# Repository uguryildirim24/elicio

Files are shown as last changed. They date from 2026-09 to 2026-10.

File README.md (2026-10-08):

# Elicio

Elicio is an unfinished ear-muscle EMG earpiece that is intended to turn a deliberate contraction into a gated event before an AI acts.

Rolf chose a discreet physical input rather than an always-active command channel. The sensor should propose an event. Policy should decide whether that event can act. Sensing, permission and execution remain separate.

```text
ear-muscle EMG -> decoder -> (symbol, confidence, timestamp) -> policy -> action
```

**The board is not finished, has not been ordered and is unmeasured.** No physical earpiece, real ear-muscle recording or end-to-end biological action has been validated. The runnable demonstrations use synthetic input. Only a harmless local file action is real. No AI execution adapter is implemented.

## What exists

| Part | Files and present evidence |
| --- | --- |
| Flex board | [KiCad schematic](hardware/board/elicio-v4.kicad_sch), [routed PCB](hardware/board/elicio-v4.kicad_pcb), project rules and generation/routing scripts. Design files are not manufacturing approval. |
| Scripted shell | [Selected snap-shell exports](docs/fab/cad/v4-snap/) include STEP, STL, 3MF and a nominal-check manifest. No print, fit or retention result. |
| Firmware | [Arduino stream firmware](firmware/elicio_stream/elicio_stream.ino) and C sources for ADS1292 acquisition, binary BLE frames and undervoltage handling. The product Arduino variant is missing. |
| Receiver | Binary frame decoding, dropout/loss records and session files. Committed synthetic transport fixtures run without a radio. |
| Action gate | Confidence policy, confirmation state, intent/result auditing and an atomic local marker write. Other action names are console simulations. |
| Research pipeline | Public forearm sEMG preparation and cross-session evaluation code. No result CSVs, checkpoints or measured accuracy reports are bundled. |

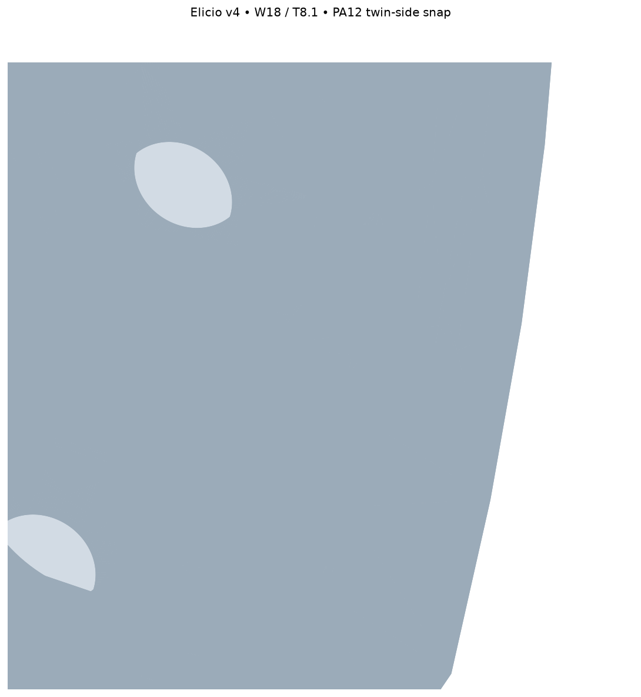
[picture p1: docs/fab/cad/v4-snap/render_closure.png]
Selected snap-shell CAD preview, not a physical device


The snap manifest records **106 passing nominal geometry checks**. These cover simplified board courtyards, a folded-flap envelope, seated overlap, key clearance and opposing tolerance offsets. They do not prove printed fit, latch fatigue, component loads, electrical safety or RF range. The nominal body is 18 mm wide and 8.1 mm thick, not the complete hook bounding box. See [shell limits](docs/fab/shell-v4.md) and [board blockers](docs/fab/board-v4-design.md).

## Run from a clean clone

Run these commands from the repository root on macOS or Linux. Use Python **3.11 or newer**. The base install requires NumPy. No credentials or hardware are needed for the demos.

```bash
python3 --version
python3 -m venv .venv
.venv/bin/python -m pip install -e .
.venv/bin/elicio demo --state-dir .elicio-demo
.venv/bin/elicio replay-demo --state-dir .elicio-replay-demo
```

Each demo must exit 0 and print `"verified": true`. It writes a marker under `actions/` and linked `intent` and `result` records in `audit.jsonl` inside its ignored state directory. The replay fixture is seeded synthetic data, not an EMG recording or a hardware test.

### Binary receiver without hardware

```bash
.venv/bin/elicio receive --simulate tests/fixtures/receiver_v2/normal.json \
    --out recordings/synthetic-session
.venv/bin/elicio receive-check recordings/synthetic-session
```

`receive` writes `samples.npz`, `sidecar.json` and `meta.json`. `receive-check` reports acquisition statistics and criterion status; the normal fixture exits 0 with `"ok": true`. Its gesture criteria are `not_scored`, not passed. This is transport validation, not gesture decoding or a connection to the action gate.

The intended radio path uses binary frame-v2 messages over Nordic UART Service, not ASCII serial samples. Live reception requires the optional BLE dependency and future functioning hardware:

```bash
.venv/bin/python -m pip install -e '.[ble]'
.venv/bin/elicio receive --device ELICIO --seconds 10 --out recordings/bench-session
.venv/bin/elicio receive-check recordings/bench-session
```

The live commands are not usable or validated with this unfinished board. The firmware deliberately rejects a Feather pin variant. See [firmware limits](docs/fab/firmware-v2.md), [frame format](docs/fab/frame-v2.md) and [receiver contract](docs/fab/receiver-v2.md).

The separate `scope`, `capture` and `replay-recording` tools accept one ASCII sample per line from a file, stdin or an already configured serial device. They are bench utilities, not the binary BLE path. Store captures under ignored `recordings/`, for example `--out recordings/session.json`. Run `elicio capture --help` for the sample-rate, offset and gain arguments.

### Existing tests

```bash
.venv/bin/python -m unittest discover -s tests -v
```

The scope review ran the base install, both synthetic action demos and the normal receiver fixture in the worktree with Python 3.13.15. They exited 0. Both demos reported `verified: true`; the receiver check reported `ok: true` with gesture criteria unscored.

The full existing suite was attempted but stopped at a 180-second command limit while setting up the restored packing checks. A historical document wording assertion failed before that point. Its expected reference wording was restored, and that existing test passed when rerun alone. The documented `bte_fit_shell.py --checks-only` reference check and `elicio capture --help` also passed. No complete suite pass is claimed. The original tests and historical-byte comparisons remain unchanged. No tests or CI were added.

Optional dependency groups are `research`, `ble`, `cad` and `sheets`. Install an extra with, for example, `.venv/bin/python -m pip install -e '.[cad]'`. Native C checks use a compiler when available. KiCad/pcbnew, firmware tooling, Blender or SceneKit are separate toolchains. Optional CAD exports, rendering, KiCad release validation, firmware flashing and live acquisition were not rerun during the scope review. Research downloads and training were skipped as substantial workloads.

## Research and local data

The research package fetches public PhysioNet/WFDB GRABMyo records. It studies forearm gestures, not auricular decoding. From the repository root:

```bash
.venv/bin/python -m pip install -e '.[research]'
.venv/bin/elicio-emg prepare --subjects 1 2 3 --out-dir results
.venv/bin/elicio-emg train --data-dir results --subjects 1 2 3 \
    --epochs 20 --out results/train_results.csv
.venv/bin/elicio-emg evaluate --data-dir results --subjects 1 2 3 \
    --epochs 20 --out results/six_best_rest.csv
```

These are download and training workloads, not quick demos. They were not rerun during cleanup. Training is not fully seeded. Evaluation uses separate recording sessions and a leakage guard. Earlier imported accuracy summaries lack supporting result artifacts here and are not claimed as repository results. See the [pipeline instructions](src/elicio/pipeline/README.md) and [provenance limits](docs/RESEARCH_PROVENANCE.md).

Keep raw recordings in `recordings/`, research outputs in `results/`, anatomy parameters in `measurements/` and generated CAD/release output in `.reports/`. These directories, environments, checkpoints, secrets and runtime state are ignored. Tracked binary fixtures are synthetic. No completed personal ear measurements or purchase records are included. Do not put delivery addresses, checkout details or credentials in public examples.

## Limits and next steps

- Confidence thresholds are policy settings, not calibrated biological probabilities.
- The timed `jaw_clench` confirmation rule checks symbols, confidence and timestamps. The event tuple cannot prove that command and confirmation came from independent muscle groups. That is an unvalidated upstream requirement.
- Intent audit failure blocks execution. A result-audit failure after execution is reported without hiding the completed action.
- There is no trained ear-muscle decoder, real signal-to-action result or AI execution adapter.
- The circuit, cell, charging protection, RF keep-out, programming path and manufacturing acceptance remain open. CAD and a clean DRC claim cannot establish on-body safety.
- This is not a medical device or a finished wearable. Do not wear or charge unvalidated electronics on a body.

Next: resolve electrical and fabrication blockers, implement the product firmware variant, validate passive printed fit and repeated latch retention, then record a real signal and demonstrate one harmless audited action. See [design status](docs/EARPIECE_DESIGN.md) and [open gates](docs/fab/open-questions.md).

## Project layout

| Path | Purpose |
| --- | --- |
| `src/elicio/harness/` | Events, policy, adapters and audit |
| `src/elicio/signal/` | Synthetic replay, detection and ASCII capture |
| `src/elicio/frame_v2.py`, `receiver_v2.py` | Binary BLE transport and session reception |
| `src/elicio/pipeline/` | Public-data research pipeline |
| `hardware/board/` | KiCad sources, custom footprints and board scripts |
| `firmware/` | Acquisition, framing and power-state sources |
| `scripts/cad/`, `scripts/sheets/` | Parametric CAD, previews and reference templates |
| `docs/fab/cad/v4-snap/` | Selected shell candidate and nominal evidence |
| `tests/` | Existing unit checks and synthetic transport fixtures |
| `docs/` | Design limits, provenance and engineering references |

Older v1/v2 geometry, packing tables, layout searches, board-edit scripts and their existing checks remain. They are reference inputs and development tools, not active ordering instructions. `placement.py` still supports `--packing-doc`, `--layout-v2` and `--layout-v2c`. Some older readers use pinned Git revisions. They are not independent of repository history, and history scrubbing can invalidate those references. The technical L1 to L8 source surveys remain with historical notices. The [reference index](docs/fab/references.md) lists key public sources. Task and review dialogue is omitted.

The rejected M1.6 closure remains as diagnostic code and evidence in `docs/fab/cad/v4-m16/`. It is not suitable for printing. The snap candidate is still untested physically. Private agent diaries, personal parameter scaffolding and superseded shopping sheets were removed. Historical budgets are estimates, not quotes or personal spending statements.

## How this was built

AI coding agents did much of the research migration, harness and receiver implementation, firmware, CAD and board work under Rolf's direction. Rolf set the physical-gating goal, chose the earpiece form, titanium contacts, limited final assembly and off-ear-only charging, and reviewed design previews. The checks reported here are automated software and nominal geometry checks. Agent-written engineering claims are not independent electrical review or physical measurements. No hardware result has been measured.

## License and citation

Original project code, hardware design files and documentation are offered under [MIT](LICENSE). The bundled Liberation Sans font is separate: SIL Open Font License 1.1, with Google and Red Hat attribution in [the font notice](scripts/cad/fonts/OFL.txt). External datasets, dependencies and vendor materials retain their own terms.

No Elicio paper or preprint is included in this repository. Public engineering source pointers are in [references](docs/fab/references.md).

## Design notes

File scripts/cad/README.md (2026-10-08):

# Scripted shell CAD

The selected candidate is the committed `docs/fab/cad/v4-snap/` body and lid. The board is unfinished and unordered. No shell has been printed or fit-validated.

## Install and generate

From the repository root with Python >=3.11:

```bash
python3 -m venv .venv
.venv/bin/python -m pip install -e '.[cad]'
.venv/bin/python scripts/cad/build_shell_v4.py --closure snap --out .reports/cad/v4-snap
.venv/bin/python scripts/cad/render_v4.py --single --out .reports/cad/v4-snap
```

All generated output belongs under ignored `.reports/cad/`. Do not overwrite tracked reference exports during routine checks. The CAD extra pins the kernel used for geometry exports. Library versions can still change render bytes. Regeneration is not physical validation.

`build_shell_v4.py` reads board courtyard envelopes from `docs/fab/board-v4-design.md` section 10.2. Its manifest records nominal geometry and key-clearance checks. The base `--closure hinge` is a reference without lid retention. `--closure m16` remains a diagnostic prototype. Its 0.13 mm head-well wall rejects it for printing. Committed M1.6 exports remain as evidence, not a print candidate.

See [shell limits](../../docs/fab/shell-v4.md) for print and load questions.

## Reference fixtures

`bte_fit_shell.py`, `placement.py`, `placement_v2.py` and `layout_v2c.py` retain the original construction, packing searches and document generator. The older PCB reader uses revision `70adfa6` for board dimensions and project rules. J4 geometry prefers revision `6860a54`. Shell readers prefer pinned packing revisions. These are read-only Git operations, but the inputs depend on history. A history rewrite can invalidate them. They must not be replaced by a later PCB without checking the changed geometry and rules.

The v1/v2 solids, matrix drawings, v2c grid drawings and packing tables remain reference inputs. The earlier shell reader combines section 5c courtyards and holes with section 5d folded pads and extras. Section 5e supplies the later wall-site geometry. The v4 generator reads `board-v4-design.md`, not either older placement table. Superseded fit-gauge ordering instructions do not define the current build. Historical technical source surveys L1 to L8 remain. `docs/fab/references.md` indexes key sources. Private task and review dialogue is not included.

`placement.py` retains `--packing-doc`, `--layout-v2` and `--layout-v2c`. The first regenerates tracked `docs/fab/packing-v2.md`; the grid option writes its reference drawings. Run these only when deliberately regenerating the references. Matrix drawing options are `--all`, `--kept-drawings` and `--all-drawings`, with `--out-dir` for a separate output directory. The full grid and document searches can be lengthy.

Existing tests still compare regenerated CAD and render bytes with committed hashes. Kernel versions, Git provenance and rendering dependencies can affect those comparisons. The scope review did not weaken those checks or claim a complete suite pass.

A reference-only check without the CAD kernel:

```bash
.venv/bin/python scripts/cad/bte_fit_shell.py --checks-only
```

A new reference export, with the CAD extra installed:

```bash
.venv/bin/python scripts/cad/bte_fit_shell.py --out .reports/cad/reference
```

The default M1 to M8 dimensions are examples. They are not Rolf's measurements. Put any later anatomy overlay under ignored `measurements/`, then pass its path through `--params`. Do not fill a tracked parameter file with personal measurements. Check supported parameters with `--help`. The full v4 folded fit must be re-evaluated after parameter changes.

## Optional assembly visualizations

`assemble_native.py` uses SceneKit/Swift on macOS or Blender on Linux. It also needs Pillow. It reads the committed shell STL and board data and generates simplified curved board and package envelopes, not a folded physical assembly.

```bash
.venv/bin/python -m pip install Pillow
.venv/bin/python scripts/cad/assemble_native.py --out .reports/cad/assembly
```

`assemble_photo.py` provides a Blender render path. Rendering also uses read-only git provenance. These pictures do not prove clearances, package tolerances, RF performance or manufacturability. Preview generation was not rerun during publication cleanup.

## Font

`fonts/LiberationSans-Regular.ttf` is bundled for CAD embossing. Its separate SIL Open Font License 1.1 and attribution are in `fonts/OFL.txt`. The project MIT license does not replace that notice.

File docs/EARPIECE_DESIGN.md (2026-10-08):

# Earpiece design status

Elicio is Rolf's unfinished behind-the-ear EMG earpiece. The board has not been ordered. No assembled hardware, real recording, on-body result or validated charging interface exists.

## Current candidate

| Part | Files | Evidence and limits |
| --- | --- | --- |
| Two-layer flex board | `hardware/board/elicio-v4.kicad_sch`, `.kicad_pcb`, `.kicad_pro`, `.kicad_dru` | Routed design snapshot. Manufacturing, electrical and supply checks remain open. |
| Shell | `docs/fab/cad/v4-snap/` | STEP, STL, 3MF, preview and nominal geometry checks. No printed fit or retention test. |
| Base shell | `docs/fab/cad/v4/` | Reference geometry with a hinge only. It does not retain the lid. |
| Firmware | `firmware/elicio_stream/elicio_stream.ino`, `firmware/src/` | ADS1292 acquisition, binary BLE framing and undervoltage logic. Product Arduino pin variant is missing. |
| Receiver | `src/elicio/receiver_v2.py` | Synthetic frame decoding, loss handling and session output. No live radio validation. |
| Action gate | `src/elicio/harness/` | Synthetic event and replay demonstrations with a real local file action. No AI adapter. |

The proposed board uses an ISP1807-LR radio module, ADS1292 front end, BQ25100 charger and a fitted protected cell. The selected shell has a nominal 18 mm body width and 8.1 mm body thickness. These are CAD dimensions, not measurements of a worn device. See [board design](fab/board-v4-design.md) and [snap-shell status](fab/shell-v4.md).

## Engineering constraints

Rolf selected discreet auricular muscle input rather than an overt forearm gesture as the intended product interface. Forearm data remains a research and bench-development path, not a validation of the earpiece.

The contact hardware is specified as titanium. Material, finish, pressure, insulation and retention still need review. Shell parameters are reference examples, not personal anatomy measurements. Keep any later measurements under ignored `measurements/`.

Charging is intended to happen off-ear only. The proposed fixed TS resistor disables cell-temperature sensing. Firmware inhibits are not galvanic isolation. Series resistors alone do not establish safe fault currents or medical compliance. Do not connect unvalidated electronics to a body. Bench electrical checks and qualified safety review must precede on-body work.

## What is not implemented

- A product-specific Arduino variant and verified bootloader/programming path.
- Validated battery pack, polarity, charge cable, temperature conditions and transient protection.
- Physical shell fit, repeated snap operation, contact stability and RF range.
- A trained auricular decoder or a measured independent confirmation channel.
- Ear-canal pressure sensing or EEG acquisition. These were exploratory ideas, not built subsystems.
- Real AI execution. Only the local marker adapter changes a file.

## Next steps

1. Review the actual routed board, component supply, charging protection and fabrication constraints. Re-run KiCad release validation after any change. Resolve the blockers in [open questions](fab/open-questions.md).
2. Implement the ISP1807 product firmware variant. Verify GPIO mapping, first-load voltage levels, acquisition timing and the hardware interlock on the bench.
3. Evaluate a passive shell print. Check fit, latch access, repeated retention and contact positions before including powered electronics.
4. After electrical and physical review, preserve a real raw recording in ignored `recordings/`. Show one contraction producing one harmless marker action with linked audit records.

Historical v1/v2 geometry and packing tables remain because the current generator and existing checks depend on them. They are references, not alternative checkout instructions. Superseded order sheets have been removed. Rejected M1.6 closure code and exports remain as diagnostic evidence, not a fabrication candidate.

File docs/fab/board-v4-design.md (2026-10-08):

# Board v4 — design note (smaller body)

Draft. **Routed, not orderable yet**: DRC 0 errors and 0 unconnected after a zone refill, and `scripts/board/release.py --board elicio-v4 --routed` passes (§9), but some parts still require verified external supply (`bom-v4-orderable.md`). U3 now has DC-bias-characterized IN/TS/OUT capacitors meeting the numerical IEC rating conditions, but D1 still clamps at the far end of VBUS and the nearest OUT bulk is 9.3 mm from U3; the conditional IC rating is not a contact-level test (§2.1). Rolf chose off-ear-only charging with fixed TS and a two-wire J2 (no cell NTC); the antenna keep-out still needs his decision (§4.2). The later built snap shell is a print-trial solid, not a verified fit; see `shell-v4.md`. §11.1 lists what is still UNVERIFIED.
Design snapshot: 2026-09-25. AI coding agents produced the design and routing records under Rolf's direction. Reported KiCad release counts below are historical claims, not a freshly reproduced manufacturing release. The board is unfinished and has not been ordered.

## 1. Size levers

Frame: u = width (anterior 0 → posterior), s = arc from the hook end, y = thickness from the skin face. All sizes in mm. Flat PCB (x, y) = (u, s).

Baseline v2: W 22, T 9.0 (LID_Y 8.0 + lid 1.0), chord 47.90. The M1 gate is M1 ≥ chord + 3 = 50.9. Default M1 is a 52 mm reference example, not a personal measurement.

"W/L/T saved" is the body dimension saved. Where a lever only frees board area, the area is given instead, as courtyard mm². The area levers together are what let the island shrink from 17.5 to 13.5 wide.

### 1.1 Lever table

| # | Lever | W saved | L saved | T saved | What Rolf gives up | Risk | Cost change | Taken |
|---|---|---|---|---|---|---|---|---|
| L1 | Clear the pocket beside the cell. U2, SW1 and J2 move onto the island. P4/P5 become one-face wall rings on a plate that folds 90° beside the cell (§4.4) | **4.0** (22 → 18) | 0 | 0 | Nothing electrical. Shell changes: a slot in the rib for the flap, and the closure screw moves (§7) | The 90° fold at R 1.1 is exactly JLC's 10× limit. Plate top 6.895 against LID_Y 7.1 | Shell reprint (needed anyway). Board: UNVERIFIED | **Yes** |
| L2 | ISP1807-LR SiP (8 × 8 × 1.0) replaces the Raytac MDBT50Q (15.5 × 10.5 × 2.3) | makes L1's 13.5-wide island possible (courtyard 190 → 74 mm²) | 0 | **0.62** (a Raytac on the v4 island would need T ≈ 8.72) | RF margin: about 13 mm of metal-free edge against the 18 recommended (§4.2). Not in the JLC library, so it must be consigned. No VDDH, so U5 is added | Range is UNVERIFIED until a range test. 0.65-pitch LGA on flex | $14.01 (-ST) / $13.65 (-RS) qty 1, Mouser, https://www.mouser.com/ProductDetail/Insight-SiP/ISP1807-LR-ST, read 2026-09-23. Raytac price UNVERIFIED. Consignment fee UNVERIFIED | **Yes** |
| L3 | Island stiffener FR4 0.4 → 0.2 (one B-side piece under U1, the P2 landing and J4) | 0 | 0 | **0.28** | Nothing | Less stiffness under the lid posts and at the LGA. G7 load not computed | None expected. Stiffener fee: §3.3 | **Yes** |
| L4 | J2: JST-SH (mated 2.95) → Molex Pico-EZmate Slim 202656-0021 (mated 1.20, top entry) | lets J2 sit on the island (part of L1) | 0 | lets J2 fit under LID_Y 7.1 (top 6.32; SH would reach 8.07) | The cell must come with a Pico-EZmate Slim plug fitted by a vendor. R2 forbids Rolf crimping. This changes the G1b/Q69 purchase route | Supply of a cell with that plug is UNVERIFIED | Header and plug prices UNVERIFIED. Not in the JLC library | **Yes** |
| L5 | SW1: TS-1187A (4.5 × 4.5 × 1.6) → HRO 1TS015A (3.0 × 2.0 × 0.6) | area about 42 → 11 mm² | 0 | 0 (top 5.72) | Nothing (1.2 N press) | Low | C398746, 25,177 in stock (https://jlcpcb.com/partdetail/C398746, read 2026-09-23). Price UNVERIFIED | **Yes** |
| L6 | Non-Contact R and C 0402 → 0201. 10 µF 0603 → 0402 | area about 40 mm² (35 parts) | 0 | 0 | Nothing | JLC lists FPC assembly and a 0201 minimum separately. That the two combine on FPC is UNVERIFIED | +$3.00 per new extended part number (L8 §2.2, read 2026-09-18). About 6–12 new lines gives +$18–36 (UNVERIFIED) | **Yes** |
| L7 | Q1–Q4 SOT-23 → DFN1006-3. U4 SOT-23-5 → X2SON-4 | area about 57 mm² | 0 | 0 | Nothing | Q2–Q4 are PMZ290UNE2 (C478155, §2.1 item 4). U4 C2863576 is the same regulator on reel and stocked | Q1 WPM3027-3 C240195. The rest UNVERIFIED | **Yes** |
| L8 | Lid posts replace the two board screws and bosses (H1/H2 go) | area about 17 mm² | 0 | 0 | Nothing. Assembly step 5 ("Turn the board screws") goes | The P2 post presses on U1's top. Force not computed (G7) | None | **Yes** |
| L9 | Drop the DNP parts and the part the SiP makes redundant (Q5, R9, R10, R29, R30, L1) | area about 21 mm² | 0 | 0 | The option to fit R29/R30 lead-off bias later | None | None | **Yes** |
| L10 | Drop R26 (nRESET 10 kΩ pull-up). P0.18 set as RESET has its own pull-up (PS v1.11 §5.3.8.3 tPINR = 5 × 13 kΩ × C; §7.3 reference circuits have no reset resistor) | area about 0.6 mm² and one via | 0 | 0 | Nothing. Firmware must set UICR PSELRESET (§8) | Low | −1 BOM line | **Yes** |
| L11 | Via 0.45/0.20 → 0.40/0.15 (JLC flex standard: hole ≥ 0.15, pad ≥ 0.35, 0.40 recommended) | routing room, not courtyard | 0 | 0 | Nothing | Low: still the standard via | None expected | **Yes** |
| N1 | W16: ISO 4032 M2.5 nuts (m 2.0) replace the 3.0 P4/P5 standoffs | 2.0 (18 → 16.01) | 0 | 0 | Routability. The island would be 11.5 wide | High: W17 already fails to place (N14) | Nut price UNVERIFIED | No |
| N2 | 401012 cell (4.2 × 10.2 × 13.5, 40 mAh) replaces the 501012 | 0 | −0.5 (chord 48.40, M1 ≥ 51.4) | 0.5 (T ≈ 7.6) | 0.5 of length. Same capacity | LID_Y 6.6 is set by the P4/P5 hex (AF 5.0 between floor 1.5 and lid, 0.05 spare each side) and by J2 (6.32 + 0.28). The plate needs a re-cut (plate top 6.895 > 6.6), putting the ring at y ≈ 4.05. The shell must confirm. The cell has flying leads, so the plug must be fitted | €2.74 qty 1, https://ampul.eu/en/battery/6411-li-pol-battery-40mah-37v-401012, read 2026-09-23. Compare 501012 ~$3.50–5.00, https://www.aliexpress.us/item/3256804164251088.html, read 2026-09-23 | Rolf's option |
| N3 | 301012 cell (3.2 × 10.2 × 13.5, 25–30 mAh) | 0 | −0.5 | 0.5 (still 7.6: the hex and J2 set LID_Y) | 10–15 mAh (§1.3) | As N2 | $3.20, https://www.aliexpress.us/item/3256808874133671.html, read 2026-09-23 | No: a pure loss against N2 |
| N4 | 401010 cell (4.2 × 10.2 × 11.5, 30 mAh) | 0 | **1.5** (chord 46.40, M1 ≥ 49.4) | 0.5 (T ≈ 7.6) | 10 mAh (§1.3) | As N2 | $10.00, https://lipolybatteries.com/product/30mah-lipo-battery-lp401010-4mm-thickness-3-7-v-battery, read 2026-09-23 | Only if M1 < 50.9 |
| N5 | T ≈ 7.4: M2 P4/P5 hardware, Hirose DF58 J2 (mated 1.00) and a cell ≤ 4.2 | 0 | per cell | about 0.7 | A second hex key, which breaks plan R2 | New hardware and connector sourcing | UNVERIFIED | No (R2) |
| N6 | Foam 0.5 → 0.3 (plan v2 §3's number; decision 57 chose 0.5) | 0 | 0 | 0.2 (T 7.9) | Cushion under the cell | Plate top 6.895 against LID_Y 6.9: needs a plate re-cut | None | No (decision 57 stands) |
| N7 | 2.0 standoffs at P4/P5 | 0 | 0 | 0 on its own | — | SKU UNVERIFIED (plan §3 verified only 3.0 and 4.0) | UNVERIFIED | No |
| N8 | Full 18 mm antenna keep-out | 0 | **−5** (M1 +5) | 0 | 5 mm of body length | — | — | No: range test instead |
| N9 | ADS1291 (1 channel) | 0 | 0 | 0 | Channel 2: **changes function** | Same RSM 4 × 4 package, so no size gain | C2651548 $12.3149, 1 in stock, https://jlcpcb.com/partdetail/C2651548, read 2026-09-23 | No |
| N10 | MAX30003 (2.74 × 2.93 WLP) | area only | 0 | 0 | 512 SPS max, 18-bit: **changes function** | — | DigiKey page in research §3.3 | No |
| N11 | nRF52840 on the board, not in a module (WLCSP 3.544 × 3.607) | area only | 0 | 0 | The module's certification (FCC ID) | Antenna, crystals and matching on the board. The Johanson 2450AT18A100 needs a 9.5 × 6.2 ground clearance | — | No |
| N12 | u-blox ANNA-B402 (6.5 × 6.5 × 1.2, nRF52833) | area only; needs a host antenna strip and a 32 kHz crystal | 0 | −0.2 against the ISP1807 | Moves from nRF52840 to nRF52833 | The antenna strip takes back the area | $7.22 qty 1, https://www.digikey.com/en/products/detail/u-blox/ANNA-B402-00B/13684241, read 2026-09-23 | No |
| N13 | 4-layer flex | 0 | 0 | 0 | — | 0.20+ thick breaks the R 1.1 and R 1.5 folds (static bend ≥ 10× thickness) | — | No |
| N14 | W17 (the first pick) | 1.0 (18 → 17) | 0 | 0 | Nothing electrical | **Tried; it doesn't place.** B-side room is the limit, not total area (§1.4) | — | No |

### 1.2 Thickness chain

| y top | v2 | v4 (501012) |
|---|---|---|
| Floor | 1.50 | 1.50 |
| Ring (PI 0.11 + FR4 0.2) | 1.81 | 1.81 |
| Standoff 3.0 top = island underside | 4.81 | 4.81 |
| Island stiffener | FR4 0.4 → 5.21 | FR4 0.2 → 5.01 |
| Island PI top | 5.32 | 5.12 |
| Module top | 7.62 (Raytac 2.3) | 6.12 (ISP1807 1.0) |
| J2 mated top | pocket beside the cell | 6.32 (1.20 on the island) |
| SW1 top | pocket | 5.72 |
| Cell: floor 1.5 + foam 0.5 + cell | 7.10 (501012) | 7.10 (501012) |
| LID_Y | 8.00 | **7.10** (set by the cell) |
| T = LID_Y + lid 1.0 | 9.0 | **8.1** |

A Raytac on the v4 island would top out at 7.42. With 0.3 clearance that is T ≈ 8.72, so the ISP1807 saves 0.62 and the thinner stiffener the other 0.28.

### 1.3 Hours of wear (estimate, UNVERIFIED)

The historical runtime model assumes about 7 mA average load. That assumption has no measured current trace or runtime report here. The table is capacity divided by an assumed load, not a result.

| Cell | mAh | Hours at ~7 mA |
|---|---|---|
| 501012 / 401012 | 40 | ≈ 5.7 |
| 401010 | 30 | ≈ 4.3 |
| 301012 | 25–30 | ≈ 3.6–4.3 |

Montage S3 wear is ≤ 4 h/day.

### 1.4 The pick

**W 18, T 8.1, chord 47.90 with the 501012 cell. Needs M1 ≥ 50.9.**

- **W 18** is the narrowest width I could place with every part and a via escape for each B-side net (§6).
  - **W17 was the first pick and failed at placement.** Total fill looked fine (71.4%), but the B side is mostly keep-out: the P1 landing (R 3.2), the U1/P2/J4 stiffener (no B parts) and the RF band (all layers). What's left at W17 is a 3.4 × 4.85 pocket, the area under U2 and a strip along the −s edge. The seven divider and interlock parts (R16, R18–R21, Q2, C14) didn't fit there with room for their vias.
  - The extra 1.0 goes to the posterior column, u 14.75–15.75. That holds R3, R16, the charger on B and the Contact/J3 corridor.
  - W16 needs nuts in place of the P4/P5 standoffs and has less room than W17 (N1).
  - The contacts alone set W ≥ 15.0: the P2 well at u 10.4, plus 3.06, plus a 1.5 wall.
- **T 8.1** is set by the cell stack (1.5 + 0.5 + 5.1 = LID_Y 7.1). Nothing on the island is taller than 6.32.
- **L** is unchanged, so the default M1 52 clears with 1.1 to spare.
- **Against v2:** W −4.0 (−18%), T −0.9 (−10%).

**Options for Rolf:**

- **W16/W17:** not offered. W17 doesn't place; W16 has less room still.
- **Thinner cell (401012):** T ≈ 7.6, chord 48.40, M1 ≥ 51.4, €2.74 against ~$3.50–5.00. Gives up 0.5 of length and all but 0.05 of the P4/P5 hex margin. Needs a plate re-cut and shell confirmation. Same 40 mAh.
- **301012:** the same T 7.6 with 10–15 mAh less. Not worth it.
- **401010:** T ≈ 7.6 and L −1.5 (M1 ≥ 49.4) for 30 mAh at $10.00. Only if M1 turns out < 50.9.

## 2. Parts: keep, change, remove

v2 list from the v2 netlist (board-v2.md G2/BOM). v4 list from `hardware/board/v4_parts.py`.

| v2 | v2 part | v4 | Action | Note |
|---|---|---|---|---|
| U1 | MDBT50Q-1MV2, C5118826 | ISP1807-LR-RS | change | Same nRF52840. Antenna, crystals and DC/DC inside. No LCSC code: consign |
| U2 | ADS1292IRSMT, C89288 | same | keep | ADS1291 considered: same package, loses channel 2 |
| U3 | BQ25100YFPR, C527572 | same, courtyard cut to ±0.8 × ±1.06 (`Texas_YFP0006_V4`), **CONSIGNED** | keep | C527572 has 0 stock; A is 4.30 V, B has only 6 stock and is not listed in TI SLUSBV8C (§2.1). Exact YFPR marked InStock at TI; quantity not exposed (`bom-v4-orderable.md`) |
| U4 | TLV71330PDBVR SOT-23-5, C2863702 | TLV71330PDQNR X2SON-4, C2863576 | change | Same regulator and DQN pinout, R rather than T tape; 990 in stock |
| — | — | U5 TPS7A0230PDQNR, X2SON-4, C2867950 | **add** | +VDD 3.0 V from VBAT; 25 nA Iq; 385 in stock |
| — | — | C16 1 µF 0201 on VBAT | **add** | U5 input |
| L1 | 10 µH 0603, C1045 | — | **remove** | Stops nothing: DCCH is not brought out; the SiP carries its own DC/DC parts |
| Q1 | AO3401A SOT-23, C15127 | WPM3027-3 DFN1006-3, C240195 | change | Vgs(th) max −1.0, 800 mΩ max at −2.5 V |
| Q2–Q4 | 2N7002 SOT-23, C2128 | Nexperia PMZ290UNE2YL DFN1006-3 (SOT883), C478155 | change | Refcheck t-0023 (§2.1). Pin 1 G, 2 S, 3 D, as the SOT-883 land |
| Q5 | 2N7002, DNP | — | **remove** | Stops nothing: DNP, BAT_MEAS_EN was never driven |
| D1 | PESD5V0L1UL SOD-523, wrong C24109 | PESD5V0L1UL SOD882, C3001948 | change land | Same TVS, 7525 in stock; pad 1 cathode on VBUS |
| D2 | LED 0402, wrong 0603 C72043 | Lite-On LTST-C281TGKT-5A 0402, C364549 | keep land | Green, 2.5–3.1 V Vf; R22 1 kΩ gives 1.9–3 mA at VBUS 5–5.5 V (using forward-voltage range). Pad 1 cathode on CHG_LED_K |
| J2 | SM02B-SRSS-TB, C160402 | Molex 202656-0021 Pico-EZmate Slim | change | Mated 1.20. Not in the JLC library. The cell needs the matching plug (L4) |
| J3 | HDR-3-RA, C49257 | same, on a break-off tab behind R31–R33 | keep | Q91. Pin order as v2 (J3.1 SIG1 side, J3.2 SIG2, J3.3 REF). Each pin has its own 220 kΩ on the tab (§5.4) |
| J4 | TC2030-NL | same | keep | Not in BOM |
| SW1 | TS-1187A, C318884 | HRO 1TS015A, C398746 | change | 3.0 × 2.0 × 0.6 |
| P1–P3 | RING_PAD_D5_H2.7 | same | keep | |
| P4, P5 | RING_PAD_D5_H2.7 on the CHARGE tab | RING_1S_D4.6_NPTH2.7, copper on B only | change | Wall rings (Q90) |
| H1, H2 | island holes Ø2.7 | — | **remove** | Stops nothing electrical. Lid posts hold the island (§5.3) |
| R1–R3 | 220 kΩ 0402, C881401 | same | keep | Contact, not shrunk |
| — | — | R31–R33 220 kΩ 0402, C881401 | **add** | The bench header's own 220 kΩ per pin (R7), on the break-off tab; they leave with it |
| R4, R17, R20, R21 | 1 MΩ 0402, C26083 | 0201, C473482 | change | |
| R5–R8, R13, R25, R27, R28 | 10 kΩ 0402, C25744 | 0201, C473048 | change | R13 stays a fixed 10 kΩ on TS: no flex copper touches the cell for an NTC (§2.1) |
| — | — | R34, R35 10 kΩ 0201, C473048 | **add** | U2 GPIO1/GPIO2 to GND (refcheck t-0023, §2.1) |
| R26 | 10 kΩ 0402, nRESET pull-up | — | **remove** | Stops nothing: P0.18 as RESET has its own pull-up (L10). Firmware sets UICR PSELRESET (§8) |
| R9, R10 | 5.1 kΩ, DNP | — | **remove** | Stops nothing: USB-C CC with no receptacle (Q81, Q95) |
| R11 | 6.80 kΩ 0402, C25917 | 0201 0201WMF6801TEE, C423451 | change | 1% thick film, ISET unchanged (≈ 19.85 mA) |
| R12 | 6.04 kΩ 0402, C966759 | 0201, C270341 | change | |
| R14–R16, R23, R24 | 100 kΩ 0402, C25741 | 0201, C270364 | change | |
| R18 | 47 kΩ 0402, C25792 | 0201 0201WMF4702TEE, C270345 | change | 1% thick film; VBUS_DET only VBUS sense |
| R19 | 27 kΩ 0402, C25771 | 0201 0201WMF2702TEE, C270351 | change | 1% thick film |
| R22 | 1 kΩ 0402, C11702 | 0201, C270365 | change | |
| R29, R30 | 10 MΩ, DNP | — | **remove** | Stops nothing now: lead-off stays firmware-off (plan §5.5). The land to fit them later is gone |
| C1 | 1.5 nF 0402, C1548 | 0201, C285104 | change | |
| C2 | 10 nF 0402, C1524 | 0201 TCC0201X7R103K500ZT, C5142551 | change | 50 V X7R ±10%, same dielectric/rating |
| C3 | 1 µF 0402, C15849 | 10 µF 0402 X5R 10 V Murata GRM155R61A106ME18D, C36626211 | change | IN effective 2.277 µF at 5 V (§2.1); D is tape suffix |
| C4–C5, C10, C13 | 1 µF 0402, C15849 | 0201, C5142566 | change | |
| C6, C8, C9 | 10 µF 0603, C19702 | 0402, C15525 (Basic) | change | |
| C7, C15 | 100 nF 0603, C14663 | 0201, C307380 | change | |
| C11 | 100 nF 0402, C1525 | 1 µF 0201, C5142566 | change | VCAP2 (refcheck t-0023, §2.1) |
| C12 | 100 nF 0402, C1525 | 0201, C307380 | change | |
| — | — | C17 100 nF 0201, C307380 | **add** | VREFP local bypass beside C9 (refcheck t-0023, §2.1) |
| C14 | 4.7 µF 0402, C19675 | 10 µF 0402 X5R 10 V Murata GRM155R61A106ME18D, C36626211 | change | OUT effective 2.781 µF at 4.2 V (§2.1); 9.3 mm from U3 |
| — | — | C18 10 µF 0402 X5R 10 V Murata GRM155R61A106ME18D, C36626211 | **add** | TS to GND, fixed R13 unchanged |
| — | — | C19 10 µF 0402 X5R 10 V Murata GRM155R61A106ME18D, C36626211 | **add** | Extra OUT bulk; far from U3 |

J1 (USB-C) and USBLC6 were already absent in v2 (Q81).

v4 placement: 64 parts plus P1–P5. On the island, 25 are on F (J4 included) and 35 on B; J3, R31 and R33 are on the tab and R32 on its neck. J4 and P1–P5 are not in the BOM, which leaves 63 lines.

**No removal changes function.** Every removed part was DNP, or is replaced by the SiP (L1), by the lid posts (H1/H2) or by the nRF's own reset pull-up (R26). The charger, charge interlock, AFE supply gate, VBUS_DET, VBAT_SENSE, CHG_MON, LED, SW1, J3 and J4 all stay.

### 2.1 Refcheck t-0023 changes

The circuit check (`docs/fab/board-v4-refcheck.md` on the t-0023 branch, datasheets read 2026-09-25) named six order blockers. Five are fixed in the schematic and on the board, and the schematic ERC is clean. The NTC doesn't fit (item 6). The antenna keep-out (13 mm against 18) stays as it is; it's on Rolf's list (§4.2).

1. **D1 land.** PESD5V0L1UL is made in Nexperia's SOD882 (DFN1006-2): "leadless ultra small plastic package; 2 terminals; body 1.0 × 0.6 × 0.5 mm" (datasheet Table 4). v2's SOD-523 land was another package.
   - Pinning (Table 3): pin 1 cathode, marked by the bar; pin 2 anode. Pad 1 is on VBUS, pad 2 on GND.
   - Land: KiCad `D_SOD-882`, pads 0.4 × 0.7 at 0.70 pitch, gap 0.30. Nexperia's reflow land (Fig. 13) is 0.3 × 0.6 at 0.60 pitch, gap 0.30. Same gap; KiCad's pads reach 0.10 further out on each side.
   - D1 **remains** on B at (14.30, 28.60), cathode (14.65, 28.60); U3.A2 is (14.30, 17.55), so even the straight-line lower bound is 11.06 mm before the clamp (the copper path is longer). Trials of D1 by U3 ran into the 15.09 notch, R16/R17, U2's courtyard and the input-crossing channels. Beside U2, the F-side u strip 14.48–15.75 is 1.27 mm wide against D1's rotated courtyard width 1.30 mm (0.03 mm overlap); the B-side candidate (14.43–15.73, 19.70–21.40) overlapped the then-R17 courtyard (13.75–15.15, 20.50–21.20) and, after moving R17, the RLD vias. The final B-side TS cap occupies (14.61–15.53, 19.79–21.61), so this pocket cannot also hold D1. Putting the 0402 TS cap on F produced three persistent router conflicts (AFE_IN1N, AFE_IN1P, GND_B). The clean route instead has C18 on B at (15.07, 20.70) and adds C19 OUT bulk on F at (14.10, 34.20). This is not an ESD-interception layout. **The numerical fallback is U3's own conditional 8 kV contact / 15 kV air IEC 61000-4-2 IN rating** (SLUSBV8C §7.2), with C3/C18/(C14+C19) satisfying its 1/1/2 µF effective minimum at the specified biases, calculated below; it does *not* prove a surge at P4, where no contact-level IEC test was run. C24109 is a different IC (TLV320AIC3204IRHBR); D1 now uses the stocked exact PESD5V0L1UL C3001948.
2. **C11 (VCAP2) 1 µF.** TI shows 1 µF at VCAP2 (SBAS502C Fig. 73); v2 had 100 nF. Now 1 µF 0201 (C5142566), its pad 0.6 from pin 27 on a locked F track. The effective value at VCAP2's DC bias is UNVERIFIED (an 0201 X5R loses capacitance under bias).
3. **GPIO1/GPIO2 pull-downs.** SBAS502C §8.5.1.7: the GPIO pins default to inputs and must not float. R34 (GPIO1, pin 26) and R35 (GPIO2, pin 25) are 10 kΩ to GND on B, each one via away from its pin. Firmware leaves both as inputs.
4. **Q2–Q4 PMZ290UNE2.** Nexperia PMZ290UNE2YL, DFN1006-3 (SOT883), LCSC C478155. The older PMZ290UNE is end-of-life. Datasheet Rev. 1 (2015):
   - Pins (Table 2): 1 G, 2 S, 3 D, the order of the SOT-883 land.
   - VGS(th) 0.45–0.95 V at ID 250 µA; RDSon ≤ 1.19 Ω at VGS 1.5 V; IDSS ≤ 1 µA at 20 V (Table 7). VDS 20 V, VGS ±8 V (Table 5).
   - Gate drive: Q2 from R16/R17 (VBUS × 1/1.1: 4.5 V at 5.0 V, 5.0 V at 5.5 V); Q3 from AFE_EN_HW (VBAT through R15, 3.0–4.2 V); Q4 from LED_EN (3.0 V). Each is at least 3× VGS(th) max and under the 8 V gate limit.
   - Off state: without VBUS, R17 holds Q2's gate at 0 V, and 1 µA of IDSS drops 0.1 V across R15. With VBUS, Q2 holds AFE_EN_HW near 0 V (42 µA through ≤ 1.19 Ω), so Q3 is off.
   - Drains see VBAT (≤ 4.2 V) or, for Q4, the LED cathode below VBUS (≤ 5.5 V), against 20 V.
   - Still for the bench (refcheck): the Q2 charge interlock with a low cell.
5. **C17 VREFP 100 nF.** SBAS502C Fig. 73 shows 10 µF + 0.1 µF at VREFP. C17 (100 nF 0201) sits on F beside C9, its VREFP pad next to C9's.
6. **U3 TS: R13 stays; no NTC.** C18 is a TS-to-GND *bypass*, not a temperature sensor and not a change in the TS network decision. TI designs TS for "a 10-k NTC β = 3370 ... connected from the TS pin to VSS" and says to "use a 10-k NTC thermistor in the battery pack (103AT)" (SLUSBV8C §8.3.8, §9.2.2.1.3). An NTC only helps where it touches the cell, and no flex copper does:
   - The cell sits in its pocket at s 1.5–14.9. The island starts at s 16.0 behind the rib (s 14.9–15.7), at least 1.1 from the cell's end through air and plastic.
   - In the cell section the flex is only the SIG1/SIG2 strips and the P4/P5 plate. The strips are Contact copper, one net each (Q97), so no TS track can ride on them. The plate folds against the wall at u 16.19–16.30 behind the standoffs, 4.3 from the cell's side (u 11.9); it would read the charge standoffs.
   - An NTC on the island next to U3 would read the board and stop charge on the board's temperature. That looks like protection and isn't.
   - A cell NTC would need a third J2 contact and a different cell order (L4). Rolf chose to keep the released two-wire J2 and fixed R13 instead, with charging **only off the ear**. The 0–45 °C charge window is a procedural check, not automatic protection (board-v2 §5); bench verification and approval of that residual risk are still required.

7. **Charger IEC capacitor check (t-0036).** TI BQ25100 SLUSBV8C §7.2 rates IN for **8 kV contact / 15 kV air** only when effective capacitance is ≥ 1 µF IN, ≥ 1 µF TS and ≥ 2 µF OUT, X5R or better. Murata SimSurfing **C-DC bias / Capacitance**, 25 °C, 0.1 Vrms, read **2026-09-25**: [online characteristics viewer](https://ds.murata.com/simsurfing/mlcc.html?lcid=en-us); product record [GRM155R61A106ME18](https://www.murata.com/en-global/products/productdetail?partno=GRM155R61A106ME18). Reproducible maker graph data: [10 µF graph](https://ds.murata.com/simserve/characteristics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). Both are **0402, 10 V, X5R, ±20%**, per the maker's SimSurfing `mlcc.csv` product rows. Values below are graph µF, then graph × 0.8 (extra tolerance allowance); no nominal-value arithmetic or uncharacterized C16 is counted.

   | Pin, part | DC bias | Maker graph | ×0.8 | IEC minimum | Margin after ×0.8 |
   |---|---:|---:|---:|---:|---:|
   | IN, C3 10 µF GRM155R61A106ME18 | 5.0 V | 2.277 µF | 1.821 µF | 1 µF | +0.821 µF |
   | TS, C18 10 µF GRM155R61A106ME18 | 5.5 V upper bound (at or below VBUS) | 2.034 µF | 1.627 µF | 1 µF | +0.627 µF |
   | OUT/VBAT, C14+C19 (2 × 10 µF GRM155R61A106ME18) | 4.2 V | 5.562 µF | 4.449 µF | 2 µF | +2.449 µF |

   At 5.5 V IN the 10 µF curve is 2.034 µF (×0.8 = 1.627 µF). C3's VBUS pad is (14.40,16.72), 0.84 mm straight-line from IN ball U3.A2 (14.30,17.55). C18's TS pad is (15.07,20.22), 2.55 mm from U3.B1 (13.90,17.95). **C14's OUT pad is (13.67,27.20), 9.27 mm from U3.A1 (14.30,17.95)**; C19's OUT pad is (14.10,34.68), 16.73 mm away. Their DC capacitance is on VBAT but these lengths are not local high-frequency ESD bypasses. Multiplying again by 0.85 for the X5R ±15% temperature envelope gives IN 1.383 µF at 5.5 V, TS 1.383 µF at 5.5 V, OUT 3.782 µF at 4.2 V: all above 1/1/2 µF *by this independent allowance*, not by measured temperature/bias joint curves. Actual aging, mounted tolerances and contact-level response remain unmeasured. Murata suffix D specifies 180 mm reel paper tape (maker specification); JLC C36626211 has 137 in stock (2026-09-25). There is no claim of a P4 IEC test.

## 3. Layers against the JLC flex rules

Source: https://jlcpcb.com/capabilities/flex-pcb-capabilities, read 2026-09-23 (research §7.1), unless another date is given. JLC does not build rigid-flex ("JLCPCB currently does not support Rigid-Flex PCBs"). So this is a 2-layer flex with FR4 stiffeners, the same construction as v2.

### 3.1 ISP1807 land on two layers

- The land is the datasheet pattern (§4.2 of the datasheet). All used pads are on the outer rows, except pad 13 (nRESET).
- nRESET leaves through a locked F.Cu 0.10 channel between pads 25 and 26. The path in module coordinates: pad 13 → (3.025, 2.7625) → (6.80, 2.7625) → (6.80, 3.05) → (8.35, 3.05).
- The RF bridge from pad 20 to pad 22 is F.Cu 0.25 (net RF_ANT).
- VSS 21 → 23 → 25 and 24 → 25 are bridged at 0.12 inside the module field.
- VSS pads 14, 16 and 18 sit on the row at u 6.65 beside the RF band. No track reaches them (the inner-row gaps are 0.25 against the 0.30 a 0.10 track needs, and the band is to the west). They are tied to the B pour by two locked GND vias **between** the pads, at (6.70, 28.725) and (6.70, 29.375): 0.40/0.15, drill in the 0.25 gap between neighbouring pads, ring edge at u 6.50, 0.05 outside the band (u ≤ 6.45). On F each ring overlaps the two pads beside it (same net), so 14, 16 and 18 are one piece; on B the rings land in the pour, which reaches u 6.45 there. Every VSS pad is on GND, as the datasheet asks ("Should be connected to ground plane on application PCB"), with no copper in the band.
  - Not via-in-pad: the drills are between pads. The coverlay window over the U1 land and solder wicking into the two 0.15 holes at reflow are UNVERIFIED (§11.1).
  - The claim that the module ties all VSS pads together inside stays UNVERIFIED and is no longer needed.
- VBUS (pad 12) and D+/D− (8/10) sit on the same row and stay unconnected (§8).
- No via-in-pad. The datasheet allows "a small number of internal pads … by placing normal vias in the centre of the device … vias tented". v4 doesn't need it.

### 3.2 Stack-up and rules

| Item | JLC | v4 |
|---|---|---|
| Layers | 2-layer 0.11 / 0.12 / 0.20; 4-layer 0.20–0.45 | 2-layer, finished 0.11 |
| Copper | 3/3 mil at 12 µm, 3.5/3.5 mil at 18 µm; 4/4 mil at 1 oz (board-v2, read 2026-09-17) | 0.10 / 0.10 default |
| Contact class (SIG1, SIG2, REF) | ≥ 0.10 | 0.15 track / 0.20 clearance (unchanged from v2) |
| Charge track | — | 0.20 |
| Via | standard hole ≥ 0.15, pad ≥ 0.35 (0.40 recommended); extreme 0.10 / 0.30 at extra cost | 0.40 / 0.15 (standard, annular 0.125) |
| Copper to edge | ≥ 0.30 (board-v2) | 0.30 |
| Hole clearance / hole-to-hole / annular | — | 0.20 / 0.25 / 0.12 |
| Courtyards overlap | — | error |
| Finish | ENIG (board-v2) | ENIG |
| Assembly | two-sided FPC assembly (L8 §2.1); "Min. Component Size: 0201", "Min. IC Pin Spacing: 0.35mm", "Min. BGA Spacing: 0.3mm" (https://jlcpcb.com/capabilities/pcb-assembly-capabilities, read 2026-09-23) | Both sides. 0201 on FPC: UNVERIFIED |

v2 used 0.30 / 0.55 vias. The 0.40 / 0.15 via is JLC's recommended standard via and frees room on the island (L11).

### 3.3 Stiffeners

JLC offers FR4 0.10–1.60, PI 0.10–0.25 and SUS 0.10–0.30. v4 uses FR4 0.2 only, 6 pieces (v2 had 9):

| Layer | Piece | Where |
|---|---|---|
| Eco2.User (B side) | `STIFF_U1_B` polygon | Under U1, the P2 landing and J4 |
| Eco2.User (B side) | P1 landing circle | (5.90, 22.00), R 3.2 |
| Eco1.User (F side) | 3 ring pieces | P1–P3, R 2.9 |
| Eco1.User (F side) | Wall plate | P4/P5 plate, inset 0.3 |

- **Fee:** "when there are 4 or more stiffeners on the board, an extra fee is required" (https://jlcpcb.com/help/article/fpc-extra-charges, re-read 2026-09-18 per board-v2). The amount is UNVERIFIED.
- **Holes not drawn:** the outlines have no holes. The Ø2.7 ring holes and J4's TC2030-NL guide holes must pass through them. How JLC drills stiffeners is UNVERIFIED; the order note must say so.

### 3.4 Bends

- Static bend ≥ 10× thickness gives R ≥ 1.1 at 0.11.
- SIG strips: 180° at R 1.5 (v2's Q83 fold).
- P4/P5 joint: 90° at R 1.1, exactly at the limit.
- A 4-layer flex (≥ 0.20) would need R ≥ 2.0 at both folds, so it is out.

## 4. Floor plan

### 4.1 Frame, cavity and width chain

- Body W 18: cavity u 1.5–16.5.
- Island: u 2.25–15.75 × s 16.0–37.6, minus a relief notch at u 15.09–15.75 × s 16.0–19.6. Area 289.2 mm².
- Cell pocket: s 1.5–14.9. The cell is not under the island.

Width chain in the cell section:

| Item | u |
|---|---|
| Wall | 0 – 1.5 |
| Gap | 0.3 |
| Cell 501012 (pocket) | 1.8 – 11.9 (10.1) |
| Gap | 1.29 |
| P4/P5 standoff 3.0 | 13.19 – 16.19 |
| Ring 0.31 | 16.19 – 16.50 |
| Wall | 16.5 – 18.0 |

The cell section alone would allow W17 (gap 0.29). The island's B side is what needs the 1.0 (§1.4).

### 4.2 Module and RF band

- **Placement:** ISP1807 at KiCad rot 270. Mapping: u = 10.45 − Y, s = MOD_S0 + X, with MOD_S0 25.05.
  - Body: u 2.45–10.45 × s 25.05–33.05.
  - Courtyard: u 2.155–10.745 × s 24.755–33.345.
  - The antenna edge faces −u, toward the anterior board edge.
- **RF band:** u 2.25–6.45 × s 21.8–37.6. No copper on any layer, and no part except U1.
  - Depth 4.2 against the datasheet's 4.0 ("no metal, no traces and no components on any application PCB layer except mechanical LGA pads", 18.0 mm min).
  - The P1 standoff under the island is metal up to s 24.5. That leaves about **13 mm** of metal-free edge (s 24.5–37.6) against the 18 recommended.
  - The RF risk is UNVERIFIED and needs a range test. Full compliance costs about 5 of L (N8).
- **GPIO pads** face +u toward the posterior strip u 10.75–15.75, at s 26.5–31.7 (§8).

### 4.3 Island blocks (as placed)

The full table is `PLACE` in `hardware/board/build_v4.py`; §10 lists every part.

| Block | Side | Centre (u, s) | Content |
|---|---|---|---|
| U1 ISP1807 | F | (6.45, 29.05) rot 270 | Module |
| U2 ADS1292 | F | (11.85, 22.08) rot 270 | AFE |
| J2 Pico-EZmate Slim | F | (5.45, 18.90) rot 270 | Courtyard u 2.29–8.43 × s 16.11–21.70. Cell leads come in at u < 8.43 |
| AFE decoupling, RESET pull-down | F | u 7.75–11.1 × s 18.5–24.10 | C6, C7, C9, C10, C17 (VREFP 100 nF beside C9), R23 |
| Charger pulls | F | (12.60, 18.15), (13.25, 18.97) | R12 (PRETERM), R13 (TS). R13 sits 0.65 east so AFE_IN1N and IN1P's branch drop between C17 and R12 to U2 pins 3 and 4 (§9.2) |
| VCAP2 | F | (15.10, 23.20) rot 270 | C11, beside U2's east row, its pad toward pin 27 |
| CS/DRDY series, pad-23 decoupling, charge LED | F | u 11.05–14.65 × s 25.15–28.0 | R7, R27, C15, D2, R22, Q4, R28. R7 at u 11.05 and R27 turned so MOSI and CS leave U2's south row without a via (§9) |
| SPI series | F | u 11.40 × s 29.6–32.6 | R6, R5, R8 in U2's pad order |
| SW1 | F | (14.45, 31.10) rot 180 | Top 5.72 |
| J4 TC2030-NL, extra OUT bulk | F | J4 (10.00, 35.40); C19 (14.10, 34.20) | Just outside the RF band (u ≥ 6.455); C19 is remote from U3 |
| U5 and caps | B | u 3.1–4.7 × s 17.1–18.3 | Under J2. U5, C16, C12, C13 |
| Contact resistors R1, R2, C4 | B | s 17.25–17.45 | At the strip roots |
| Charger | B and F | U3 (13.90, 17.75) B rot 90 | U3, R11, C2, R25 on B; C3 on F (14.40,17.20), C18 TS on B (15.07,20.70). Both charge nets arrive on B; OUT bulk C14/C19 is remote |
| AFE gate and charge interlock | B | u 9.85–14.45 × s 18.6–23.9 | R15, Q3, R14, Q1, C5 (the west stack at u 9.85–10.80); Q2, R16, R17 beside the charger, so AFE_EN_HW is one short hop from Q2.3 to Q3.1 (§9.2) |
| AFE LDO and RLD network | B | u 11.45–13.3 × s 21.25–24.7 | U4, C8, R4, C1, R24 (START pull-down) |
| GPIO pull-downs | B | (14.95, 23.22), (14.40, 24.55) | R34, R35 (§2.1 item 3) |
| REF resistor, dividers, VBAT bulk, TVS | B | u 12.40–14.55 × s 25.6–29.3 | R3, R20, R21, R18, R19 (u 12.40, U1-side pads west), C14 10 µF, D1 far from charger (§2.1) |

The same features seen from the Contact side are in §5: landings P1 (5.9, 22.0) and P2 (10.4, 33.1), R 3.2; lid posts at (5.9, 23.0) and (9.4, 32.1).

### 4.4 P4/P5 joint, flap, plate and wall rings

| Part | Flat u | Flat s |
|---|---|---|
| Joint bend | 15.090–16.904 | 16.3–19.3 |
| Flap | 16.904–19.114 | 14.85–19.3 |
| Plate | 13.914–19.114 | 1.75–14.85 |

Fold math:

- 90° fold at inner R 1.1. Neutral radius 1.155 (PI mid-plane). Arc = π/2 × 1.155 = 1.814 = 16.904 − 15.09.
- Folded plane: PI mid-plane at u 16.245 (PI u 16.19–16.30). FR4 0.2 lies on the wall side, u 16.30–16.50.
- Folded y = 3.905 + (16.904 − u_flat). The plate spans y 6.895 (u_flat 13.914) down to 1.695 (u_flat 19.114).
  - Clear of the lid at 7.1 by 0.205.
  - Clear of the floor at 1.5 by 0.195.
- Ring sites:

| Ring | Flat (u, s) | Folded wall site |
|---|---|---|
| P4 VBUS | (16.514, 4.35) | u 16.245, s 4.35, y 4.295 |
| P5 GND | (16.514, 12.10) | u 16.245, s 12.10, y 4.295 |

- P5 moves from s 12.35 to 12.10 so the flap clears the rib (s 14.9–15.7). The rib needs a slot for the flap (shell change).
- Standoffs sit at u 13.19–16.19 on the ring axis. The hex AF 5.0, centred at y 4.30, spans y 1.80–6.80.
- The wall rings (`RING_1S_D4.6_NPTH2.7`) carry copper on B only, facing the standoff end. The screw passes the NPTH Ø2.7.
- The plate is 2.26 from the SIG2 strip (13.914 − 11.65).

### 4.5 SIG/REF strips and rings

All strips are 2.5 wide with cap R 3.2, one Contact net each.

| Strip | Strip u | Flat ring | Copper | Folded site |
|---|---|---|---|---|
| SIG1 | 4.65–7.15 | (5.90, 5.29) | B | P1 (5.9, 22.0) |
| SIG2 | 9.15–11.65 | (10.40, −5.81) | F (P2 is plated) | P2 (10.4, 33.1) |
| REF | 7.25–9.75 | (8.50, 43.00) | B | P3 (8.5, 43.0) |

- SIG strips leave the island at s 16.0 and fold 180° at R 1.5 under it (v2's Q83 fold).
- REF leaves the island at s 37.6 through the end-wall slot (s 38.20–39.25).

### 4.6 J3 break-off tab

- Neck: u 15.75–20.10 × s 19.9–22.4. Tab: u 20.10–33.40 × s 16.0–28.0. Cut line: u 16.20. The tab's west edge is 0.99 from the P4/P5 flap (flap u ≤ 19.114).
- Pins, THT Ø1.5, order as v2: J3.1 BENCH_SIG1 (22.40, 19.40), J3.2 BENCH_SIG2 (22.40, 21.94), J3.3 BENCH_REF (22.40, 24.48).
- Bench 220 kΩ (0402, C881401), pad 1 (west) on the AFE side: R31 (22.40, 16.80) north of the header, R33 (22.40, 27.10) south of it, R32 (18.00, 21.15) on the neck.
- Three AFE-side runs cross the neck on F, 0.10 wide, 0.75 apart: AFE_IN1P at s 20.40, AFE_IN1N 21.15, RLD_FB 21.90. Edge gap 0.50 on both sides.
- The tab is cut before closing (Q91). The assembly sheet must show the cut line. After the cut the stub (u 15.75–16.20) carries the three bare AFE-side ends and no Contact copper (§5.4).

### 4.7 Stiffener map

See §3.3. No B-side part sits on `STIFF_U1_B` (the build script checks this). The P1 landing circle carries no B part.

### 4.8 Prebuild cavity tests (by numbers; the later built shell is checked in `shell-v4.md`)

| Test | Result |
|---|---|
| Island courtyards inside the cavity walls | All ≥ 0.75 inside (build check: 0 courtyards off the island). U1 overhangs the island by 0.095 and is still 0.655 inside |
| F parts under LID_Y 7.1 | Tallest J2 6.32 (0.78 spare). Module 6.12, SW1 5.72 |
| B parts over the collars (top 3.5) | B parts ≤ about 0.7 tall, so bottoms ≥ 4.31. P1 collar u 1.7–10.1 × s 17.15–26.85; P2 collar u 6.2–14.6 × s 28.3–37.95 |
| J3 stub after the cut | u 15.75–16.20, inside 16.5 |
| Wall plate | y 1.695–6.895 inside floor 1.5 and lid 7.1 |
| Cell leads | Run at u < 8.43 to J2 |

### 4.9 J2 against the P5 hex well (need ≥ 0.3)

| Item | u | s | y |
|---|---|---|---|
| J2 courtyard | 2.29–8.43 | 16.11–21.70 | 5.12–6.32 |
| P5 standoff | 13.19–16.19 | centred 12.10 | 1.80–6.80 |
| P5 well (AF 5.30, corner r 3.06) | from 13.19 | 9.04–15.16 | — |

Gaps: u 4.76, s 0.95, box distance 4.85 (courtyard outer edge; on the line-centre box of §10.2 and the test, u 4.81 and s 0.99). **J2 clears P5 by ≥ 4.76 in u (≥ 0.3 ✓)**, provided the shell's well doesn't reach past the standoff end at u 13.19 in −u. The shell must hold that.

## 5. Contact safety

### 5.1 Island and cavity boundary

- The island (u 2.25–15.75 × s 16.0–37.6) and everything on it sits inside the cavity (u 1.5–16.5), under coverlay except part pads.
- Skin reaches only the P1–P3 titanium domes and the P4/P5 screw heads in the posterior wall (Q90).

### 5.2 220 kΩ per electrode path, R7/G2

- R1 (SIG1 → AFE_IN1P), R2 (SIG2 → AFE_IN1N) and R3 (REF → RLD_FB): 220 kΩ 0402, C881401. Unchanged (Q79, R7).
- The G2 boundary-state circuit is unchanged (board-v2 §3). With VBUS present, R16/R17 turn Q2 on, AFE_EN_HW goes low, Q3 turns off, R14 pulls AFE_GATE to VBAT and Q1 turns off. The AFE is unpowered while charging.
- Only the packages changed (Q1–Q3 DFN1006-3, R14–R17 0201).

### 5.3 Landings and lid posts

- **Landings:** the P1 and P2 standoff tops (SIG1 and SIG2 metal) press on the island's B face at P1 (5.9, 22.0) and P2 (10.4, 33.1), R 3.2.
  - Inside a landing: no via, no B part. B tracks are allowed only under the FR4 0.2 stiffener, which insulates them from the standoff.
- **Lid posts** replace plan §5.2's board screws and bosses:
  - P1 post at (5.9, 23.0), Ø2.0, nylon, with an F part keep-out of r 1.3 (it sits in the RF band).
  - P2 post at (9.4, 32.1) presses on U1's top. The force is not computed (G7).
- The island is clamped between the standoff tops and the lid posts. There are no island holes.

### 5.4 Contact corridor and charge copper (as built, locked)

Contact runs are 0.15 track at 0.20 clearance. Each strip run is split at the zone exit, site ± (3.5 + 0.10). So the Q84 1.0 mm rule covers only the land segment, and the rest of the strip is under the 0.20 strip rule (Q88).

Contact copper stays on the island: each Contact net ends at its 220 kΩ (R1–R3) and nothing Contact goes to the tab. J3's pins carry the bench nets BENCH_SIG1, BENCH_SIG2 and BENCH_REF (Contact class) and reach the AFE nodes through their own 220 kΩ, R31–R33, on the tab side of the cut (R7: every gel-header path is protected by its own 220 kΩ). What crosses the neck and the cut is AFE-side copper only. Opus's first layout ran SIG1/SIG2/REF branches to J3 and left their ends bare on the stub after the cut; that is gone.

| Net | Layer | Path |
|---|---|---|
| SIG1 | B | P1 → zone exit (5.90, 8.89) → (5.90, 16.40) → R1.1 |
| SIG2 | F | P2 → zone exit (10.40, −2.21) → via (10.40, 16.50). B: via → R2.1 |
| REF | B | P3 → zone exit (8.50, 39.40) → (8.50, 37.20) → (15.35, 37.20) → (15.35, 25.60) → R3.1 |
| BENCH_SIG1 | F, 0.15 | J3.1 (22.40, 19.40) → (22.91, 18.30) → R31.2 (22.91, 16.80) |
| BENCH_SIG2 | F, 0.15 | J3.2 (22.40, 21.94) → (21.61, 21.15) → R32.2 (18.51, 21.15) |
| BENCH_REF | F, 0.15 | J3.3 (22.40, 24.48) → (22.91, 25.58) → R33.2 (22.91, 27.10) |
| AFE_IN1P | F, 0.10 | R31.1 (21.89, 16.80) → (20.50, 16.80) → (20.50, 20.40) → (15.40, 20.40); the router joins it to the end of the locked trunk at (11.95, 16.66), and the trunk and its branch reach R1.2 and U2 pad 4 (§9.2, pass 5) |
| AFE_IN1N | F, 0.10 | R32.1 (17.49, 21.15) → (15.40, 21.15); the router joins it to U2 pad 3, and a locked run joins pad 3 to R2.2 (§9.2, pass 5) |
| RLD_FB | F, 0.10 | R33.1 (21.89, 27.10) → (20.90, 27.10) → (20.90, 21.90) → (15.40, 21.90); the router joins it to R3.2 and U2 pads 29/30 |

- SIG2's strip copper is on F because P2 is plated. Each strip carries one net on one layer; the one Contact via is on the island at SIG2's strip root, not in a strip. SIG1 and REF have no via.
- With the tab on (bench use), a gel lead on J3.n sees pin → 0.15 track → 220 kΩ (R31–R33) → AFE node, and the dome on the same node sees dome → strip → 220 kΩ (R1–R3) → AFE node: two independent 220 kΩ per node. The bench nets are in the Contact netclass (0.15/0.20) and R31–R33 sit at u ≥ 17.49, east of the cut.
- The cut at u 16.20 crosses only the three AFE-side 0.10 runs.

Charge copper, 0.20 track. It is only where skin can't reach: plate, flap and joint.

| Net | Path |
|---|---|
| P5 GND | B: ring → (17.95, 13.30) → (17.95, 15.75) [zone exit] → (17.95, 16.90) → (14.84, 16.90) → (14.35, 16.39) → (11.80, 16.39) → R11.2 along the top edge (0.10, locked, pass 6), then the B pour |
| P4 VBUS | B: ring → via (16.514, 7.55) → F → (18.40, 8.55) → (18.40, 15.75) [zone exit] → via (18.40, 17.00) → B → (18.40, 18.40) → (14.65, 18.40) → U3 VBUS ball |

- P4's via is its own net inside its own 7 × 7 zone, which is allowed.
- VBUS passes P5 on F, where P5 has no copper (B-only ring). Both charge runs split at s 15.75, so only the in-zone segments carry the 1.0 mm rule.
  - On F, VBUS runs 0.44 from P5's NPTH hole edge. The hole clearance rule is 0.20, so this passes. P5's screw is GND.
- The VBUS flap via is 1.03 edge to edge from GND's in-zone segment (≥ 1.0).

### 5.5 Q84 / Q88 / Q97 check

| Rule | v4 |
|---|---|
| Q84/Q88 `tabs` 7 × 7 at P1–P3, 1.0 | Kept; the land segment only |
| `tail_pads` 7 × 7 at P4/P5, 1.0 | Kept |
| Strips: 0.20, foreign-net keep-out | Kept |
| Island: Contact class 0.20 | Kept |
| Q97(a) one Contact net per strip, one layer | ✓ (SIG2 on F, SIG1 and REF on B) |
| Q97(b) class clearance under coverlay | ✓ |
| Q97(c) no foreign via or pour inside a land's zone | ✓ (P4's own-net via only) |
| Q97(d) R1–R3's pads the only exposed Contact copper on the island | ✓: Contact nets end at R1–R3; J3 carries bench nets behind R31–R33; the stub after the cut carries AFE-side copper only (§5.4). `tests/test_board_v4.py` checks that Contact nets sit only on P1–P3 and R1–R3 and that no Contact copper lies east of u 15.75 |
| Q97 "away from U1's antenna edge" | ✓: SIG1 stays at u 5.90, s ≤ 16.40; SIG2 at u 10.40, s ≤ 16.50; REF runs along s 37.20 (u 8.5–15.35) and u 15.35. None of it is in the RF band (u ≤ 6.45, s 21.8–37.6) |

The r12 flag (Contact ends bare on the stub after the cut) is closed by R31–R33: no Contact copper crosses the cut, so no cover and no drawn exception is needed.

## 6. Target W / T / L

Area check (courtyards):

- Courtyard bounding boxes from the placed board, text parse. U1 counts only outside the RF band.
- F usable = island minus the RF band minus the P1 post keep-out.
- B usable = island minus the RF band, the landings and `STIFF_U1_B`.
- Placed at W18 (t-0012's placement, before the refcheck parts): F parts 155.0 mm² (22 parts), B parts 45.7 mm² (33 parts). J3 and the rings are off the island.

| W | Island u | Island mm² | F usable | B usable | F fill | B fill | Result |
|---|---|---|---|---|---|---|---|
| 16 | 2.25–13.75 | 246.0 | 178.3 | 83.4 | 87% | 55% | Not tried (needs nuts) |
| 17 | 2.25–14.75 | 267.6 | 199.9 | 104.6 | 78% | 44% | **Tried, doesn't place** |
| **18** | 2.25–15.75 | 289.2 | 221.5 | 126.2 | **70%** | **36%** | **Placed: 0 keep-out problems** |

B fill looks low, but B usable is scattered: most of it lies in the P1 landing's shadow, under the stiffener, or in thin strips. At W17 the seven divider/interlock parts had no block of B area with room for their vias (§1.4). Area alone doesn't decide this; the placed board does.

Body per cell (T and L don't depend on W):

| Cell | T | Chord | M1 ≥ | mAh |
|---|---|---|---|---|
| 501012 (pick) | **8.1** | **47.90** | **50.9** | 40 |
| 401012 | ≈ 7.6 | 48.40 | 51.4 | 40 |
| 301012 | ≈ 7.6 | 48.40 | 51.4 | 25–30 |
| 401010 | ≈ 7.6 | 46.40 | 49.4 | 30 |
| v2 reference (W22) | 9.0 | 47.90 | 50.9 | 40 |

W16 needs M2.5 nuts at P4/P5 (m 2.0, W 16.01). W18 needs nothing new.

## 7. Plan-v2 clauses that block a smaller body

I didn't edit plan-v2. Each clause below is one v4 departs from, or one that stops a smaller step.

| Clause | Text | v4 | Why |
|---|---|---|---|
| §3 | "The module sits on the board's top; nothing taller than the module anywhere." | J2 mated 1.20 > module 1.0 | The lowest verified 2-pin connector in the local research that R2 allows is 1.20. DF58 (1.00) needs crimping or a pre-crimped lead. J2 still sits under LID_Y with 0.78 spare |
| §3 module envelopes | "Modules: Raytac 10.5 × 15.5, reserve 2.3; E73 13 × 18 × 2.0" | ISP1807 8 × 8 × 1.0 | Both listed modules are too big for W18 |
| §1 item 5 / §4 | Candidates A (Raytac) or B (E73) | Neither | As above |
| G3 | Module sourcing | Consignment or global sourcing | ISP1807 is not in the JLC library |
| G3c | The module's antenna keep-out from its own document | About 13 mm metal-free against 18 | Full compliance costs about 5 of L. Needs a range test |
| §5.2 | "Rigid FR4, 4 layers, 1.0 mm … M2.5 mounting holes onto printed bosses" | 2-layer flex (already interface II in v2), lid posts, no board screws | Screws and bosses cost island area and a step. A 4-layer flex breaks the folds |
| §8 step 4 | "holes over the bosses" | No holes. The island sits on the P1/P2 standoff tops under the lid posts | |
| §8 step 5 | "Turn the board screws with the hex key until they seat." | Step removed | Lid posts |
| §8 step 8 | USB-C | Already gone (Q81) | — |
| R2 | "one 1.5 mm hex key, no soldering, glue, crimping or wire stripping" | Kept | Blocks M2 P4/P5 hardware (N5) and J2 solder tabs. Requires the cell to come with the Pico-EZmate Slim plug fitted (G1b/Q69) |
| §5.5 supply gate | — | Kept | Refused as a lever |
| §5.6 bench header | — | Kept on the break-off tab | Q91 |
| Q90 P5 site | s 12.35 | s 12.10 | Flap clears the rib at s 14.9 |
| Closure | M2.5×8 at (u 16.50, s 41.00) | Redesign, not a move (shell change) | At W18 the tail is u 0–18. Beside the Ø7.5 REF pocket (u 4.75–12.25) a Ø5.0 head well with 1.0 walls needs 7.0 of u: 12.25 + 1.0 + 5.0 + 1.0 = 19.25 > 18 on the +u side, and 4.75 − 7.0 < 0 on the −u side. So either the well goes past the pocket into the tail loft (centre s ≥ 43 + 3.75 + 1.0 + 2.5 = 50.25, which is beyond the loft start 45.5 and needs the tongue slot moved) or the closure becomes a latch |
| Rib | s 14.9–15.7 | Slot for the P4/P5 flap (shell change) | Cut the rib back 0.50 from the posterior wall over its full height: remove u 16.00–16.50 × s 14.90–15.70 × y 1.50–4.50. The flap (0.31 thick on the wall face, y 1.695–3.905) then has 0.19 of air (§4.4, §10.2) |
| P4/P5 wall collars | r9: hex sockets 2.08 proud of the wall face, wells 3.28 deep | Must go (shell change) | The plate lies on the wall face (u 16.19–16.50 × s 1.75–14.85 × y 1.695–6.895); a socket proud of the face would sit on the plate. Key each standoff instead with two floor-standing walls: u 13.19–16.19, s = site ± (2.65 + 0.15) outward, 1.0 thick, y 1.50–4.30 (up to the hex axis; AF 5.0). The standoff's −u end stays open; the cell (u ≤ 11.90) is 1.29 away |
| Lid posts | none | Two posts on the lid (shell change) | Ø2.0 at (5.90, 23.00), 1.98 long onto the island's F face at y 5.12; and at (9.40, 32.10), 0.98 long onto U1's top at 6.12 (§5.3) |
| LID_Y | 8.0 | 7.1 | Set by the cell (§1.2); T 8.1 |
| Cavity width | u 1.5–20.5 (W22) | u 1.5–16.5 (W18) | §4.1. Everything else of the r9 shell (SIG fold pockets, REF slot, hinge, hook) is used unchanged in §10.2 |
| Foam 0.5 (decision 57; plan §3 says 0.3) | — | 0.5 kept | 0.3 would give T 7.9 with a plate re-cut (N6) |

## 8. Firmware pin map (for WP13)

Pin map A (as built). Every fast SPI line is on a full-speed pin; the low-frequency pins carry only slow or analog signals.

| Signal | v2 nRF | v4 nRF | ISP1807 pad | Note |
|---|---|---|---|---|
| AFE_SCLK | P0.08 | P0.06 | 34 | |
| AFE_MOSI | P0.06 | P0.05 | 36 | |
| AFE_MISO | P0.15 | P0.08 | 32 | Full-speed pin (see below) |
| AFE_CS | P0.13 | P0.28 | 48 | LF-only; toggles once per frame |
| AFE_DRDY | P0.17 | P0.29 | 46 | LF-only; one pulse per sample |
| AFE_START | P0.20 | P0.10 / NFC2 | 4 | NFC pin as GPIO; static |
| AFE_RESET (PWDN) | P0.22 | P0.26 | 6 | |
| CHG_MON | P0.31 AIN7 | P0.30 AIN6 | 44 | Analog |
| VBAT_SENSE | P0.02 AIN0 | P0.31 AIN7 | 42 | Analog |
| VBUS_DET | P0.24 | P0.02 | 40 | Digital input; slow |
| LED_EN | P0.04 | P0.03 | 38 | Slow |
| BAT_MEAS_EN | P0.03 | — | — | removed (Q5) |
| nRESET | P0.18 | P0.18 | 13 | Pad channel (§3.1). No external pull-up (R26 removed) |
| SWDIO / SWDCLK | SWDIO / SWDCLK | same | 28 / 30 | J4 |
| +VDD | module REGOUT0 | VCC_nRF from U5 | 26 | 3.0 V |

**Low-frequency pins.** In the nRF52840 PS v1.11 pin table, P0.28, P0.29, P0.30, P0.31, P0.02, P0.03, P0.09 and P0.10 say "Standard drive, low frequency I/O only". Footnote 322: "Low frequency I/O is a signal with a frequency up to 10 kHz." The footnote doesn't exempt inputs.

- The first draft put AFE_MISO on P0.29, an LF-only pin, carrying SPI data at the SCLK rate. Pin map A moves SCLK, MOSI and MISO to P0.06, P0.05 and P0.08 (pads 34, 36, 32), which are full-speed.
- CS, DRDY, START, LED_EN, VBUS_DET, CHG_MON and VBAT_SENSE are slow or analog, so they're fine on LF pins.

**Reset pin.** R26 is gone. Firmware must configure P0.18 as RESET: UICR PSELRESET[0] and [1] = 18 (Zephyr `CONFIG_GPIO_AS_PINRESET`). Until that is written, P0.18 is a plain GPIO and SW1 does nothing. The pin's own pull-up does the job. PS v1.11 §5.3.8.3 gives tPINR as 32.5 ms at 500 nF and 650 ms at 10 µF, which is 5 × 13 kΩ × C: my reading is an internal pull-up of about 13 kΩ. The §7.3 reference circuits show no external reset resistor. A factory-fresh module is programmed over SWD (J4), which does not need the reset pin.

**NFC pins as GPIO.** Set UICR NFCPINS.PROTECT = Disabled (Zephyr `CONFIG_NFCT_PINS_AS_GPIOS`). PS §6.14.3: "some increased leakage current between the two pins is to be expected if they are used in GPIO mode, and are driven to different logical values. To save power, the two pins should always be set to the same logical value whenever entering one of the device power saving modes". INFC_LEAK is 1–10 µA. Pad 2 (P0.09/NFC1) is left open. Firmware should drive it to START's level before sleep.

**VSS 14/16/18.** Connected to the B-side GND pour through two vias between the pads (§3.1). Whether the module ties them inside is UNVERIFIED and not relied on.

**VBUS (pad 12) and D± (8/10) are unconnected.**

- The module never sees USB.
- `firmware/elicio_stream/elicio_stream.ino` reads VBUS through `NRF_POWER->USBREGSTATUS`. It must switch to the VBUS_DET GPIO (R18/R19 divider).

**First load.** VDD is 3.0 V from U5 from power-up, so v2's REGOUT0 1.8 V first-load issue is gone. A 3.3 V probe sits at VDD + 0.3, not over it. G4 still verifies.

**AFE inputs while +3V0 is off or ramping (firmware lane t-0022).** SBAS502C §10.1: "Before device power-up, all digital and analog inputs must be low. At the time of power-up, all of these signals should remain low until the power supplies have stabilized". The MCU runs from U5 all the time, but +3V0 is off whenever VBUS is present (Q2 → Q3 → Q1, §5.4 interlock). So while a charger is on, the MCU's lines to U2 face an unpowered chip. U2's inputs have no pull resistors of their own; the limits are digital input ≤ DVDD + 0.3 and ±10 mA continuous per pin (§6.1).

- **CS, SCLK, MOSI** reach U2 through R7, R6, R5 (10 kΩ). A line left high into an unpowered U2 feeds at most (3.0 − 0.3) / 10 kΩ ≈ 0.27 mA into its clamp: no harm, but it lifts +3V0 partway and spoils the power-up. Firmware releases them (output low, or input disconnected) and they carry nothing. **No pull-downs needed.** A pull-down on U2's side would cost 30 µA per line at 100 kΩ while CS idles high.
- **RESET and START** are wired straight to U2, with R23 and R24 (100 kΩ) already pulling them low. Released, they sit low as §10.1 wants. There's no series resistor, so RESET held high by mistake would back-feed U2 through its clamp. Once C8 is charged the current is U2's own supply draw, under the ±10 mA limit. No part change; this is a firmware rule.
- **Firmware rule.** While VBUS_DET is high, and from boot until +3V0 has been up for tPOR (2¹² tMOD, Table 29), drive CS, SCLK, MOSI, START and RESET low or disconnect them; never high. VBUS_DET rises with VBUS (R18/R19), while +3V0 falls only after Q2, Q3 and Q1 have switched; a few milliseconds of overlap are harmless at these currents. After VBUS goes away, +3V0 comes back once R17 has drained Q2's gate. Then wait tPOR, pulse RESET and configure. MISO and DRDY are inputs at the MCU behind R8 and R27 and need nothing.

**CHG_MON range (t-0022).** CHG_MON is ISET seen through R25 (10 kΩ) on P0.30/AIN6. The BQ25100 regulates ISET against a 1.5 V fast-charge reference (SLUSBV8C §8.2 block diagram; the table has no V_ISET row, so UNVERIFIED as a number), and less than that in precharge and taper. Without VBUS the charger is "dead" with every pin high impedance (§8.4.1), and R11 holds ISET at 0 V. So CHG_MON stays at 1.5 V or below, inside U1's VDD 3.0 (VI/O ≤ VDD + 0.3, nRF52840 PS Table 185). If R11 fails open, ISET's voltage isn't specified (UNVERIFIED); its absolute maximum is 7 V (§7.1), and even at 7 V R25 limits the current into U1's clamp to ≤ 0.4 mA. The SAADC sees about 17 kΩ of source (R25 plus R11), so firmware sets its acquisition time for that.

## 9. Routing status

**Routed again (t-0036 ESD-cap revision).** `hardware/board/elicio-v4.kicad_pcb`:

- 1047 track segments (210 locked pre-routes) and 56 vias (28 locked). Every connection is closed. D1 remains at the far end; see §2.1 for the conditional IEC rating and residual ESD risk.
- The two GND pours (F and B, over the whole island) are filled and saved; the release DRC does not refill.
- DRC (kicad-cli 10.0.6, project rules `elicio-v4.kicad_dru`, `--refill-zones --schematic-parity`, on the committed file in place), verbatim: `Found 28 violations`, `Found 0 unconnected items`, `Found 2 schematic parity issues`.
  - Errors: 0: no short, no clearance error, no starved thermal (§9.3). Unconnected: 0.
  - Warnings: 27 `lib_footprint_mismatch`, 1 `via_dangling`. `build_v4.py` strips footprint silkscreen and hides fields, so the placed footprints differ from KiCad's library copies. `via_dangling` is the +VDD pre-route via at (7.60, 36.70), used on F only. The parity warnings are J2's two MP pads, which have no schematic pin.
- `scripts/board/release.py --board elicio-v4 --routed`: exit 0, `routed: true`. ERC 0 errors and 0 warnings; DRC 0 errors, 28 warnings, 0 unconnected; 63 BOM rows and 63 CPL rows, no BOM line without a CPL row; 17 files in `gerbers/` (14 layers, PTH and NPTH drill, job file); STEP written without models for 5 footprints (Molex Pico-EZmate Slim, Texas DSBGA-6, Texas RSM0032, Texas X2SON-4, SOT-883). The outputs are in `hardware/board/release/elicio-v4/`; they're not committed, and the command writes them again.
- Unchanged: two copper layers, 0.10/0.10 track and clearance, 0.40/0.15 vias, the Contact class and the Q84/Q88/Q97 rule areas. The folded body is still 18 × 8.1 (§10.2).

### 9.1 What each router did

| Router | Input | Result |
|---|---|---|
| Freerouting 2.4.1 on OpenJDK 25, `-Xmx4g`, locked Contact copper as fixed wires (`scripts/board/route_v4.py --route`; t-0012) | W18 as placed at f1413a7 | 18 connections open; it never closed them |
| `v4_route_pf.py` (negotiated congestion on a 0.025 grid, 0.10 tracks, 0.40/0.15 vias, rule areas and locked copper kept), GND skipped (t-0012) | reliefs 1–4 (§9.2) | 0 conflicts at round 30: df6ae3a, every net but GND routed, GND in 37 pieces |
| `v4_route_fix.py --nets GND --ripup 4` with the pours filled and read as copper (t-0014) | df6ae3a's routing plus the tab and the VSS vias | 37 → 15 GND pieces; the last 14 sat in the power corner and under U2, boxed in on both layers by the other nets. GND cannot be added afterwards at this density; it has to be routed with the rest |
| `v4_route_pf.py` with GND as one live net: warm start on df6ae3a, then `--fresh` | same | did not converge: 13 nets in conflict after 35 rounds, 15 after 21 |
| `v4_route_pf.py --fresh --skip GND` with the 28 GND pads the pours cannot reach renamed to one net `GND_T` (`v4_gnd_split.py`) | fresh build | 15 nets in conflict after 30 rounds: one GND tree across the island fights like the net itself |
| `v4_route_pf.py --fresh --skip GND`, nothing renamed | fresh build with the tab | 0 conflicts at round 39, but GND then in 33 pieces that neither the finisher nor `v4_stitch.py` could join: the routed nets leave no GND corridors |
| `v4_route_pf.py --fresh --skip GND --rounds 80` with those GND pads in three regional nets, `GND_A` (west stack and U1's north pads), `GND_B` (power corner and north row) and `GND_C` (R19, R21, R28, C15) | reliefs 1–4 | 7 nets in conflict after 70 rounds (h1) |
| same | relief 5 without the Q3/R15 turn and the VCAP1 pre-route | 10 nets in conflict after 80 rounds, six knots (h3) |
| same | relief 5 complete | 8 nets in conflict after 80 rounds, six knots (h5): AFE_EN_HW/CHG_MON on B at (8.3–8.7, 25.1–25.5), AFE_DRDY/AFE_MOSI on F at (11.0–11.4, 30.2–30.5), AFE_VIN/VBAT on B at (10.6–10.9, 20.0–20.3), CHG_MON/VBUS_DET on B at (10.3–10.6, 26.4–26.7), AFE_EN_HW/AFE_VIN on B at (8.0–8.3, 19.5–19.8), GND_B/CHG_MON on F at (10.5, 17.5) |
| same with `--all-after 40` (every net re-routed each round from round 40) | as h3 | 12 nets in conflict after 60 rounds (h4) |
| same with `--rip-near h5_conf.json --radius 1.2` (every net with copper within 1.2 mm of a knot ripped and re-routed together) | h5 | 13 nets in conflict after 45 rounds (h6): a knot needs a placement change, not a third net moved |
| Finishing sequence (§9.5) on h3 and h5: `v4_route_fix.py --drop-drc --ripup 4` (drops the conflicting copper, reconnects every net, the GND groups included), GND names restored, refill, `--nets GND --ripup 4`, `v4_stitch.py`, again, `v4_thermal_stubs.py` | h3 → m, h5 → n | m: 0 DRC errors, 9 open (3 GND pieces, VBAT, VBUS_DET ×2, VCAP1, AFE_VIN, AFE_GATE). n: 0 DRC errors, 10 open (5 GND pieces, AFE_DRDY, AFE_VIN ×2, CHG_MON, VBUS_DET) |
| `v4_route_fix.py --ripup 12 --pen 6` on the unfilled m and n boards | m1, n1 | m: 4 signal opens left (VBAT, VBUS_DET ×2, VCAP1); n: 5 nets still open, AFE_EN_HW and CHG_MON trading places every round |
| `v4_route_fix.py --soft-fills --ripup 8 --pen 6` on the filled n board: a pour blocks only its own net, every other net routes through it as if unfilled (the pour yields on refill), then GND finisher, stitching, stubs | n | the same 10 open connections: the rip-up moves each blocker and finds no other home for it; on GND it rips eight ISET items four rounds running and reverts each time |
| `v4_route_pf.py --fresh --skip GND --rounds 80`, GND in regional nets (t-0016 run 2) | pass 2 (§9.2 relief 6) | 7 knots, all north of s 25 |
| same (t-0019 run 1) | pass 3: refcheck parts, U2's GND core locked (relief 7) | 15 nets in conflict after 60 rounds, round U2's north side and the charger |
| same (t-0019 run 2), then `v4_finish.sh` | pass 4: placement at the knots and the corner pre-routes (relief 8) | 2 nets in conflict after 80 rounds (AFE_IN1P, AFE_IN1N). Finished: DRC 0 errors, 1 open: AFE_IN1N, 0.51 mm at U2 pins 3/4. The two inputs must cross once, which no routing order avoids |
| same (t-0019 run 3) | pass 5: the IN1P/IN1N crossing locked, R13 moved (relief 9) | 2 nets in conflict after 80 rounds (AFE_IN1P, GND_B): U3.C2's GND boxed in. Not finished |
| same (t-0019 run 4), then `v4_finish.sh` | pass 5b: a GND via for U3.C2's corner (relief 9) | 0 conflicts at round 16. Finished: DRC 0 errors, 2 open, both GND islands 0.40 mm from the main GND (P5's run north of U3; Q4.2's F pocket) |
| same (t-0019 run 5), then `v4_finish.sh` | pass 6: two locked GND links (relief 10) | 0 conflicts at round 16. Finished: DRC 0 errors, 0 open. Previous board |
| t-0036 first trial (router only) | C3 F, C18 F, D1 unchanged | 3 conflicts at round 79 (AFE_IN1N, AFE_IN1P, GND_B) near (15.2,20.7); not finished |
| t-0036 second trial, `v4_finish.sh` | C18 B, R17 moved west to u 13.70, C3 F and C14 larger; D1 unchanged | 0 conflicts at round 79, GND_C reported failed; finisher: DRC 0 errors, 0 unconnected; intermediate board |
| t-0036 final trial, `v4_finish.sh` | C18 increased to 10 µF and C19 10 µF added at F (14.10,34.20); D1 unchanged | 0 conflicts at round 79, GND_C reported failed; finisher: DRC 0 errors, 0 unconnected, routed release passes. Current board |

Freerouting stalled at this density: 0.10/0.10 rules, locked Contact copper, and B mostly keep-out (t-0012). The negotiated router lets nets share cells early and raises the price of shared cells each round until the nets separate; when nets still fight at round 80 the fight points at the placement. GND is the hard net: the pours reach only what the signal routing leaves open, so GND has to be in the negotiation from the start, but as one net it is too big to negotiate (it touches every part). What closed it: three regional GND nets, with locked copper at every knot that kept coming back (U2's GND core, the +3V0 hub, the charger corner, the IN1P/IN1N crossing). With those locked, the router converges in 16 rounds and the finisher joins the three GND regions through the pours.

### 9.2 Placement reliefs that made it route

1. **Via column at u 10.72 beside U1's east pads** (pads at u 10.14). R7 and R27 moved, R18/R20/R21 went to u 11.80, and R19 and Q2 were re-placed.
2. **Crossings removed:**
   - C9 and C10 swapped (VREFP and VCAP1 crossed).
   - R12 turned 180° (PRETERM needed a via).
   - R15 turned 180° (VBAT hops on F).
   - C14 and R19 turned.
3. **Q2_G cluster.** R16 and R17 moved beside Q2's gate.
4. **C14 turned so its VBAT pad faces east.** With the pad facing west, VBAT ran R14 → Q1 → C14 → R20 on B. That walls off AFE_VIN's path from U4 to C5 and Q1.3, so neither net could close without crossing the other.
5. **West stack 0.10 west, GND pads turned east, VCAP1 pre-routed (t-0014).** The west stack (R15, Q3, R14, Q1, C5) sits at u 9.85 (df6ae3a: 9.95) and R24 at 9.30 (9.40), as far west as R14's and Q1's courtyards clear LAND_P1 (`check_keepouts` in `build_v4.py`). C8, C14 and C11 are turned so their GND pads face east, under U2's exposed pad; the B corridor between the two stacks beside Q1 grows from 0.42 to 0.52 mm and carries no GND. Q3 and R15 are turned so GND and AFE_EN_HW face west, away from that corridor, and AFE_GATE east. VCAP1 (C10 to U2.11) is a locked F pre-route west of U2's west row, because every router put +3V0's hop from B across that line. Relief 4 is reversed: C14's VBAT pad faces west again, one hop from Q1.2; with C14's GND pad east it no longer walls off AFE_VIN.
6. **Pass 2 (t-0016).** R20, R21, R18 and R19 went one row east to u 12.40 with their U1-side pads west, so U1's east pads get a second via column at u 11.3, and s 25.05–26.5 stays free for AFE_DRDY's hop to R27 on B. The interlock (Q2, R16, R17) moved north beside the charger, and Q3 and R15 turned so Q2.3 faces R15.2 across the corridor's north end: AFE_EN_HW runs R15.2/Q3.1 → Q2.3, not to U1 (t-0016's finding), and is now one short hop that no longer crosses CHG_MON. Q1 and R14 turned (AFE_VIN east toward U4), C8 turned, C14 to the east pocket beside R20.1, C11 to F beside U2's east row, C3 closed up to U3.A2 (t-0019 only; t-0036 puts it on F).
7. **Pass 3 (t-0019): refcheck parts and U2's GND core.** C17, R34, R35 and D1's SOD882 land (§2.1). U2's GND pads 10, 13 and 24 are tied to the exposed pad, and one exposed-pad via reaches U4.5, U4.2 and C8.2. VCAP2 runs to C11, GPIO1 and GPIO2 hop to R34 and R35. `v4_gnd_split.py` now joins locked GND copper to the region of the pad it touches.
8. **Pass 4 (t-0019): placement at the knots and locked corner routes.** R13 and R4 turned, R16 0.35 south, C5 turned and 0.15 south, R24 to (11.45, 24.70), D1 to (14.30, 28.60) (§2.1 item 1). Locked in `u2_core_pre_routes` (`build_v4.py`):
   - U2's GND core: the exposed-pad via, Q2.S and Q3.S vias into the pad, an exit through pin 24 to C15.2 and C11.2 on F, and the east pocket's GND down the B edge lane.
   - The +3V0 hub on B from U4.1 over C8.1, with arms to U2's four sides; the west via sits outside LAND_P1's 3.4 mm circle. This is t-0014's first proposed pre-route.
   - VBAT's row south of U3 to R15; ISET, TS, PRETERM and CHG_MON; VBUS to C3 and R16; Q2_G; AFE_EN_HW, AFE_GATE (through Q1's pad gap) and AFE_VIN; AFE_START and AFE_RESET out of U2's south-west corner; the RLD_FB and RLDINV vias and B links.

   t-0014's second proposal, AFE_EN_HW across the P1 landing to U1, wasn't needed: after relief 6 AFE_EN_HW is a short B hop with no copper in LAND_P1's 7 × 7 zone, so Q97(c) is untouched.
9. **Passes 5 and 5b (t-0019): the IN1P/IN1N crossing.** The two inputs must cross once: at the J3 neck IN1P lies north of IN1N, at the strips R1 (IN1P) lies west of R2 (IN1N). Locked in `in1_pre_routes`: IN1P crosses over R2 on F, and IN1N leaves R2 by a via just west of it. IN1P's trunk (along the top edge, toward the neck) and its branch (back east to pin 4) wrap round that via. VBUS, the trunk, IN1N and the branch pass the SIG2 root 0.105 apart and 0.21 from the SIG2 via (Contact class 0.20). R13 moved 0.65 east so IN1N and the branch drop between C17 and R12 to pins 3 and 4. Pass 5b: past the SIG2 root, VBUS and the trunk rise to s 16.45 and 16.66, and a locked GND via at (11.67, 17.15) on the R11.2–C2.2 link reaches R12.2 and U3.C2's via on F, since ISET and VBAT box U3.C2 in on B.
10. **Pass 6 (t-0019): two GND links the finisher couldn't find.** P5's charge-return run ends on B north of U3, where ISET and VBUS box it in and the IN1P/VBUS pair holds the F edge: a locked B track takes it along the top edge, north of R11.1, to R11.2 (§5.4). Q4.2 (the charge-LED switch source) sat in an F pocket between LED_EN and VBUS: a locked GND via at (13.50, 28.58) beside D1.2 joins it to B.
11. **t-0036 ESD caps:** C3 grew from 0201 1 µF to 0402 10 µF and moved to F (14.40,17.20), with its VBUS pad 0.84 mm from U3.A2. C14 grew from 0402 4.7 µF to 0402 10 µF at its previous site. C18 0402 10 µF TS/GND sits on B (15.07,20.70), 2.55 mm from U3.B1; R17 moved west 0.75 to leave its courtyard and GND return free. C19 0402 10 µF OUT bulk sits on F (14.10,34.20) for temperature margin. The F-side C18 trial conflicted with the IN1P/IN1N crossing; D1 stayed at the far VBUS end. The router did not finish GND_C, but `v4_finish.sh` closed it and the secondary LED_EN open with DRC 0 (§9.1).

### 9.3 Thermal connections (the starved-thermal decision)

DRC's starved-thermal check stays at KiCad's default: a GND pad with a thermal relief needs two spokes. No `min_resolved_spokes` rule; that would be a waiver, and the r12 review asked for zero errors under the project rules.

- **Exposed pads and mounting pads connect solid** (`elicio-v4.kicad_dru`, rule "GND exposed and mounting pads solid"): U2 pad 33, U4 pad 5, U5 pad 5 and J2's two MP pads. They are reflowed, not hand-soldered, sit under their part and want the copper. A relief has no job there.
- **Reliefs stay on every 0201 and 0402 pad** so nothing tombstones.
- **Second connections are copper:** where the pour reaches a pad from one side only (its other sides are 0.10 routing), a 0.10 GND track runs from inside the pad through the 0.15 thermal gap into the pour, placed by `v4_thermal_stubs.py` and checked by DRC like any track. 5 such tracks on the t-0036 board:
  - U1.1 F.Cu: stub (9.550, 25.700) -> (9.350, 25.700) 0.200 mm
  - U1.14 F.Cu: stub (6.550, 28.600) -> (6.550, 28.825) 0.225 mm
  - U1.18 F.Cu: stub (6.550, 29.500) -> (6.550, 29.275) 0.225 mm
  - R21.2 B.Cu: stub (12.950, 27.600) -> (13.150, 27.575) 0.202 mm
  - C19.2 F.Cu: stub (14.400, 33.900) -> (14.600, 33.950) 0.206 mm
- U2's pads 10, 13 and 24 had stubs in t-0014's state. They are now tied to the exposed pad by locked copper (§9.2 relief 7), and DRC finds no starved thermal on them.

No Contact, creepage or clearance rule changed; the three Q84 rules are as in v2.

### 9.4 The open connections, closed

t-0014 left 10 connections open (5 GND, 2 AFE_VIN, 1 AFE_DRDY, 1 CHG_MON, 1 VBUS_DET). All are closed on the committed board. What changed at each spot (reliefs in §9.2):

| t-0014 open piece | What changed |
|---|---|
| AFE_DRDY: U1.46 to R27, across AFE_MOSI on F | The dividers at u 12.40 leave s 25.05–26.5 free for DRDY's hop to R27 on B (relief 6) |
| AFE_VIN: B tracks at u 8.30–10.62 × s 19.50–19.93, across AFE_EN_HW | AFE_EN_HW is a short hop to Q2.3 after the interlock moved north (relief 6); AFE_VIN is locked (relief 8) |
| AFE_VIN: U4.3, U4.4 to Q1.3, across VBAT and AFE_GATE | Q1 turned so AFE_VIN faces U4 (relief 6); AFE_GATE is locked through Q1's pad gap (relief 8) |
| CHG_MON: U1.44, across AFE_EN_HW on B | AFE_EN_HW no longer runs south past U1 (relief 6); CHG_MON is locked (relief 8) |
| VBUS_DET: R18.2, R19.1 to U1, across CHG_MON on B | U1's east pads have a second via column at u 11.3 (relief 6) |
| GND: U2.10, U2.13, U2.24, U2.33 inside U2's pad ring | Pads 10, 13 and 24 are tied to the exposed pad, which has its own via (relief 7) |
| GND: U4.2, U4.5 | The exposed-pad via reaches them on B (relief 7) |
| GND: C14.2, C8.2 | C8.2 is on the exposed-pad via (relief 7); C14 moved to the east pocket beside R20.1 (relief 6) |
| GND: C11.2 | C11 moved to F; pin 24's exit reaches C11.2 and C15.2 (reliefs 6, 8) |
| GND: P5's run, 0.37 from U3.C2 across ISET | The top-edge link from P5's run to R11.2 (relief 10) and the GND via for U3.C2's corner (relief 9) |

The opens that came up on the way were AFE_IN1N's forced crossing (run 2) and two GND islands (run 4). Reliefs 9 and 10 closed them. On t-0036 the finisher additionally closed an LED_EN open at (12.40,29.77) to R28.1, then joined the GND island it displaced at C6.2; no opens remain.

### 9.5 Rebuild and re-route

The current board came from this sequence (scratch copies in `$W`; DRC needs `<stem>.kicad_pro`, `.kicad_dru` and `.kicad_sch` beside each copy; one router or KiCad batch at a time):

```bash
cd hardware/board
KP=/Applications/KiCad/KiCad.app/Contents/Frameworks/Python.framework/Versions/3.9/bin/python3
PY=../../.venv/bin/python
python3 gen_v4_sch.py                                   # schematic and project (netclasses); ERC must be clean
$KP build_v4.py --out $W/new.kicad_pcb                  # placed board, locked pre-routes, pour outlines (no fill); "keep-out problems 0"
$PY v4_gnd_split.py $W/new.kicad_pcb $W/news.kicad_pcb \
    GND_A:C6.2,C7.2,C9.2,C10.2,C17.2,C19.2,R23.2,U1.1,U1.7 \
    GND_B:C2.2,C3.2,C18.2,C4.2,J2.2,R11.2,R12.2,R13.2,U3.C2,P5.1 \
    GND_C:U2.10,U2.13,U2.24,U2.33,U4.2,U4.5,C8.2,C5.2,Q2.2,Q3.2,C15.2,C11.2,R17.2,R34.2,R35.2,R24.2,R19.2,R21.2,R28.2,D1.2,Q4.2
$PY -u v4_route_pf.py --pcb $W/news.kicad_pcb --out $W/r.kicad_pcb --fresh --skip GND --rounds 80 --debug $W/r_conf.json
zsh v4_finish.sh $W/r.kicad_pcb f                       # finisher (below) → $W/f_final.kicad_pcb, saved with filled zones
cp $W/f_final.kicad_pcb elicio-v4.kicad_pcb
cd ../.. && .venv/bin/python -m unittest discover -s tests -q && .venv/bin/python scripts/board/release.py --board elicio-v4 --routed
```

The three GND regions are the west plus C19 (GND_A), the charger corner with P5 plus C3/C18 (GND_B), and U2's core with every pad the locked GND copper touches (GND_C). On the t-0036 pass the router at round 79 had zero conflicts but reported `failed ['GND_C']`; the finisher joined its missing pieces. `v4_finish.sh` drops the conflicting copper and reconnects every net with the GND regions still live, restores the GND name, refills, runs the GND finisher with the pours as copper and the stitcher twice, adds thermal stubs, runs the soft-fill finisher on whatever is still open, and ends with a DRC with `--schematic-parity`. On t-0019 run 5 the finisher added 66 items and joined GND_A near C6.2. On t-0036 the finisher needed a soft-fill LED_EN reroute and then rejoined GND near C6.2; its final DRC has 0 errors and 0 opens and places the 5 thermal stubs of §9.3.

`build_v4.py` overwrites the PCB, routing included, so route in scratch copies. `v4_pieces.py PCB NET` lists a net's pieces with their gaps; `v4_route_pf.py --debug` writes the conflict cells, which show where a knot is. Freerouting instead: `scripts/board/route_v4.py --work DIR --route`, one run at a time, `-Xmx4g`.

## 10. Flat and folded tables

### 10.1 Flat PCB coordinates (u, s)

From `python3 hardware/board/v4_tables.py --pads` on the t-0036 routed board. Part centres, then pad by pad for the connectors, rings, J4 and SW1. The Gerber carries these (PCB x, y = u, s).

| ref | side | x (u) | y (s) | rot | footprint |
|---|---|---:|---:|---:|---|
| C1 | bottom | 13.30 | 23.65 | 90 | `Capacitor_SMD:C_0201_0603Metric` |
| C2 | bottom | 11.95 | 17.55 | 180 | `Capacitor_SMD:C_0201_0603Metric` |
| C3 | top | 14.40 | 17.20 | -90 | `Capacitor_SMD:C_0402_1005Metric` |
| C4 | bottom | 7.25 | 17.45 | 180 | `Capacitor_SMD:C_0201_0603Metric` |
| C5 | bottom | 9.85 | 23.90 | 0 | `Capacitor_SMD:C_0201_0603Metric` |
| C6 | top | 7.75 | 22.66 | 90 | `Capacitor_SMD:C_0402_1005Metric` |
| C7 | top | 8.78 | 22.66 | 90 | `Capacitor_SMD:C_0201_0603Metric` |
| C8 | bottom | 11.65 | 22.55 | 180 | `Capacitor_SMD:C_0402_1005Metric` |
| C9 | top | 10.20 | 18.50 | 90 | `Capacitor_SMD:C_0402_1005Metric` |
| C10 | top | 9.10 | 18.60 | 90 | `Capacitor_SMD:C_0201_0603Metric` |
| C11 | top | 15.10 | 23.20 | -90 | `Capacitor_SMD:C_0201_0603Metric` |
| C12 | bottom | 3.10 | 18.30 | 180 | `Capacitor_SMD:C_0201_0603Metric` |
| C13 | bottom | 4.60 | 18.30 | 180 | `Capacitor_SMD:C_0201_0603Metric` |
| C14 | bottom | 14.15 | 27.20 | 0 | `Capacitor_SMD:C_0402_1005Metric` |
| C15 | top | 13.60 | 25.15 | 0 | `Capacitor_SMD:C_0201_0603Metric` |
| C16 | bottom | 4.70 | 17.15 | 90 | `Capacitor_SMD:C_0201_0603Metric` |
| C17 | top | 11.10 | 18.60 | 90 | `Capacitor_SMD:C_0201_0603Metric` |
| C18 | bottom | 15.07 | 20.70 | -90 | `Capacitor_SMD:C_0402_1005Metric` |
| C19 | top | 14.10 | 34.20 | 90 | `Capacitor_SMD:C_0402_1005Metric` |
| D1 | bottom | 14.30 | 28.60 | 180 | `Diode_SMD:D_SOD-882` |
| D2 | top | 14.65 | 26.10 | 0 | `LED_SMD:LED_0402_1005Metric` |
| J2 | top | 5.45 | 18.90 | -90 | `Connector_Molex:Molex_Pico-EZmate_Slim_202656-0021_1x02-1MP_P1.20mm_Vertical` |
| J3 | top | 22.40 | 19.40 | 0 | `Connector_PinHeader_2.54mm:PinHeader_1x03_P2.54mm_Horizontal` |
| J4 | top | 10.00 | 35.40 | 0 | `Connector:Tag-Connect_TC2030-IDC-NL_2x03_P1.27mm_Vertical` |
| P1 | top | 5.90 | 5.29 | 0 | `elicio:RING_PAD_D5_H2.7` |
| P2 | top | 10.40 | -5.81 | 0 | `elicio:RING_PAD_D5_H2.7` |
| P3 | top | 8.50 | 43.00 | 0 | `elicio:RING_PAD_D5_H2.7` |
| P4 | bottom | 16.51 | 4.35 | 180 | `elicio:RING_1S_D4.6_NPTH2.7` |
| P5 | bottom | 16.51 | 12.10 | 180 | `elicio:RING_1S_D4.6_NPTH2.7` |
| Q1 | bottom | 9.85 | 22.80 | 0 | `Package_TO_SOT_SMD:SOT-883` |
| Q2 | bottom | 12.50 | 19.55 | 180 | `Package_TO_SOT_SMD:SOT-883` |
| Q3 | bottom | 10.65 | 19.90 | 180 | `Package_TO_SOT_SMD:SOT-883` |
| Q4 | top | 14.60 | 28.00 | 0 | `Package_TO_SOT_SMD:SOT-883` |
| R1 | bottom | 5.90 | 17.30 | -90 | `Resistor_SMD:R_0402_1005Metric` |
| R2 | bottom | 9.39 | 17.25 | 180 | `Resistor_SMD:R_0402_1005Metric` |
| R3 | bottom | 14.55 | 25.60 | 180 | `Resistor_SMD:R_0402_1005Metric` |
| R4 | bottom | 13.30 | 22.15 | -90 | `Resistor_SMD:R_0201_0603Metric` |
| R5 | top | 11.40 | 31.12 | 90 | `Resistor_SMD:R_0201_0603Metric` |
| R6 | top | 11.40 | 29.63 | 90 | `Resistor_SMD:R_0201_0603Metric` |
| R7 | top | 11.05 | 25.50 | 90 | `Resistor_SMD:R_0201_0603Metric` |
| R8 | top | 11.40 | 32.61 | 90 | `Resistor_SMD:R_0201_0603Metric` |
| R11 | bottom | 12.00 | 16.75 | 180 | `Resistor_SMD:R_0201_0603Metric` |
| R12 | top | 12.60 | 18.15 | 180 | `Resistor_SMD:R_0201_0603Metric` |
| R13 | top | 13.25 | 18.97 | 180 | `Resistor_SMD:R_0201_0603Metric` |
| R14 | bottom | 9.85 | 21.85 | 0 | `Resistor_SMD:R_0201_0603Metric` |
| R15 | bottom | 10.80 | 18.60 | -90 | `Resistor_SMD:R_0201_0603Metric` |
| R16 | bottom | 13.75 | 19.70 | -90 | `Resistor_SMD:R_0201_0603Metric` |
| R17 | bottom | 13.70 | 20.85 | 0 | `Resistor_SMD:R_0201_0603Metric` |
| R18 | bottom | 12.40 | 28.50 | 180 | `Resistor_SMD:R_0201_0603Metric` |
| R19 | bottom | 12.40 | 29.30 | 0 | `Resistor_SMD:R_0201_0603Metric` |
| R20 | bottom | 12.40 | 26.90 | 180 | `Resistor_SMD:R_0201_0603Metric` |
| R21 | bottom | 12.40 | 27.70 | 0 | `Resistor_SMD:R_0201_0603Metric` |
| R22 | top | 14.60 | 27.02 | 180 | `Resistor_SMD:R_0201_0603Metric` |
| R23 | top | 7.95 | 24.10 | 180 | `Resistor_SMD:R_0201_0603Metric` |
| R24 | bottom | 11.45 | 24.70 | 0 | `Resistor_SMD:R_0201_0603Metric` |
| R25 | bottom | 11.95 | 18.35 | 180 | `Resistor_SMD:R_0201_0603Metric` |
| R27 | top | 12.45 | 25.50 | -90 | `Resistor_SMD:R_0201_0603Metric` |
| R28 | top | 13.35 | 27.70 | 90 | `Resistor_SMD:R_0201_0603Metric` |
| R31 | top | 22.40 | 16.80 | 0 | `Resistor_SMD:R_0402_1005Metric` |
| R32 | top | 18.00 | 21.15 | 0 | `Resistor_SMD:R_0402_1005Metric` |
| R33 | top | 22.40 | 27.10 | 0 | `Resistor_SMD:R_0402_1005Metric` |
| R34 | bottom | 14.95 | 23.22 | -90 | `Resistor_SMD:R_0201_0603Metric` |
| R35 | bottom | 14.40 | 24.55 | 0 | `Resistor_SMD:R_0201_0603Metric` |
| SW1 | top | 14.45 | 31.10 | 180 | `elicio:SW_HRO_1TS015A` |
| U1 | top | 6.45 | 29.05 | -90 | `elicio:InsightSiP_ISP1807` |
| U2 | top | 11.85 | 22.08 | -90 | `elicio:Texas_RSM0032` |
| U3 | bottom | 13.90 | 17.75 | 90 | `elicio:Texas_YFP0006_V4` |
| U4 | bottom | 11.65 | 21.25 | 180 | `Package_SON:Texas_X2SON-4_1x1mm_P0.65mm` |
| U5 | bottom | 3.30 | 17.10 | 180 | `Package_SON:Texas_X2SON-4_1x1mm_P0.65mm` |

| pad | kind | net | x (u) | y (s) |
|---|---|---|---:|---:|
| J2.1 | smd | VBAT | 7.45 | 18.30 |
| J2.2 | smd | GND | 7.45 | 19.50 |
| J2.MP | smd | GND | 3.42 | 17.00 |
| J2.MP | smd | GND | 3.42 | 20.80 |
| J3.1 | thru_hole | BENCH_SIG1 | 22.40 | 19.40 |
| J3.2 | thru_hole | BENCH_SIG2 | 22.40 | 21.94 |
| J3.3 | thru_hole | BENCH_REF | 22.40 | 24.48 |
| J4.1 | connect | +VDD | 8.73 | 36.03 |
| J4.2 | connect | SWDIO | 8.73 | 34.77 |
| J4.3 | connect | GND | 10.00 | 36.03 |
| J4.4 | connect | SWDCLK | 10.00 | 34.77 |
| J4.5 | connect | GND | 11.27 | 36.03 |
| J4.6 | connect | nRESET | 11.27 | 34.77 |
| P1.1 | thru_hole | SIG1 | 5.90 | 5.29 |
| P2.1 | thru_hole | SIG2 | 10.40 | -5.81 |
| P3.1 | thru_hole | REF | 8.50 | 43.00 |
| P4.1 | smd | VBUS | 14.59 | 4.35 |
| P5.1 | smd | GND | 14.59 | 12.10 |
| SW1.1 | smd | nRESET | 14.45 | 32.73 |
| SW1.2 | smd | GND | 14.45 | 29.48 |

### 10.2 Folded shell sites (u, s, y)

From `python3 hardware/board/v4_tables.py --folded` on the t-0036 routed board. These are the prebuild board-to-shell targets, not measured clearances in the later built snap solid; see `shell-v4.md` for those checks. Shell u, s = flat u, s for everything that stays flat (the island and its parts); y comes from the thickness chain (§1.2) and the fold math (§4.4). Courtyards are line-centre boxes from the footprint text (the drawn line is 0.05 wide). The original v4 target body was the r9 shell (branch `hp/elicio/t-0001-finish-the-earpiece-shell-v2f-wp14f-from`, 1f5c8e4, not merged) with §7's changes on paper: walls u 1.5/16.5, floor 1.5, LID_Y 7.1, rib s 14.9–15.7 (y ≤ 4.5), bay s 15.7–38.2, EMG hex collars AF 8.4 (top y 3.5) at the P1/P2 sites, standoff landings R 3.2, lid posts Ø2.0, r9's SIG fold pockets and REF end-wall slot. Margins are in mm; a row passes when every margin is ≥ 0. F parts stand on the island top (y 5.12) under the lid; B parts hang from the island underside (y 5.01) over the collar top (3.5) where a collar box is below them, else over the floor (1.5). Heights are maxima from the sources in the table; the ones marked UNVERIFIED are package maxima (§11.1). The P2 lid post on U1 is by design (§5.3).

#### Courtyards on the island (flat u, s = shell u, s; y from the fold math)

| ref | side | courtyard u | courtyard s | h (source) | y | wall u | rib/end s | lid or floor y | lid post | landing | test |
|---|---|---:|---:|---|---|---:|---:|---:|---:|---:|---|
| C1 | bottom | 12.95-13.65 | 22.95-24.35 | 0.35 (0201 max, UNVERIFIED) | 4.66-5.01 | 2.85 | 7.25 | 3.16 (floor) | - | 3.91 | ok |
| C2 | bottom | 11.25-12.65 | 17.20-17.90 | 0.35 (0201 max, UNVERIFIED) | 4.66-5.01 | 3.85 | 1.50 | 3.16 (floor) | - | 3.54 | ok |
| C3 | top | 13.94-14.86 | 16.29-18.11 | 0.60 (0402 C max, UNVERIFIED) | 5.12-5.72 | 1.64 | 0.59 | 1.38 (lid) | 8.41 | - | ok |
| C4 | bottom | 6.55-7.95 | 17.10-17.80 | 0.35 (0201 max, UNVERIFIED) | 4.66-5.01 | 5.05 | 1.40 | 1.16 (collar) | - | 1.05 | ok |
| C5 | bottom | 9.15-10.55 | 23.55-24.25 | 0.35 (0201 max, UNVERIFIED) | 4.66-5.01 | 5.95 | 7.85 | 1.16 (collar) | - | 0.40 | ok |
| C6 | top | 7.29-8.21 | 21.75-23.57 | 0.60 (0402 C max, UNVERIFIED) | 5.12-5.72 | 5.79 | 6.05 | 1.38 (lid) | 0.39 | - | ok |
| C7 | top | 8.43-9.13 | 21.96-23.36 | 0.35 (0201 max, UNVERIFIED) | 5.12-5.47 | 6.93 | 6.26 | 1.63 (lid) | 1.53 | - | ok |
| C8 | bottom | 10.74-12.56 | 22.09-23.01 | 0.60 (0402 C max, UNVERIFIED) | 4.41-5.01 | 3.94 | 6.39 | 2.91 (floor) | - | 1.64 | ok |
| C9 | top | 9.74-10.66 | 17.59-19.41 | 0.60 (0402 C max, UNVERIFIED) | 5.12-5.72 | 5.84 | 1.89 | 1.38 (lid) | 4.26 | - | ok |
| C10 | top | 8.75-9.45 | 17.90-19.30 | 0.35 (0201 max, UNVERIFIED) | 5.12-5.47 | 7.05 | 2.20 | 1.63 (lid) | 3.67 | - | ok |
| C11 | top | 14.75-15.45 | 22.50-23.90 | 0.35 (0201 max, UNVERIFIED) | 5.12-5.47 | 1.05 | 6.80 | 1.63 (lid) | 7.85 | - | ok |
| C12 | bottom | 2.40-3.80 | 17.95-18.65 | 0.35 (0201 max, UNVERIFIED) | 4.66-5.01 | 0.90 | 2.25 | 1.16 (collar) | - | 0.75 | ok |
| C13 | bottom | 3.90-5.30 | 17.95-18.65 | 0.35 (0201 max, UNVERIFIED) | 4.66-5.01 | 2.40 | 2.25 | 1.16 (collar) | - | 0.20 | ok |
| C14 | bottom | 13.24-15.06 | 26.74-27.66 | 0.60 (0402 C max, UNVERIFIED) | 4.41-5.01 | 1.44 | 10.54 | 2.91 (floor) | - | 2.94 | ok |
| C15 | top | 12.90-14.30 | 24.80-25.50 | 0.35 (0201 max, UNVERIFIED) | 5.12-5.47 | 2.20 | 9.10 | 1.63 (lid) | 6.23 | - | ok |
| C16 | bottom | 4.35-5.05 | 16.45-17.85 | 0.35 (0201 max, UNVERIFIED) | 4.66-5.01 | 2.85 | 0.75 | 1.16 (collar) | - | 1.04 | ok |
| C17 | top | 10.75-11.45 | 17.90-19.30 | 0.35 (0201 max, UNVERIFIED) | 5.12-5.47 | 5.05 | 2.20 | 1.63 (lid) | 5.10 | - | ok |
| C18 | bottom | 14.61-15.53 | 19.79-21.61 | 0.60 (0402 C max, UNVERIFIED) | 4.41-5.01 | 0.97 | 4.09 | 2.91 (floor) | - | 5.52 | ok |
| C19 | top | 13.64-14.56 | 33.29-35.11 | 0.60 (0402 C max, UNVERIFIED) | 5.12-5.72 | 1.94 | 3.09 | 1.38 (lid) | 3.40 | - | ok |
| D1 | bottom | 13.50-15.10 | 28.00-29.20 | 0.50 (Nexperia SOD882 body 0.5) | 4.51-5.01 | 1.40 | 9.00 | 1.01 (collar) | - | 1.78 | ok |
| D2 | top | 13.72-15.58 | 25.63-26.57 | 0.55 (0402 LED, UNVERIFIED) | 5.12-5.67 | 0.92 | 9.93 | 1.43 (lid) | 6.02 | - | ok |
| J2 | top | 2.34-8.38 | 16.15-21.65 | 1.20 (§1.2 mated) | 5.12-6.32 | 0.84 | 0.45 | 0.78 (lid) | 0.35 | - | ok |
| J3 | top | 20.63-32.94 | 17.63-26.25 | 0.00 (no height: UNVERIFIED) | cut off with the tab (Q91) | - | - | - | - | - | exterior |
| J4 | top | 6.50-13.50 | 33.40-37.40 | 0.00 (pads only) | 5.12-5.12 | 3.00 | 0.80 | 1.98 (lid) | 0.30 | - | ok |
| Q1 | bottom | 9.15-10.55 | 22.30-23.30 | 0.40 (DFN1006 max, UNVERIFIED) | 4.61-5.01 | 5.95 | 6.60 | 1.11 (collar) | - | 0.06 | ok |
| Q2 | bottom | 11.80-13.20 | 19.05-20.05 | 0.40 (DFN1006 max, UNVERIFIED) | 4.61-5.01 | 3.30 | 3.35 | 3.11 (floor) | - | 3.01 | ok |
| Q3 | bottom | 9.95-11.35 | 19.40-20.40 | 0.40 (DFN1006 max, UNVERIFIED) | 4.61-5.01 | 5.15 | 3.70 | 1.11 (collar) | - | 1.15 | ok |
| Q4 | top | 13.90-15.30 | 27.50-28.50 | 0.40 (DFN1006 max, UNVERIFIED) | 5.12-5.52 | 1.20 | 9.70 | 1.58 (lid) | 4.76 | - | ok |
| R1 | bottom | 5.43-6.37 | 16.37-18.23 | 0.45 (0402 R max, UNVERIFIED) | 4.56-5.01 | 3.93 | 0.67 | 1.06 (collar) | - | 0.57 | ok |
| R2 | bottom | 8.46-10.32 | 16.78-17.72 | 0.45 (0402 R max, UNVERIFIED) | 4.56-5.01 | 6.18 | 1.08 | 1.06 (collar) | - | 1.79 | ok |
| R3 | bottom | 13.62-15.48 | 25.13-26.07 | 0.45 (0402 R max, UNVERIFIED) | 4.56-5.01 | 1.02 | 9.43 | 3.06 (floor) | - | 4.53 | ok |
| R4 | bottom | 12.95-13.65 | 21.45-22.85 | 0.35 (0201 max, UNVERIFIED) | 4.66-5.01 | 2.85 | 5.75 | 3.16 (floor) | - | 3.85 | ok |
| R5 | top | 11.05-11.75 | 30.42-31.82 | 0.35 (0201 max, UNVERIFIED) | 5.12-5.47 | 4.75 | 6.38 | 1.63 (lid) | 0.67 | - | ok |
| R6 | top | 11.05-11.75 | 28.93-30.33 | 0.35 (0201 max, UNVERIFIED) | 5.12-5.47 | 4.75 | 7.87 | 1.63 (lid) | 1.42 | - | ok |
| R7 | top | 10.70-11.40 | 24.80-26.20 | 0.35 (0201 max, UNVERIFIED) | 5.12-5.47 | 5.10 | 9.10 | 1.63 (lid) | 4.13 | - | ok |
| R8 | top | 11.05-11.75 | 31.91-33.31 | 0.35 (0201 max, UNVERIFIED) | 5.12-5.47 | 4.75 | 4.89 | 1.63 (lid) | 0.65 | - | ok |
| R11 | bottom | 11.30-12.70 | 16.40-17.10 | 0.35 (0201 max, UNVERIFIED) | 4.66-5.01 | 3.80 | 0.70 | 3.16 (floor) | - | 4.09 | ok |
| R12 | top | 11.90-13.30 | 17.80-18.50 | 0.35 (0201 max, UNVERIFIED) | 5.12-5.47 | 3.20 | 2.10 | 1.63 (lid) | 6.50 | - | ok |
| R13 | top | 12.55-13.95 | 18.62-19.32 | 0.35 (0201 max, UNVERIFIED) | 5.12-5.47 | 2.55 | 2.92 | 1.63 (lid) | 6.60 | - | ok |
| R14 | bottom | 9.15-10.55 | 21.50-22.20 | 0.35 (0201 max, UNVERIFIED) | 4.66-5.01 | 5.95 | 5.80 | 1.16 (collar) | - | 0.05 | ok |
| R15 | bottom | 10.45-11.15 | 17.90-19.30 | 0.35 (0201 max, UNVERIFIED) | 4.66-5.01 | 5.35 | 2.20 | 3.16 (floor) | - | 2.09 | ok |
| R16 | bottom | 13.40-14.10 | 19.00-20.40 | 0.35 (0201 max, UNVERIFIED) | 4.66-5.01 | 2.40 | 3.30 | 3.16 (floor) | - | 4.47 | ok |
| R17 | bottom | 13.00-14.40 | 20.50-21.20 | 0.35 (0201 max, UNVERIFIED) | 4.66-5.01 | 2.10 | 4.80 | 3.16 (floor) | - | 3.94 | ok |
| R18 | bottom | 11.70-13.10 | 28.15-28.85 | 0.35 (0201 max, UNVERIFIED) | 4.66-5.01 | 3.40 | 9.35 | 1.16 (collar) | - | 1.24 | ok |
| R19 | bottom | 11.70-13.10 | 28.95-29.65 | 0.35 (0201 max, UNVERIFIED) | 4.66-5.01 | 3.40 | 8.55 | 1.16 (collar) | - | 0.49 | ok |
| R20 | bottom | 11.70-13.10 | 26.55-27.25 | 0.35 (0201 max, UNVERIFIED) | 4.66-5.01 | 3.40 | 10.85 | 3.16 (floor) | - | 2.79 | ok |
| R21 | bottom | 11.70-13.10 | 27.35-28.05 | 0.35 (0201 max, UNVERIFIED) | 4.66-5.01 | 3.40 | 10.15 | 3.16 (floor) | - | 2.01 | ok |
| R22 | top | 13.90-15.30 | 26.67-27.37 | 0.35 (0201 max, UNVERIFIED) | 5.12-5.47 | 1.20 | 10.83 | 1.63 (lid) | 5.53 | - | ok |
| R23 | top | 7.25-8.65 | 23.75-24.45 | 0.35 (0201 max, UNVERIFIED) | 5.12-5.47 | 5.75 | 8.05 | 1.63 (lid) | 0.54 | - | ok |
| R24 | bottom | 10.75-12.15 | 24.35-25.05 | 0.35 (0201 max, UNVERIFIED) | 4.66-5.01 | 4.35 | 8.65 | 3.16 (floor) | - | 2.19 | ok |
| R25 | bottom | 11.25-12.65 | 18.00-18.70 | 0.35 (0201 max, UNVERIFIED) | 4.66-5.01 | 3.85 | 2.30 | 3.16 (floor) | - | 3.09 | ok |
| R27 | top | 12.10-12.80 | 24.80-26.20 | 0.35 (0201 max, UNVERIFIED) | 5.12-5.47 | 3.70 | 9.10 | 1.63 (lid) | 5.46 | - | ok |
| R28 | top | 13.00-13.70 | 27.00-28.40 | 0.35 (0201 max, UNVERIFIED) | 5.12-5.47 | 2.80 | 9.80 | 1.63 (lid) | 4.16 | - | ok |
| R31 | top | 21.47-23.33 | 16.33-17.27 | 0.45 (0402 R max, UNVERIFIED) | cut off with the tab (Q91) | - | - | - | - | - | exterior |
| R32 | top | 17.07-18.93 | 20.68-21.62 | 0.45 (0402 R max, UNVERIFIED) | cut off with the tab (Q91) | - | - | - | - | - | exterior |
| R33 | top | 21.47-23.33 | 26.63-27.57 | 0.45 (0402 R max, UNVERIFIED) | cut off with the tab (Q91) | - | - | - | - | - | exterior |
| R34 | bottom | 14.60-15.30 | 22.52-23.92 | 0.35 (0201 max, UNVERIFIED) | 4.66-5.01 | 1.20 | 6.82 | 3.16 (floor) | - | 5.52 | ok |
| R35 | bottom | 13.70-15.10 | 24.20-24.90 | 0.35 (0201 max, UNVERIFIED) | 4.66-5.01 | 1.40 | 8.50 | 3.16 (floor) | - | 4.90 | ok |
| SW1 | top | 13.20-15.70 | 28.95-33.25 | 0.60 (§1.2) | 5.12-5.72 | 0.80 | 4.95 | 1.38 (lid) | 2.80 | - | ok |
| U1 | top | 2.20-10.70 | 24.80-33.30 | 1.00 (§1.2) | 5.12-6.12 | 0.70 | 4.90 | 0.98 (lid) | -1.00 (post on the part) | - | ok |
| U2 | top | 9.22-14.48 | 19.45-24.71 | 1.00 (TI RSM) | 5.12-6.12 | 2.02 | 3.75 | 0.98 (lid) | 2.32 | - | ok |
| U3 | bottom | 12.84-14.96 | 16.95-18.55 | 0.63 (TI YFP, UNVERIFIED) | 4.38-5.01 | 1.54 | 1.25 | 2.88 (floor) | - | 4.55 | ok |
| U4 | bottom | 10.74-12.56 | 20.50-22.00 | 0.40 (TI DQN) | 4.61-5.01 | 3.94 | 4.80 | 3.11 (floor) | - | 1.64 | ok |
| U5 | bottom | 2.39-4.21 | 16.35-17.85 | 0.40 (TI DQN) | 4.61-5.01 | 0.89 | 0.65 | 1.11 (collar) | - | 1.28 | ok |

Smallest courtyard margin: 0.45 mm.
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

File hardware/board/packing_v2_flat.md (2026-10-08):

# Pin table v3 — flat PCB coordinates (WP12i)

Copied from packing-v2.md §5e at `e0eef82`.
Board pins this table. The folded-site table is the shell's and is not copied.
§5d in packing-v2.md is the frozen v2.1 table. §5e is live.

## 5e. Flat pattern v3 and pin table v3 (WP11g, Q90–Q95, Q97, Q98)

Build cell: process-edge, width 22, chord 47.90, two sides, fold neck, no receptacle (Q81). Island u 2.25–19.75, s 16.00–37.60. Leftover s 16.05–20.90. The flex board is drawn flat. Pin table v3 below is what the board lane pins.

Posterior wall: u 20.50–22.00. montage.md §2.1: u is the posterior offset from the body's anterior edge (u = 0). shell-v2.md: the hook root sits at low u on the hook-end face and the hook curves forward over the top of the ear. params/default.toml HOOK_ROOT_X = 4.0. packing-v2.md: the hook root occupies u up to 6.39. The far wall from that root is the posterior edge hidden behind the ear, so P4/P5 go there (Q90). The anterior wall u 0–1.50 is not used. The hook-end end-face fallback is not used.

Fold allowance: inner R 1.5 mm, stack 0.31 mm (PI 0.11 + FR4 0.2). Arc at R for a 180° SIG fold is πR = 4.71 mm. Midplane arc π(R + t/2) = 5.20 mm. Q83 strip lengths use πR, so SIG1 10.71 mm and SIG2 21.81 mm stay. The CHARGE tab uses one 90° at R 1.5: πR/2 = 2.36 mm plus wall run 0.46 mm (island underside 4.81 to pad y 4.35).

Flat-to-folded mapping (neck-end, Q83): each SIG strip leaves the island at (contact u, s=16.00) toward −s. The ring centre in PCB coordinates is (contact u, s0 − L_flat). A 180° fold at R 1.5 at the neck puts the ring on the floor at the contact site. REF does not take that fold: it already leaves the island high-s end (s=37.60) through the end-wall slot, so P3 flat = P3 folded. P4 and P5 cannot sit on that tail (largest tail pair Ø2.1) and they cannot sit on the skin face (Q90). The CHARGE tab leaves the pocket island's high-u edge (the inner face of the posterior wall), folds 90° at R 1.5 onto that wall's inner face, and carries RING_PAD_D5_H2.7 clamped button-heads: head through the 1.50 wall, ring on the inner face, 3.0 standoff into the bay. It does not use J2's hang and it does not use the leftover rib slot (Q92). P4 flat (23.32, 4.35); P5 flat (23.32, 12.35).

| strip | attach (u, s) | flat ring (u, s) | flat rectangle centre wu × ws | folded run | L_flat |
|---|---|---|---|---:|---:|
| SIG1 | (5.90, 16.00) | (5.90, 5.29) | (5.90, 10.64) 2.50 × 10.71 | 6.00 | 10.71 |
| SIG2 | (10.40, 16.00) | (10.40, -5.81) | (10.40, 5.09) 2.50 × 21.81 | 17.10 | 21.81 |
| REF | (8.50, 37.60) | (8.50, 43.00) | (8.50, 40.30) 2.50 × 5.40 | 5.40 | 5.40 |
| CHARGE | pocket high-u edge (20.50, s 4.35–12.35) | P4 (23.32, 4.35); P5 (23.32, 12.35) | (23.32, 8.35) 5.64 × 13.64 | wall run 0.46 | 2.82 |

2D check: the flat pattern does not self-overlap. No SIG, REF or CHARGE strip crosses a part on either side of the leftover or the pocket. P1–P5 flat centres sit outside every other courtyard. Neck-end is the SIG exit. Side-wall pockets stay refused (remaining wall 0.65 mm < 1.0).

Cavity test: every courtyard, hang and folded-board region lies inside the cavity (u 1.50–20.50) or on a declared exterior. Declared exteriors: the SIG strips before folding, and the J3 break-off tab. Remove the J3 break-off tab after programming and before closing the shell.

J2 (JST-SH) is inside the cavity at (15.15, 11.35) rot 0; the cell connector is reachable from that site.
J3 sits on a break-off tab at (28.41, 26.80) rot 0, joined by a 2.5 mm neck. Cut line at u = 22.25, s = 26.80. Remove the J3 break-off tab after programming and before closing the shell.
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

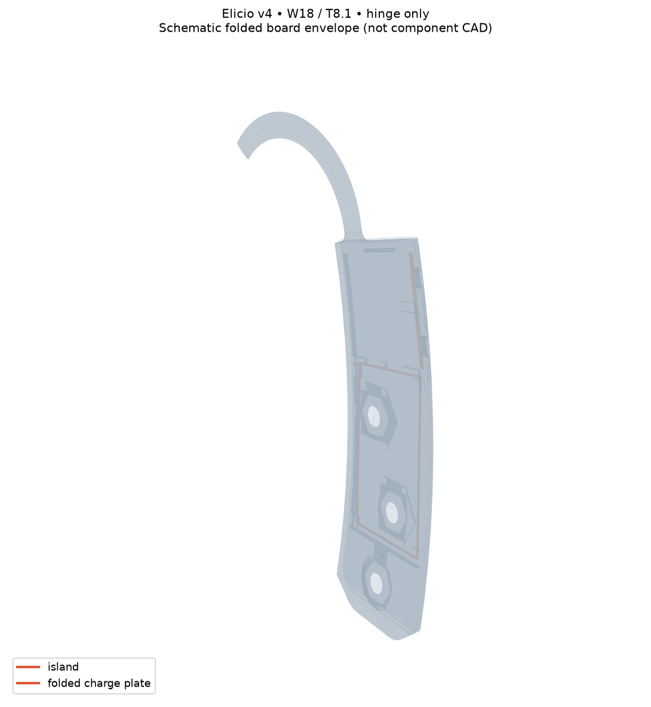
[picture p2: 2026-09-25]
docs/fab/cad/v4/render_folded_board.png

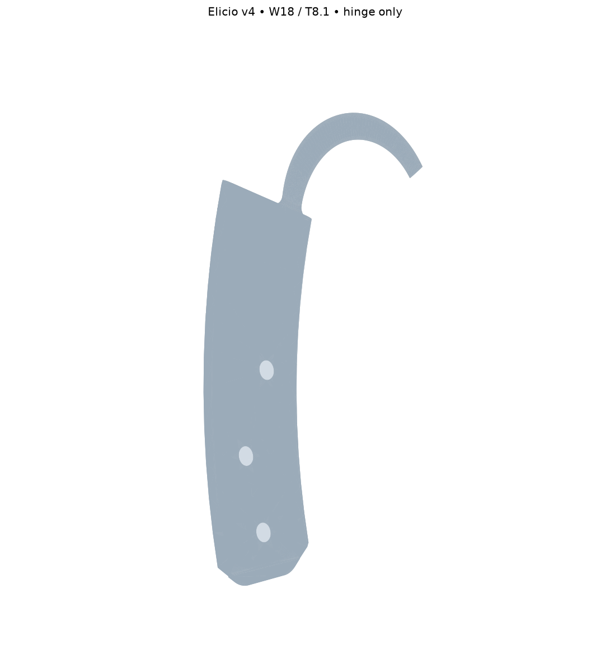
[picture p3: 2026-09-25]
docs/fab/cad/v4/render_lateral.png

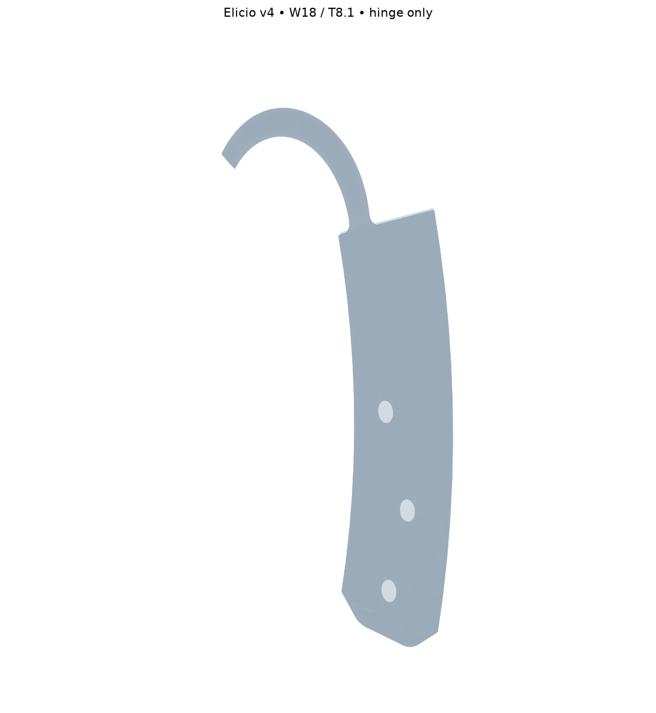
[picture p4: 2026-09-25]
docs/fab/cad/v4/render_medial.png

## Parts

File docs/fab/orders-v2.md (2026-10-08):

# Earpiece delivered-cost worksheet — routed v4 + built 18 mm shell, Massachusetts

**Planning total, USD: $744.27 low / $1,318.68 likely / $3,125.92 high.** The three largest likely drivers are the board delivered ($526.78), small parts including the custom fitted cell and 100-pack of spacers ($483), and purchase/forwarding of consigned parts ($179). Board fabrication/acceptance, unverified externally sourced parts, the custom fitted cell, PA12 print/finish, freight, import and tax **remain ranges**: none is a complete delivered checkout price. High is an allowance, **not** a guaranteed delivered maximum or a quote. The board has 63 placed components of 27 types after the charger-ESD change; the selected shell is the *built* 18 mm snap trial, not the older 22 mm mesh. **No order** until the other fit, electrical, supplier and delivered-price checks below are complete.

Public pages were read **2026-09-25**, in USD unless stated otherwise. No upload, account, quote request, vendor contact or purchase was made. `UNVERIFIED` denotes an explicit planning interval rather than a vendor price. Superseded v2 checkout sheets have been removed. This worksheet is a historical estimate, not a v4 checkout. No manual final assembly labor, failed-board rerun, new engineering labor, medical certification or skin approval is included.

## Built evidence and price-source key

`hardware/board/v4_parts.py`, the released `hardware/board/elicio-v4.kicad_pcb`, and the [2026-09-25 orderable BOM](bom-v4-orderable.md) have **63 BOM placements, 27 types**: 3 consigned types (U1, U3, J2) and 24 stocked JLC types (1 Basic, 23 Extended), covering 60 of 63 fitted positions. J4 and P1–P5 are copper/contact footprints, not purchased parts; J3 is the only through-hole placement. Parsing the released board footprints for all 63 BOM references yields **341 SMT pads + 3 through-hole pads per board**, i.e. 1,705 SMT joints and 15 manual joints for five boards. These are *pad-based* estimates, not an assembly acceptance or an assertion every pad is billable. Both sides assembled on two-layer ENIG flex; six FR4 stiffeners still require JLC approval. The bare-board fabrication cost is dynamic, not obtainable from a public fixed-price schedule without submitting files.

- **J**, all read 2026-09-25: [JLC PCBA public schedule](https://jlcpcb.com/help/article/pcb-assembly-price) (Standard PCBA: double-side setup $51.12, double stencil $16.42, flexible-PCB two fixtures $49.25 at 1–29 pcs, pre-reflow $0.016/joint, SMT $0.0016/joint, manual $0.0164/joint and $3.58 hand-solder labor, feeder loading **$1.53 per Basic/Extended type**, confirmation $0.45, packing $0.50 plus area), [Basic vs Extended](https://jlcpcb.com/help/article/pcb-assembly-basic-parts-vs-extended-parts), [flex charges](https://jlcpcb.com/help/article/fpc-extra-charges), [consignment terms](https://jlcpcb.com/help/article/consigned-parts-service-introduction), [flex capability](https://jlcpcb.com/capabilities/flex-pcb-capabilities). The $8.14 stacked-stiffener fee is **not** a quote for these six ordinary stiffeners. JLC does not promise to assemble the consigned parts or 0201-on-flex at these rates.
- **P**, read 2026-09-25: [JLC3DP PA12-HP MJF](https://jlc3dp.com/help/article/pa12-hp-nylon) advertises **from $1.00**, tolerance ±0.3 mm (under 100 mm), minimum wall 1 mm, *not* a price for this body or either lid. [US MJF alternative](https://www.xometry.com/capabilities/3d-printing/hp-mjf/) has no public matching delivered price. Prior v2 mesh illustration ($1.21 material + $2 process + $4.50 dye, read 2026-09-24) is **not** a quote or upper bound for v4.
- **D/S/B/K**, source status: [Mouser U1](https://www.mouser.com/ProductDetail/Insight-SiP/ISP1807-LR-RS) blocked/403 on 2026-09-25; [TI U3 exact YFPR offer](https://www.ti.com/product/BQ25100/part-details/BQ25100YFPR) public JSON-LD says InStock, $0.744 each (2026-09-25), without a public count or landed cost; [Molex J2 drawing](https://www.molex.com/content/dam/molex/molex-dot-com/products/automated/en-us/salesdrawingpdf/202/202656/2026560021_sd.pdf) has no unit offer. U1 $13.65/J2 $0.75 are **old unverified comparators**, not newly page-read prices. [Sortafast M2.5×4 ten-pack](https://sortafast.com/products/sortafast-titanium-screws-button-head-10pk-m2-5) $17.50/10, sold out (read 2026-09-24); [Spacer Express LAI-FF-M2.5-SW5-L3-100](https://spacer-express.com/female-female/875-hexagonal-female-female-threaded-spacer-nickel-plated-brass-m2-5-5-mm-across-flats.html) **€82.80 ex VAT/100**, refreshed 2026-09-25 (the former €91.08 figure changed; product page structured offer shows €82.80). [PKCELL custom packs](https://www.pkcell.com/product-category/custom-battery-pack/) and [EEMB custom service](https://www.eemb.com/service/7), rechecked 2026-09-25, offer no one-unit fitted 501012 price. [Tag-Connect TC2030-IDC-NL](https://www.tag-connect.com/product/tc2030-idc-nl) $33.95 and [Adafruit Debug Probe](https://www.adafruit.com/product/5699) $12 (read 2026-09-24); jumper $1.95 remains an unverified estimate.

### Part basket (one board ×5; JLC public catalogue unit prices)

The [orderable BOM](bom-v4-orderable.md) records public JLC JSON search first-tier prices, class and observed warehouse stock on **2026-09-25**; linked part pages identify the codes. Quantity in the `×5` column is five boards' *placements*, **not** a confirmed minimum purchase, feeder waste or order price. Prices are USD per component. `0` or `<qty` stock is flagged; warehouse figures change. Every `CONSIGNED` row is **not** assigned a JLC price, even if a similarly named catalogue entry exists. Code and placement grouping reflect the merged `v4_parts.py`, not a substituted design.

| Refs / value | JLC/LCSC code; class | Qty ×5 | First tier; stock (2026-09-25 BOM) | Evidence |
| --- | --- | ---: | --- | --- |
| U1 ISP1807-LR-RS | CONSIGNED; n/a | 5 | UNVERIFIED $13.65 prior comparator; six purchased for attrition | D |
| U2 ADS1292IRSMT | C89288; Extended | 5 | $6.4422 (1–9); 97 | [part](https://jlcpcb.com/partdetail/C89288) |
| U3 BQ25100YFPR | CONSIGNED; JLC C527572 out of stock | 5 | TI $0.744 public offer, count/landed price unverified | [TI](https://www.ti.com/product/BQ25100/part-details/BQ25100YFPR) |
| U4 TLV71330PDQNR | C2863576; Extended | 5 | $0.0959; 990 | [part](https://jlcpcb.com/partdetail/C2863576) |
| U5 TPS7A0230PDQNR | C2867950; Extended | 5 | $0.8201; 385 | [part](https://jlcpcb.com/partdetail/C2867950) |
| Q1 WPM3027-3/TR | C240195; Extended | 5 | $0.0400 (1–199); 9,846 | [part](https://jlcpcb.com/partdetail/C240195) |
| Q2–Q4 PMZ290UNE2YL | C478155; Extended | 15 | $0.0553 (1–49); 2,712 | [part](https://jlcpcb.com/partdetail/C478155) |
| D1 PESD5V0L1UL | C3001948; Extended | 5 | $0.0281; 7,525 | [part](https://jlcpcb.com/partdetail/C3001948) |
| D2 LED LTST-C281TGKT-5A | C364549; Extended | 5 | $0.0761; 7,490 | [part](https://jlcpcb.com/partdetail/C364549) |
| J2 202656-0021 | CONSIGNED; n/a | 5 | UNVERIFIED $0.75 prior comparator; ten purchased | D |
| J3 2.54-1*3PPin | C49257; Extended | 5 | $0.0275 (1–199); 225,530 | [part](https://jlcpcb.com/partdetail/C49257) |
| SW1 1TS015A-1200-0600-CT | C398746; Extended | 5 | $0.0835 (1–49); 233 | [part](https://jlcpcb.com/partdetail/C398746) |
| R1–R3, R31–R33 220k 0402 | C881401; Extended | 30 | $0.0012 (1–999); 9,884 | [part](https://jlcpcb.com/partdetail/C881401) |
| R4,R17,R20,R21 1M 0201 | C473482; Extended | 20 | $0.0015 (1–999); 357,802 | [part](https://jlcpcb.com/partdetail/C473482) |
| R5–R8,R13,R25,R27,R28,R34,R35 10k 0201 | C473048; Extended | 50 | $0.0014 (1–999); 10,079,955 | [part](https://jlcpcb.com/partdetail/C473048) |
| R11 6.8k 0201 | C423451; Extended | 5 | $0.0016; 3,602 | [part](https://jlcpcb.com/partdetail/C423451) |
| R12 6.04k 0201 | C270341; Extended | 5 | $0.0014 (1–999); 149,721 | [part](https://jlcpcb.com/partdetail/C270341) |
| R14–R16,R23,R24 100k 0201 | C270364; Extended | 25 | $0.0015 (1–999); 518,206 | [part](https://jlcpcb.com/partdetail/C270364) |
| R18 47k 0201 | C270345; Extended | 5 | $0.0015; 163,838 | [part](https://jlcpcb.com/partdetail/C270345) |
| R19 27k 0201 | C270351; Extended | 5 | $0.0013; 63,170 | [part](https://jlcpcb.com/partdetail/C270351) |
| R22 1k 0201 | C270365; Extended | 5 | $0.0013 (1–999); 1,858,760 | [part](https://jlcpcb.com/partdetail/C270365) |
| C1 1.5nF 0201 | C285104; Extended | 5 | $0.0014 (1–999); 26,563 | [part](https://jlcpcb.com/partdetail/C285104) |
| C2 10nF 0201 | C5142551; Extended | 5 | $0.0012; 2,003,754 | [part](https://jlcpcb.com/partdetail/C5142551) |
| C3,C14,C18,C19 GRM155R61A106ME18D 10uF 0402 | C36626211; Extended | 20 | $0.4216; 137 | [part](https://jlcpcb.com/partdetail/C36626211) |
| C4,C5,C10,C11,C13,C16 1uF 0201 | C5142566; Extended | 30 | $0.0052 (1–499); 347,988 | [part](https://jlcpcb.com/partdetail/C5142566) |
| C6,C8,C9 10uF 0402 | C15525; **Basic** | 15 | $0.0255 (1–999); 8,666,050; **different MPN from ESD caps** | [part](https://jlcpcb.com/partdetail/C15525) |
| C7,C12,C15,C17 100nF 0201 | C307380; Extended | 20 | $0.0061 (1–999); 995,573 | [part](https://jlcpcb.com/partdetail/C307380) |

**Basket arithmetic (2026-09-25 [orderable BOM](bom-v4-orderable.md)):** 5 × $9.6422 = **$48.211** in stocked JLC components (60 positions per board). Rounded to cents, $48.21 + **UNVERIFIED** $7.73/$37.73/$117.73 for minimum buys, attrition and price/stock movement = **$55.94/$85.94/$165.94**. These reserves are planning assumptions, not public prices or a guaranteed purchasable basket. U1, exact U3 and J2 are excluded and purchased below; none is bought again in this basket. Stock is not reserved and assembly acceptance remains open.

## Delivered order estimates (USD)

Each row marked UNVERIFIED remains a range even where its cited public schedule supplies one input. Column sums below count all services and parcels once. Public schedule J is **Standard**, not the Economic-only $3.07 Extended feeder charge. For five boards, 1 Basic + 23 Extended stocked + 3 consigned types = 27 types (2026-09-25 BOM); at J's $1.53 Standard rate (2026-09-25), 24 JLC types × $1.53 = $36.72 and, if charged equally, 3 consigned × $1.53 = $4.59, total $41.31. Consigned feeder applicability remains unverified; if JLC applies a different classification, reprice. The 2026-09-25 J Standard two-sided setup remains one $51.12 charge (not 27 × $51.12); stencil remains one $16.42 charge, so no setup delta follows from the type mix. The X-ray count assumes U1 only; other leadless packages could increase it. J3 manual assembly is 15 pads × $0.0164 + $3.58 = $3.83 rounded. JLC may refuse consignment, through-hole header or 0201 flex; acceptance is open.

### 1 — China JLC board order, five two-sided assembled flex boards

| Charge, source and arithmetic (UNVERIFIED unless public schedule explicitly says fixed) | Low | Likely | High |
| --- | ---: | ---: | ---: |
| ENIG two-layer flex fabrication ×5; J dynamic/no files submitted | 15 | 25 | 90 |
| Six ordinary FR4 stiffeners; J no price for this geometry | 8 | 20 | 70 |
| Standard double-side assembly setup; 2026-09-25 J, 1 × $51.12 | 51.12 | 51.12 | 80 |
| Double-side stencil; J $16.42 | 16.42 | 16.42 | 40 |
| Two flexible carriers/fixtures; J $24.63 ×2 = $49.25 schedule | 49.25 | 49.25 | 120 |
| Pre-reflow; 1,705 pads × J $0.016 = $27.28 | 27.28 | 27.28 | 27.28 |
| SMT assembly; 1,705 pads × J $0.0016 = $2.728 | 2.73 | 2.73 | 10 |
| J3 manual pads + hand-solder labor; 15 × J $0.0164 + $3.58 ≈ $3.83 | 3.83 | 3.83 | 25 |
| Standard feeder; 2026-09-25 J/BOM: (1 Basic + 23 Extended + 3 consigned) × $1.53 = $41.31 if consigned charged; high UNVERIFIED | 41.31 | 41.31 | 90 |
| JLC handling of 3 consigned types; 2026-09-25 BOM/J, UNVERIFIED 3/4 × prior $12/$30/$75 reserve | 9 | 22.50 | 56.25 |
| JLC parts basket; 2026-09-25 BOM: 5 × $9.6422 = $48.211 ≈ $48.21 + UNVERIFIED $7.73/$37.73/$117.73 | 55.94 | 85.94 | 165.94 |
| U1 X-ray; 5 × J $1.64 = $8.20, more packages may qualify | 8.20 | 8.20 | 40 |
| J part-placement confirmation $0.45 + packing at least $0.50 | 0.95 | 0.95 | 0.95 |
| Rails, tooling, feeder attrition, factory image (unpriced) | 0 | 30 | 150 |
| [JLC shipping methods](https://jlcpcb.com/help/article/shipping-methods), no MA price; parcel range | 18 | 35 | 85 |
| China→US board duty, 2026-09-25 BOM/import: prior $0/$70/$220 less 25% × ($0/$11/$26) decrease in purchased consignment value = $0/$67.25/$213.50; declared value/heading UNVERIFIED | 0 | 67.25 | 213.50 |
| Carrier entry/disbursement, no verified schedule for this parcel | 0 | 20 | 65 |
| MA sales/use tax on taxable portion, less collected tax credit | 0 | 20 | 45 |
| **Order 1 delivered (2026-09-25; sum above)** | **307.03** | **526.78** | **1,373.92** |

### 1a — buy and directly forward three consigned types to JLC China

| Charge (2026-09-25 D/[BOM](bom-v4-orderable.md); all landed amounts UNVERIFIED; purchased units not only fitted) | Low | Likely | High |
| --- | ---: | ---: | ---: |
| U1 six × prior $13.65 = $81.90 low; unverified price/attrition reserve | 81.90 | 100 | 150 |
| U3 exact BQ25100YFPR, ten × TI $0.744 = $7.44 low; unverified minimum/availability/landed price | 7.44 | 12 | 32 |
| J2 ten × prior $0.75 = $7.50 low; unverified price/attrition reserve | 7.50 | 12 | 32 |
| Tracked distributor(s) → JLC parcel; prior UNVERIFIED route allowance retained | 20 | 40 | 90 |
| Export forwarding/China customs; prior UNVERIFIED route allowance retained | 0 | 15 | 50 |
| **Order 1a direct export (2026-09-25; sum above)** | **116.84** | **179.00** | **354.00** |

If shipment must first go to a Massachusetts forwarder instead, **add** domestic freight $0/$12/$25 and possible MA tax $6/$9/$15 (2026-09-25, prior UNVERIFIED allowances): order 1a **$122.84/$200/$394**; choose one route. Whether a single distributor can supply all three, including TI's exact charger, is unverified; extra parcels would exceed this allowance. Board customs may include the value of these components but the board order does **not** repurchase them. No second US duty on a genuine direct export.

### 2 — built 18 mm PA12 snap shell, one body + two lids

Remeasured 2026-09-25 with `build123d.import_step` in repo CAD environment (build123d 0.11.1, cadquery-ocp-novtk 7.9.3.1.1 via uv) on the **current post-relief** `docs/fab/cad/v4-snap/body_full_p15.step` and `lid.step`. Units mm, mm³; axis-aligned STEP boxes include hook/hinge, not merely the nominal W18 × T8.1 package. The reliefs do not change the outer bounds.

| Solid | Current STEP volume (2026-09-25) | Bounding min (x,y,z) | Bounding max (x,y,z) | Box size |
| --- | ---: | --- | --- | --- |
| Body | 3,340.226 mm³ | (−21.787, −1.554, −51.346) | (21.000, 7.235, 15.344) | 42.787 × 8.789 × 66.690 mm |
| Lid, each ×2 | 900.187 mm³ | (0.096, 1.764, −49.925) | (20.850, 8.234, 4.408) | 20.754 × 6.470 × 54.333 mm |
| **One body + two lids (3,340.225633 + 2 × 900.186925)** | **5,140.599 mm³ = 5.141 cm³** | — | — | Three separate printed parts |

This is the `v4-snap` *print-trial candidate* with Rolf's preferred flat 1 mm lid; no lid screw is bought. The 1.5 mm hex key below remains for releasing the latch. This estimate uses the current reference body length. Personal fit is unmeasured. This line covers only the current solid and may change after physical fit review. `docs/fab/shell-v4.md` reports **0.42 mm minimum nominal free chip-to-shell clearance** after the reliefs (U1 deliberately seats on P2); the published ±0.3 mm print tolerance still calls for physical clearance checks, and latch, retention and fit are not proven. No solid was uploaded to a print vendor for a quote. P only offers **from $1**, not a formula for minimum processing, orientation, dye, three-part packing or chargeable bounding volume. The old v2 $3.21 undyed illustration is a scale comparator, not this shell's price; $5/$12/$45 print is a reasoned **UNVERIFIED** low/likely/high for 5.14 cm³ and three small parts, not a JLC3DP unit rate. Low omits optional black finish; likely includes it.

| Charge, P or import section; all UNVERIFIED | Low | Likely | High |
| --- | ---: | ---: | ---: |
| PA12 MJF print, one body + two lids (P from $1 per part only) | 5 | 12 | 45 |
| Black finish; old-shell $4.50 comparator, optional in low | 0 | 5 | 15 |
| Separate JLC3DP→MA parcel; no public case price | 12 | 22 | 55 |
| China-origin shell duty on goods, heading open | 0 | 3 | 16 |
| Separate carrier brokerage if billed | 0 | 15 | 50 |
| MA tax less any seller-collected tax | 0 | 1 | 4 |
| **Order 2 delivered** | **$17** | **$58** | **$185** |

A US-printed shell is an **alternative**, not added to China route: print/finish $30/$100/$250, freight $0/$18/$40, MA tax $2/$8/$20, all UNVERIFIED (P US alternative page): **$32/$126/$310 delivered** if actually US-made. It would replace order 2 and have no US import duty/brokerage.

### 3 — small parts, purchased packs (not pieces consumed)

All delivered rows UNVERIFIED even when a catalogue price is cited. **S** and **B** source key above; other items have no selected SKU, so the row states why it is a range. The snap lid has **no lid screw**; the five skin/charge screws remain, with length/source to qualify. The 1.5 mm hex key is kept for the latch. 3.0 mm standoff height is not qualified. Charging is **off the ear only**; the released board retains fixed R13 10k on TS and a **two-wire J2**, so the priced cell requires **no temperature sensor or thermistor**. A factory-fitted **protected** ~40 mAh 501012-class two-wire cell with polarity-verified Pico-EZmate Slim mating plug is mandatory; bare cell plus loose pre-crimps are not acceptable. Battery shipping may require a separate regulated parcel.

| Charge and basis | Low | Likely | High |
| --- | ---: | ---: | ---: |
| Skin/charge screws, S $17.50 ten-pack sold out; substitute needed | 17.50 | 25 | 50 |
| Three standoffs bought as **100**, S €82.80 ex VAT; FX/stock/freight uncertainty remains | 100 | 115 | 155 |
| Factory-fitted protected **two-wire, no temperature-sensor** cell; B no one-unit offer/setup/MOQ | 35 | 90 | 250 |
| Insulated P4/P5 charge cable, spacing 7.75 mm; drawing/source open | 10 | 25 | 60 |
| Electrode leads, snaps, gel; unselected packs | 15 | 35 | 80 |
| Pre-cut foam, 1.5 mm hex key, insulated consumables; no SKU | 10 | 25 | 50 |
| Nickel screen or Rolf's written waiver (low = waiver) | 0 | 25 | 55 |
| Multimeter if not owned (low/likely assume owned) | 0 | 0 | 30 |
| Protected-cell separate parcel/regulated handling, unknown origin | 12 | 25 | 70 |
| EU spacer parcel to MA, separate supplier | 20 | 40 | 90 |
| Other US small-parts parcels combined | 15 | 40 | 100 |
| Spacer import duty + carrier fees, origin/classification unconfirmed | 0 | 20 | 60 |
| MA tax on taxable parts less collected tax credit | 8 | 18 | 40 |
| **Order 3 delivered** | **$242.50** | **$483** | **$1,090** |

If the custom maker requires more than the high cell allowance, this worksheet's high is exceeded. Cell country of origin and import treatment are not proved covered by the small-parts interval; resolve before ordering.

### 4 — conditional first-load kit (included in totals)

**K** key above, read date as stated there; all delivered amounts UNVERIFIED. J4 wiring and measured v4 target voltage/probe suitability require verification before purchase; do not apply a fixed-3.3 V probe to the erased 1.8 V v2 module. The v4 has a 3.0 V U5 supply at power-up but this is **not** approval of the kit.

| Charge and basis | Low | Likely | High |
| --- | ---: | ---: | ---: |
| Tag-Connect cable, K $33.95 catalogue, stock/variant open | 33.95 | 33.95 | 45 |
| Adafruit probe, K $12 catalogue, J4/voltage approval open | 12 | 12 | 20 |
| Jumpers, old unverified $1.95 estimate | 1.95 | 1.95 | 5 |
| Two separate US-seller parcels | 10 | 20 | 45 |
| MA tax less seller-collected tax | 3 | 4 | 8 |
| **Order 4 if needed** | **$60.90** | **$71.90** | **$123** |

Only if the assembler supplies and verifies the factory image can order 4 be removed; on the 2026-09-25 BOM basis, subtract $60.90/$71.90/$123 from the totals below: **$683.37/$1,246.78/$3,002.92**. This is not a claim factory programming is included.

## Import, freight and stop rule

[Executive Order 14324](https://www.whitehouse.gov/presidential-actions/2025/07/suspending-duty-free-de-minimis-treatment-for-all-countries/) and [CBP guidance](https://content.govdelivery.com/accounts/USDHSCBP/bulletins/41fa7f0) (read 2026-09-25) suspend duty-free de minimis from 2025-08-29; being below $800 does **not** make a parcel automatically duty-free. [USITC candidates 8517.62](https://hts.usitc.gov/reststop/search?keyword=8517.62), [9018.19](https://hts.usitc.gov/reststop/search?keyword=9018.19) (board, general Free) and [3926.90.99](https://hts.usitc.gov/reststop/search?keyword=3926.90.99) (plastic shell, general 5.3%) were read 2026-09-25; none is a binding product classification. [USTR List 3](https://ustr.gov/sites/default/files/enforcement/301Investigations/83%20FR%2047974.pdf) lists 8517.62.00 **except suffix .0090**; [25% modification](https://ustr.gov/sites/default/files/enforcement/301Investigations/84_FR_20459.pdf). [USTR List 4](https://ustr.gov/sites/default/files/enforcement/301Investigations/Notice_of_Modification_%28List_4A_and_List_4B%29.pdf) and [USITC 9903.88.15](https://hts.usitc.gov/reststop/search?keyword=9903.88.15) show 7.5% on candidate shell heading 3926.90.99. Read 2026-09-25. Model board 0–25% potential Section 301 and shell candidate 5.3% + 7.5% = 12.8% on applicable *goods* values, plus an **UNVERIFIED 0–12.5% contingency** for any other applicable measure until primary notice and origin/classification are confirmed; do **not** charge all rates as facts. Board duty includes declared consigned value once (2026-09-25 planning illustration: purchased consignment $96.84/$124/$214 vs prior $100.60/$135/$240; at an illustrative 25% marginal duty, the likely/high reserves drop $2.75/$6.50, while the low remains $0). Actual declaration may be based on fitted rather than all purchased units; reserve must be reconciled with the entry. Low $0 duty models a confirmed alternate heading/exclusion or a fully prepaid DDP *incremental* charge, not de minimis. Actual tariff stacks, seller DDP terms, MA 6.25% taxable base and carrier fees remain unsettled.

[JLC shipping methods](https://jlcpcb.com/help/article/shipping-methods) and [US tariff FAQ](https://jlcpcb.com/help/article/u-s-tariff-policy-faq), read 2026-09-25, provide no MA freight price for this board. Board $18–85, shell $12–55, distributor(s)→JLC $20–90 and EU spacers $20–90 are separate parcel allowances, **not** shipping offers. [UPS fees](https://www.ups.com/us/en/shipping/international-shipping/import-fees.page) and [FedEx ancillary clearance](https://www.fedex.com/en-us/ancillary-clearance-service.html) were blocked on this machine (2026-09-25); board $0/$20/$65, shell $0/$15/$50 and spacer combined duty/fee $0/$20/$60 are unverified per-parcel reserves, $0 only when confirmed prepaid/no bill. No freight or tax is silently waived by a DDP label; apply credit for tax already collected once.

**Column arithmetic, China snap shell + direct-export consignment + first-load kit:**

| Delivered order | Low | Likely | High |
| --- | ---: | ---: | ---: |
| 1 board (2026-09-25; sum §1) | 307.03 | 526.78 | 1,373.92 |
| 1a consigned parts (2026-09-25; sum §1a) | 116.84 | 179.00 | 354.00 |
| 2 snap shell | 17.00 | 58.00 | 185.00 |
| 3 small parts | 242.50 | 483.00 | 1,090.00 |
| 4 first load | 60.90 | 71.90 | 123.00 |
| **Sum (2026-09-25)** | **$744.27** | **$1,318.68** | **$3,125.92** |

Low **307.03 + 116.84 + 17 + 242.50 + 60.90 = 744.27**; likely **526.78 + 179 + 58 + 483 + 71.90 = 1,318.68**; high **1,373.92 + 354 + 185 + 1,090 + 123 = 3,125.92** (2026-09-25 BOM and unchanged shell/parts/kit allowances). Replacing China shell only with the unverified US-made alternative gives **$759.27/$1,386.68/$3,250.92** (add $15/$68/$125). No row is a final checkout ledger. The shell remains a print trial, not a qualified wearable release; confirmed printed fit, latch strength and any revised CAD may change its price.

### Live G8 delivered-cost record — **open; do not order**

This record is for supported route-specific costs once design choices and checkout evidence exist. The planning high above is not a spending cap or a completed checkout. Reserve a supported, complete shell delivered amount before paying for boards or parts.

| Required delivered amount (USD) | SKU/route, quantity, dated evidence | Goods + services | Freight | Import/carrier | MA tax | Delivered amount |
| --- | --- | ---: | ---: | ---: | ---: | ---: |
| Board, tooling, programming, consignment handling | pending | pending | pending | pending | pending | pending |
| Three consigned types, one forward route (2026-09-25 BOM) | pending | pending | pending | pending | pending | pending |
| Snap body + two lids, print finish, **reserved before board payment** | pending | pending | pending | pending | pending | pending |
| Small parts by seller including fitted cell/charge cable | pending | pending | pending | pending | pending | pending |
| First load by seller or documented factory inclusion | pending | pending | pending | pending | pending | pending |
| **Sum of route-specific delivered amounts** | — | — | — | — | — | **pending** |

Before *any* payment: confirm the board release/ESD and fixed-TS off-ear charging arrangement, recheck exact codes and live inventory, obtain assembly acceptance for flex, 0201, both sides, consignment and X-ray, prove the physical snap fit, cell insulation/PCM/polarity, charge cable and standoff height, and document actual route-specific shipping, import and tax. The historical planning range is not approval to purchase. If a complete shell delivered reserve cannot be supported, or any safety/fit/supplier check remains open, G8 fails. Superseded v2 checkout sheets have been removed; they cannot close this gate for v4.

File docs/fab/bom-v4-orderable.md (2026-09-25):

# V4 BOM — supply snapshot, 2026-09-25 UTC

**All 63 fitted BOM positions now have a supply route: 60 use stocked JLC codes, and U1, U3 and J2 need customer-supplied consignment.** This is not a purchase approval. Public stock can change; prices below are USD per component at JLC's first price tier, not assembled-board prices. No cart, quote, upload, purchase or vendor contact was made. Each JLC row below comes from the public [JLC component search](https://jlcpcb.com/parts) POST endpoint `shoppingCart/smtGood/selectSmtComponentList` with `keyword` equal to the listed code, `currentPage=1`, `pageSize=25`, `searchSource=search`, read **2026-09-25 UTC**. Follow the linked code to the public part listing. Stock is units available at that time, not reserved units; check again before production. All are Extended except C15525 (Basic).

| Reference(s) | JLC code / query | MPN (search result) | Stock | USD each | Supply |
|---|---|---|---:|---:|---|
| U1 | — | ISP1807-LR-RS | 0 (JLC C5264268) | — | CONSIGNED: no JLC stock; [Mouser product](https://www.mouser.com/ProductDetail/Insight-SiP/ISP1807-LR-RS); external live stock/price unverified |
| U2 | [C89288](https://jlcpcb.com/partdetail/C89288) | ADS1292IRSMT | 97 | 6.4422 | JLC |
| U3 | — | BQ25100YFPR | 0 (JLC C527572) | — | CONSIGNED: exact 4.20 V charger; [TI Store product](https://www.ti.com/product/BQ25100/part-details/BQ25100YFPR) public JSON-LD says `InStock`, $0.744, but no public count; obtain enough for assembly before ordering |
| U4 | [C2863576](https://jlcpcb.com/partdetail/C2863576) | TLV71330PDQNR | 990 | 0.0959 | JLC |
| U5 | [C2867950](https://jlcpcb.com/partdetail/C2867950) | TPS7A0230PDQNR | 385 | 0.8201 | JLC |
| Q1 | [C240195](https://jlcpcb.com/partdetail/C240195) | WPM3027-3/TR | 9,846 | 0.0400 | JLC |
| Q2, Q3, Q4 | [C478155](https://jlcpcb.com/partdetail/C478155) | PMZ290UNE2YL | 2,712 | 0.0553 | JLC |
| D1 | [C3001948](https://jlcpcb.com/partdetail/C3001948) | PESD5V0L1UL | 7,525 | 0.0281 | JLC |
| D2 | [C364549](https://jlcpcb.com/partdetail/C364549) | LTST-C281TGKT-5A | 7,490 | 0.0761 | JLC |
| J2 | — | Molex 202656-0021 | no JLC result | — | CONSIGNED: no JLC listing; source exact [Molex product](https://www.molex.com/en-us/products/part-detail/2026560021), stock/price at distributor unverified; mating battery plug still needed |
| J3 | [C49257](https://jlcpcb.com/partdetail/C49257) | 2.54-1*3PPin | 225,530 | 0.0275 | JLC |
| SW1 | [C398746](https://jlcpcb.com/partdetail/C398746) | 1TS015A-1200-0600-CT | 233 | 0.0835 | JLC |
| R1–R3, R31–R33 | [C881401](https://jlcpcb.com/partdetail/C881401) | CR0402F220KQ10Z | 9,884 | 0.0012 | JLC |
| R4, R17, R20, R21 | [C473482](https://jlcpcb.com/partdetail/C473482) | 0201WMF1004TEE | 357,802 | 0.0015 | JLC |
| R5–R8, R13, R25, R27, R28, R34, R35 | [C473048](https://jlcpcb.com/partdetail/C473048) | 0201WMF1002TEE | 10,079,955 | 0.0014 | JLC |
| R11 | [C423451](https://jlcpcb.com/partdetail/C423451) | 0201WMF6801TEE | 3,602 | 0.0016 | JLC |
| R12 | [C270341](https://jlcpcb.com/partdetail/C270341) | 0201WMF6041TEE | 149,721 | 0.0014 | JLC |
| R14–R16, R23, R24 | [C270364](https://jlcpcb.com/partdetail/C270364) | 0201WMF1003TEE | 518,206 | 0.0015 | JLC |
| R18 | [C270345](https://jlcpcb.com/partdetail/C270345) | 0201WMF4702TEE | 163,838 | 0.0015 | JLC |
| R19 | [C270351](https://jlcpcb.com/partdetail/C270351) | 0201WMF2702TEE | 63,170 | 0.0013 | JLC |
| R22 | [C270365](https://jlcpcb.com/partdetail/C270365) | 0201WMF1001TEE | 1,858,760 | 0.0013 | JLC |
| C1 | [C285104](https://jlcpcb.com/partdetail/C285104) | 0201B152K500NT | 26,563 | 0.0014 | JLC |
| C2 | [C5142551](https://jlcpcb.com/partdetail/C5142551) | TCC0201X7R103K500ZT | 2,003,754 | 0.0012 | JLC |
| C3, C14, C18, C19 | [C36626211](https://jlcpcb.com/partdetail/C36626211) | GRM155R61A106ME18D | 137 | 0.4216 | JLC |
| C4, C5, C10, C11, C13, C16 | [C5142566](https://jlcpcb.com/partdetail/C5142566) | TCC0201X5R105K6R3ZT | 347,988 | 0.0052 | JLC |
| C6, C8, C9 | [C15525](https://jlcpcb.com/partdetail/C15525) | CL05A106MQ5NUNC | 8,666,050 | 0.0255 | JLC Basic |
| C7, C12, C15, C17 | [C307380](https://jlcpcb.com/partdetail/C307380) | CL03A104KO3NNNC | 995,573 | 0.0061 | JLC |

## Substitution checks

- **R11, R18, R19:** the three selected 0201 parts are 1% thick-film, 25 V / 50 mW, the same resistance and footprint as their original design values. Search queries `0201 6.8k`, `0201 47k`, `0201 27k` respectively. R18 is on the 5.5 V VBUS divider; 25 V suffices. No resistor network change.
- **C2:** query `0201 10nF 50V`: the selected part is 10 nF, ±10%, 50 V, X7R, 0201, matching the original 0201B103K500NT. The original C43380 had only 10 units in stock and a 20-piece minimum placement plus 10 loss units.
- **D1:** query `PESD5V0L1UL` returned the **same** PESD5V0L1UL in SOD-882, C3001948. Original vs selected: standoff **5 V / 5 V**, clamping **12 V / 12 V** (JLC listing), capacitance **25 pF / 25 pF**; same part/pad orientation, not a family substitution. The old C24109 was an unrelated codec.
- **U4:** query `TLV71330` returned C2863576, TLV71330PDQNR. PDQNR vs PDQNT is reel/tape ordering; both 3.0 V, 150 mA, 230 mV dropout at 150 mA, 5.5 V input and 50 µA quiescent per JLC; same X2SON-4-EP 1×1 land and pinout. U5's exact TPS7A0230PDQNR also surfaced under query `TPS7A0230PDQNR`.
- **U3:** [TI SLUSBV8C comparison table](https://www.ti.com/lit/ds/symlink/bq25100.pdf) §5: YFPR is **4.20 V**, A is **4.30 V**. With the 4.2 V cell, A is **not** a drop-in even though JLC has 85 of C2871910 at $2.2752. The B variant is not defined in that datasheet; JLC lists 4.284 V and only **6** of C2871905, below the 10-unit floor, so B is not qualified either. Charging off-ear with fixed TS does not change cell-voltage compatibility. Keep YFPR consigned. Its 30 V IN rating and the §2.1 effective IN/TS/OUT capacitor checks remain those of the exact part; these are not proof of a contact-level ESD test.
- **D2:** query `0402 525nm`: Lite-On green LTST-C281TGKT-5A is **0402**, not the old C72043 0603. At 5.0–5.5 V VBUS, 2.5–3.1 V forward range and 1 kΩ R22, current is **(VBUS − Vf)/1000 = 1.9–3.0 mA**; below its listed 20 mA rating. Pad 1 is cathode, pad 2 anode as wired. No 0402 land alteration.
- **C3/C14/C18/C19:** query `GRM155R61A106ME18` found GRM155R61A106ME18**D**. [Murata's exact base-part specification](https://search.murata.co.jp/Ceramy/image/img/A01X/G101/ENG/GRM155R61A106ME18-01A.pdf) identifies **D** as 180 mm reel paper tape, not an electrical change. The [Murata SimSurfing DC-bias graph](https://ds.murata.com/simserve/characteristics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) for this 0402 10 V X5R part yields (after ×0.8 tolerance and ×0.85 temperature allowance) **1.55 µF IN at 5 V, 1.38 µF TS at 5.5 V, 3.78 µF combined OUT at 4.2 V**; all exceed TI's 1/1/2 µF conditions. See `board-v4-design.md` §2.1 for graph values and layout caveats. Four parts × five boards = 20; JLC's 137 units exceed its 5-piece minimum + 2 loss units.

**Component cost estimate:** the 60 stocked JLC positions total **$9.6422 per board** at the displayed first price tier (**$48.211 for five**), excluding JLC setup/assembly and the three consigned lines. The exact U3 TI public offer is $0.744 per chip, and an earlier Mouser U1-RS observation was $13.65 each (2026-09-23); neither is a confirmed five-board consignment quote. J2 and assembly fees are still unknown. The updated `orders-v2.md` and `cost-cuts.md` worksheets use this three-consignment BOM and stocked JLC basket; their delivered-cost ranges are planning allowances, not order prices.

The assembly site's acceptance of consigned U1/U3/J2, their fees and availability of the correctly terminated battery remain **unverified**. A passing routed release verifies board files, not vendor acceptance or physical ESD performance.

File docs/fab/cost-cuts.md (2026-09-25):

# First earpiece: cost cuts without changing the 18 mm body

The **conditional lean estimate is $1,212.78 likely, against the 2026-09-25 $1,318.68 baseline**; the largest modeled cuts are the first-load kit ($71.90 **only if** the assembler supplies a verified image at no extra charge), the nickel screen ($25 **only with Rolf's written waiver**), and the spare printed lid/black finish ($9 combined). The much larger standoff, cell and consignment bills **have no verified cheaper drop-in purchase path**; none of those savings is counted. Rolf would need to accept the waiver and the undyed one-lid finish; the factory-image condition is still unproved. A different battery connector would change the board and is **an option, not this estimate**.

Research read **2026-09-25** from public pages only. Quantities below are purchase quantities, not merely installed quantities; USD unless stated. No quote request, upload, account, contact or purchase. The comparison is against [orders-v2.md](orders-v2.md) (2026-09-25 orderable BOM: $744.27 / $1,318.68 / $3,125.92, low/likely/high). Its freight, tariff, brokerage and tax numbers are *allowances*, not offers; the new columns are also planning allowances, not delivered checkout prices or a guaranteed high. The physical envelope, contacts, 220 kΩ electrode paths, off-ear-only charging, protected cell, polarity check, and R2's no solder/crimp/wire-stripping rule stay. Do not order against this document: board acceptance, printed fit and electrical gates remain open.

## Findings that do **not** justify a booked saving

| Item / bought vs needed | Public evidence, read 2026-09-25 | Finding; saving / trade-off |
| --- | --- | --- |
| Three M2.5 female/female **3 mm long, 5 mm across-flats**, nickel-plated brass spacers; 100 bought | [Spacer Express LAI-FF-M2.5-SW5-L3-100](https://spacer-express.com/female-female/875-hexagonal-female-female-threaded-spacer-nickel-plated-brass-m2-5-5-mm-across-flats.html): pack 100, €82.80 ex VAT, delivery 5–10 business days; says full through tapping. [Plan §3/G7](plan-v2.md) requires thread depth, landing/finish and fit qualification. | **No authenticated in-stock US/EU small pack of this exact 3 mm × AF5 × M2.5 part, or dimensionally and mechanically qualified substitute, found.** McMaster's [generic standoffs](https://www.mcmaster.com/standard-threaded-standoffs/) do not prove this exact configuration/face. The [Harwin R25-1000402 drawing](https://content.harwin.com/asset/6e059b82-0a88-4a5e-8a59-36c0928fbfd1/DRG-01991-Technical-Drawing-Datasheet-R25-100-pdf.pdf) is **4 mm long**: it does *not* fit the 3 mm stack unchanged. A 3–10 piece purchase could in principle eliminate much of the $115 goods allowance plus the $40 EU parcel, but no supported price/availability or G7 fit means **$0 counted**. Don't substitute a 4 mm spacer or shorten one. |
| One ~40 mAh **501012-class** fitted cell; one custom factory-built two-wire protected pack bought | [Board-v4 §1.2, §4.1 and §2.1](board-v4-design.md) give the 5.1 mm cell stack, pocket u 1.8–11.9 × s 1.5–14.9 and 0.5 mm foam; [Molex 202656-0021 drawing](https://www.molex.com/content/dam/molex/molex-dot-com/products/automated/en-us/salesdrawingpdf/202/202656/2026560021_sd.pdf) identifies the **board** receptacle. [Adafruit 100 mAh protected JST-PH pack](https://www.adafruit.com/product/1570) has 3.8 × 11.5 × 31 mm cell, far too long, and JST-PH. [PKCELL custom packs](https://www.pkcell.com/product-category/custom-battery-pack/) show no delivered single-unit fitted 501012 offer. | No public off-the-shelf **30–40 mAh protected** cell with factory-fitted plug was authenticated as meeting *all* pocket, PCM, charge-limit and plug/polarity conditions. A bare 401012/501012 cell is not a protected plug-in replacement; no shell-size change is allowed. JST-PH (the concrete off-the-shelf connector reference above) **does not mate** with Pico-EZmate Slim J2. A factory-built cell with Pico-EZmate Slim mating plug and verified polarity stays in the $35/$90/$250 allowance. An off-the-shelf JST-PH cell *if* one eventually fits would require a **new J2 board design and fit/safety review**, not a first-build cut. **$0 counted.** |
| Consigned U1 six, U3 ten, J2 ten; one direct-export parcel | [2026-09-25 orderable BOM](bom-v4-orderable.md), [JLC consigned terms](https://jlcpcb.com/help/article/consigned-parts-service-introduction), [TI exact U3 offer](https://www.ti.com/product/BQ25100/part-details/BQ25100YFPR). U5 and the four GRM caps are JLC stock; U3 exact YFPR is not. | 2026-09-25 [orders-v2 §1a](orders-v2.md) recalculates purchased U1/U3/J2 as $81.90+$7.44+$7.50 low plus $20 parcel = **$116.84/$179/$354** direct-export planning totals; board handling for 3 types is **$9/$22.50/$56.25**, not an accepted fee. TI advertises U3 $0.744 each but count/landed cost is unverified; U1/J2 prices and single-seller forwarding remain unverified. No consignment saving beyond the revised baseline is counted; JLC basket already buys U5 and GRM. Duty includes declared consigned value once. **$0 lean saving.** |

### Current orderable codes — no speculative extra savings

The [2026-09-25 orderable BOM](bom-v4-orderable.md) supplies stocked R11 C423451, R18 C270345, R19 C270351, D1 C3001948 (exact PESD5V0L1UL), D2 C364549 (qualified 0402 LED), U4 C2863576 (TLV71330PDQNR), U5 C2867950 and GRM capacitors C36626211. U3 BQ25100YFPR remains consigned because JLC C527572 has zero stock; the A/B charger variants are not qualified for this 4.2 V cell. The 60 JLC placements cost **5 × $9.6422 = $48.211** for five boards at first-tier prices, with the unverified minimum/attrition reserve shown in orders-v2. Recheck stock and assembly acceptance before payment; no further BOM substitution or basket saving is counted.

## What the public board schedule actually buys

[JLC standard PCBA schedule](https://jlcpcb.com/help/article/pcb-assembly-price) and [FPC extra charges](https://jlcpcb.com/help/article/fpc-extra-charges), read 2026-09-25, apply to this two-sided 2-layer flex with six FR4 stiffeners; [assembly capabilities](https://jlcpcb.com/capabilities/pcb-assembly-capabilities) says flex needs dedicated fixtures *typically*, not that this design is exempt. The schedule lists **two flex fixtures $49.25 at 1–29 pieces**, pre-reflow **$0.016 per joint**, Standard feeder loading **$1.53 per Basic/Extended type**, and X-ray **$1.64 per inspected item for 1–10**. JLC's X-ray text says inspection is *required* for invisible joints such as BGA/QFN; U3 is a DSBGA and U1 is leadless. Therefore do **not** simply delete the fixture $49.25, pre-reflow $27.28 (1,705 pad-based estimated joints), feeder $41.31 (2026-09-25: 1 Basic + 23 Extended + 3 consigned types × $1.53, consigned applicability open), or X-ray $8.20 (U1-only *underestimate*: U3 and other leadless parts may add cost). Exact fixture use, which joint counts are charged, inspection scope, stiffener surcharge and whether J3 is manually placed need the order review; $0 savings counted here. The FPC page explicitly charges an extra stiffener fee for ≥4 per board; six remain. A public fixed fab quote for this released geometry cannot be obtained without uploading files, which this task forbids.

**Two versus five:** even supposing a two-piece Standard assembly is accepted, shared setup/stencil/fixtures/forward shipping remain. Linear illustrations from the [schedule](https://jlcpcb.com/help/article/pcb-assembly-price) at 341 SMT pads/board: pre-reflow **2×341×.016=$10.91 vs 5×341×.016=$27.28** (difference $16.37); placement **2×341×.0016=$1.09 vs $2.73** (difference $1.64); X-ray *U1 only* **2×$1.64=$3.28 vs 5×$1.64=$8.20** (difference $4.92). Direct JLC unit-tier part basket savings (five-board $48.211 baseline, 2026-09-25) and fabrication, handling, attrition and shipping differences are unknown. The sum **$22.93** of those *three* illustrative variable differences is not an order saving: lower quantities can change fees, minimums and manufacturing yield, and the five-board flex assembly minimum asserted in [orders-v2](orders-v2.md) was not independently proved by an accepted public checkout for this board. Don't book a two-board price; five remains the cost basis. Two boards mean fewer spares if a unit fails.

## Shipment map, and what the first build actually needs

At most the following consolidation should be pursued, not presumed: **(1)** PCB and JLC-library parts leave JLC together; direct-export U1/U3/J2 parts go **to JLC**, not Massachusetts, if one supplier can supply all three (unverified). **(2)** JLC3DP body + one lid: ask whether they can ride with (1); separate JLC3DP and JLCPCB checkouts do not prove one customs entry or one freight charge. **(3)** Protected fitted cell: potentially regulated *separate* shipment, not folded into an ordinary parts package without carrier acceptance. **(4)** Titanium screws, key, insulated charge cable, foam, meter if needed, bench leads/gel and debug accessories may consolidate at one US seller **only where that seller actually stocks the exact qualified articles**. **(5)** Spacer Express currently requires its own EU→MA parcel. Baseline likely parcel allowances (unchanged 2026-09-25) are $35 board, $40 parts→JLC, $22 shell, $25 cell, $40 EU standoff, $40 other US parts and $20 two-seller debug kit: **$222** across those lines; carrier/duty/tax allowances are additional. Combining all into one shipment is not supported. No freight/brokerage discount is booked on hope. [JLC shipping page](https://jlcpcb.com/help/article/shipping-methods) gives no Massachusetts rate; read 2026-09-25.

**Needed for a safe one-earpiece build:** accepted five-board assembly (or a genuinely priced alternative), one fitted protected cell, insulated charging interface, three qualified skin-contact screws and standoffs, foam, one printed body and **one** lid, off-body meter/polarity and continuity checks (buy meter if Rolf lacks one), first firmware load *somewhere*, and tests/bench leads and gel for S2 if validation proceeds. Do not remove the electrode bench kit merely because it is not worn at S4. A nickel screen is either performed or explicitly waived by Rolf in writing per [plan-v2 §10](plan-v2.md); omission without the waiver is not a cut. Extra lid and black finish are the only no-function print options here (undyed finish still needs skin-contact evidence/acceptance). Existing $25 likely charge-cable allowance has no qualified exact SKU; it cannot be zeroed.

**First-load probe:** the least expensive specifically priced candidate in the worksheet is the [Adafruit Raspberry Pi Debug Probe #5699](https://www.adafruit.com/product/5699), **one at $12**, advertised in stock, CMSIS-DAP SWD **nominal 3.3 V I/O**. Mate it through one [Tag-Connect TC2030-IDC-NL](https://www.tag-connect.com/product/tc2030-idc-nl), **$33.95**, plus jumper wiring, *only after* [board-v4 §7](board-v4-design.md) / plan G4 checks J4 pad map, target's 3.0 V U5 rail under load, both directions' absolute I/O limits, ground-first sequence and the factory image. Nominal 3.3 V is **not** proof it is safe at 3.0 V; no lower-priced bare Pico/pogo-pins substitution is qualified or compatible with R2. If G4 fails, retain the full kit allowance and stop; do not wire a 3.3 V supply into J4 target VDD. Factory programming saves the kit only if the assembler actually supplies, flashes and verifies the **correct** bootloader/image as part of a priced service (no public acceptance shown).
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

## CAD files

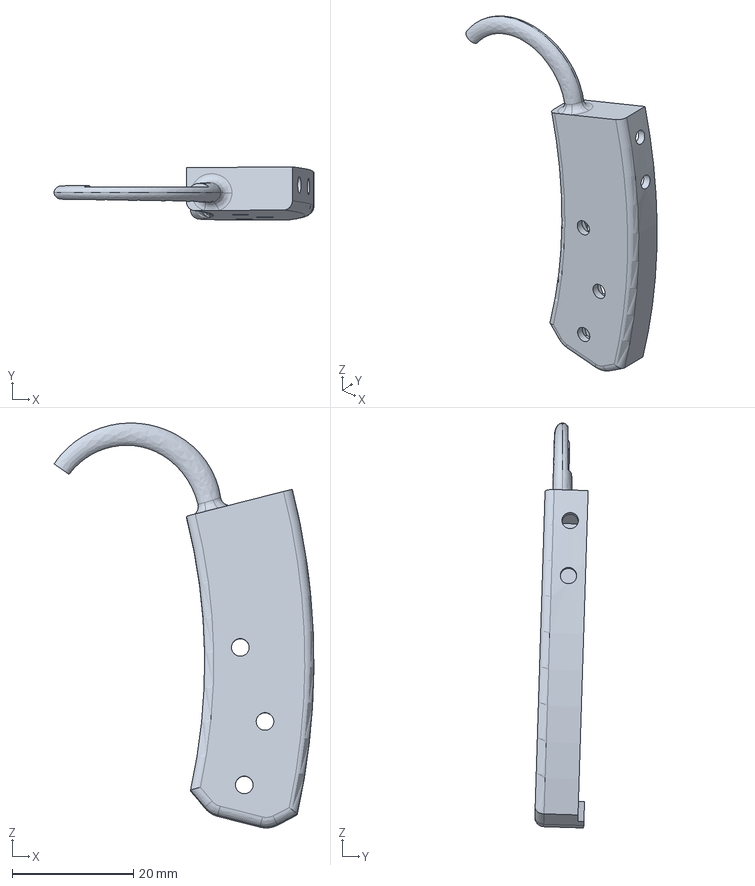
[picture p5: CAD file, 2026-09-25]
docs/fab/cad/v4/body_full_p15.step
42.8 x 8.79 x 66.7 mm

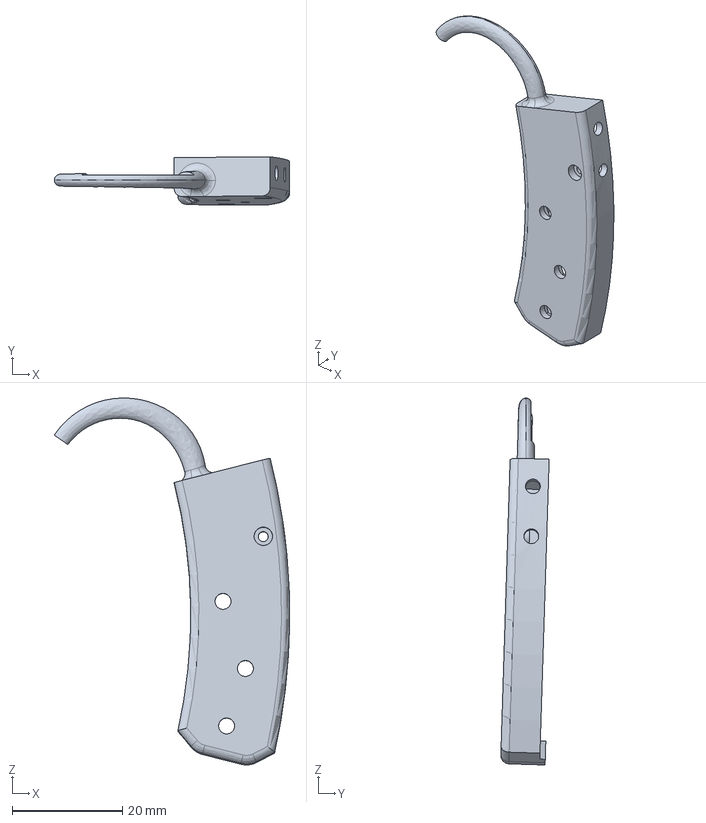
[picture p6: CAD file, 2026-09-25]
docs/fab/cad/v4-m16/body_full_p15.step
42.8 x 8.79 x 66.7 mm

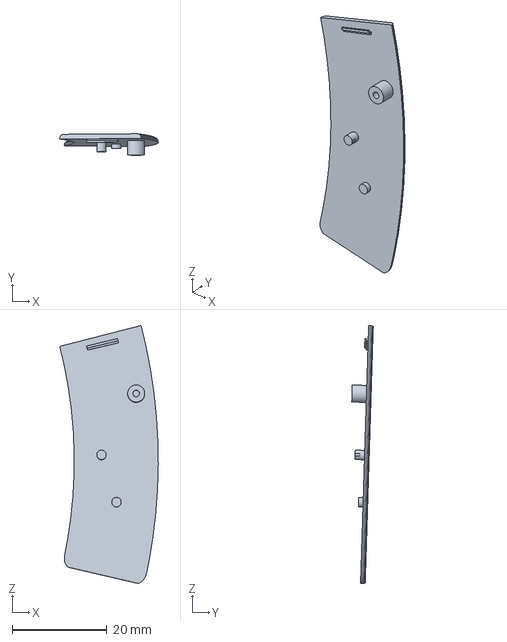
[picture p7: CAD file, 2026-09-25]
docs/fab/cad/v4-m16/lid.step
20.8 x 4.55 x 54.3 mm

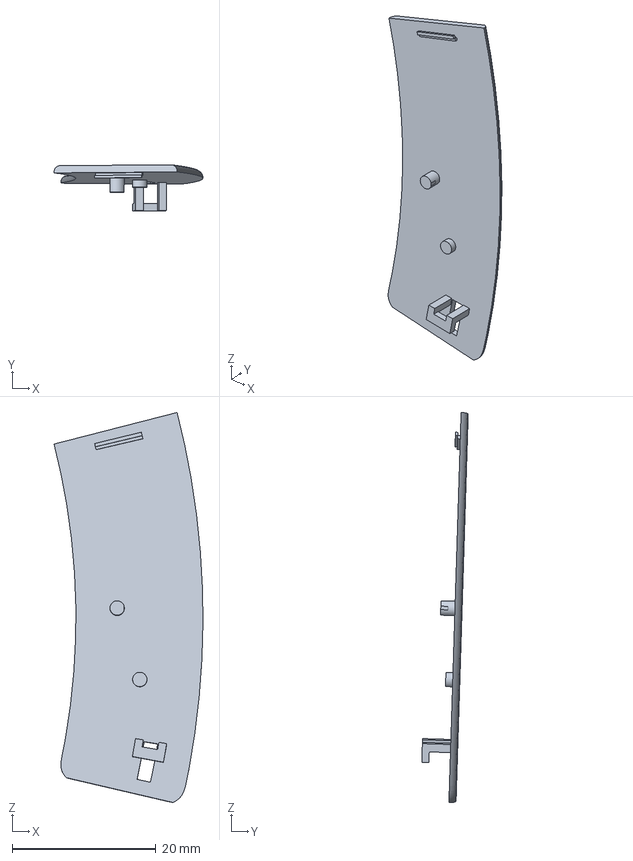
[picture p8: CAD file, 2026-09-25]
docs/fab/cad/v4-snap/lid.step
20.8 x 6.47 x 54.3 mm

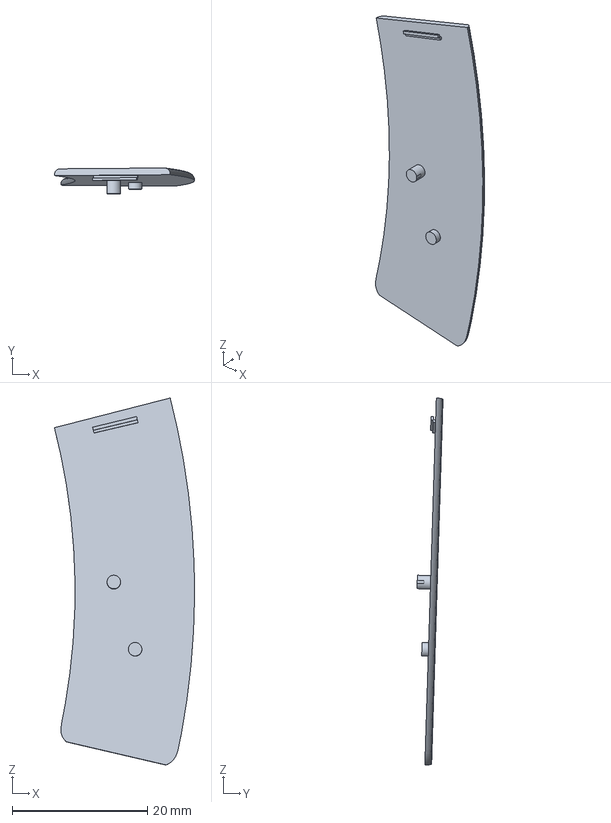
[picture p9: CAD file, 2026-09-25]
docs/fab/cad/v4/lid.step
20.8 x 3.86 x 54.3 mm

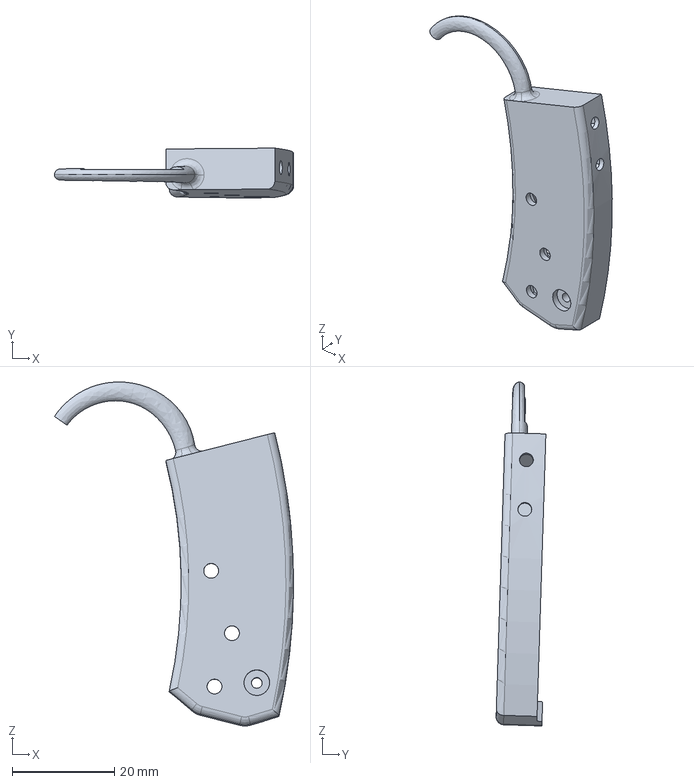
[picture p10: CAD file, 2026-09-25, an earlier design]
docs/fab/cad/v2/body_full_p15.step
46.8 x 9.74 x 67.3 mm

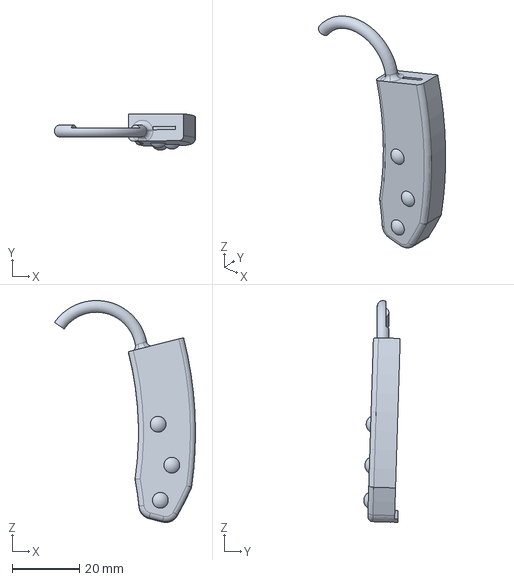
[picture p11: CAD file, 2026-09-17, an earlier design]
docs/fab/cad/v1/body_full_p15.step
42.0 x 10.9 x 66.1 mm

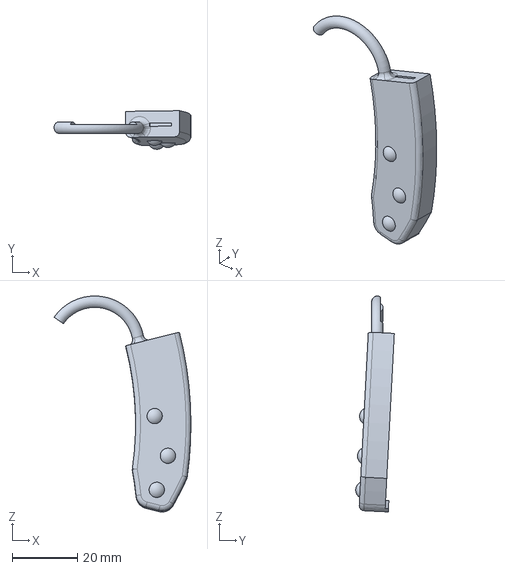
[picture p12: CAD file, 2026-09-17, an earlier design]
docs/fab/cad/v1/body_full_p25.step
42.0 x 11.9 x 66.3 mm

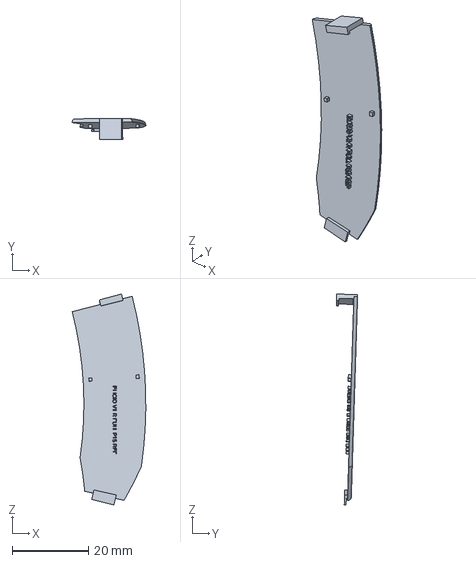
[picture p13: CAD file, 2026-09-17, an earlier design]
docs/fab/cad/v1/lid.step
19.3 x 5.60 x 55.2 mm

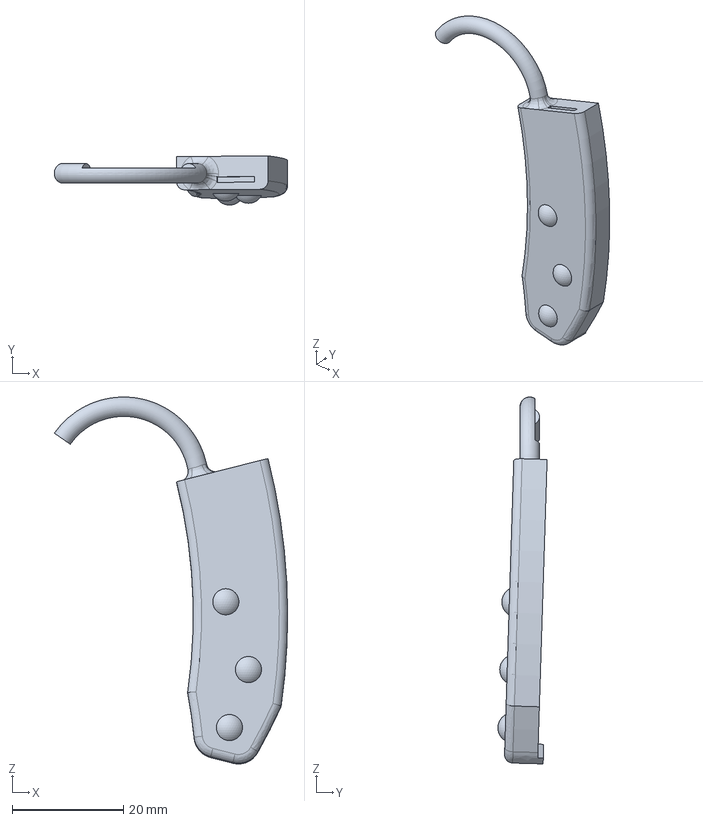
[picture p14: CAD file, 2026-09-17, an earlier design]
docs/fab/cad/v1/body_thin_p15.step
42.0 x 8.86 x 66.1 mm

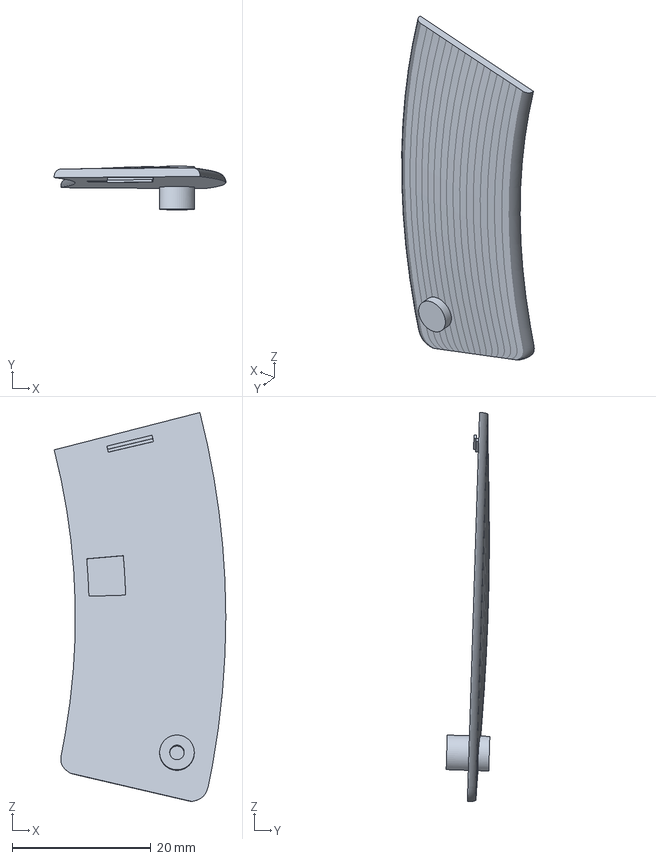
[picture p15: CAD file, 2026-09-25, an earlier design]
docs/fab/cad/v2/lid.step
24.8 x 6.30 x 56.1 mm

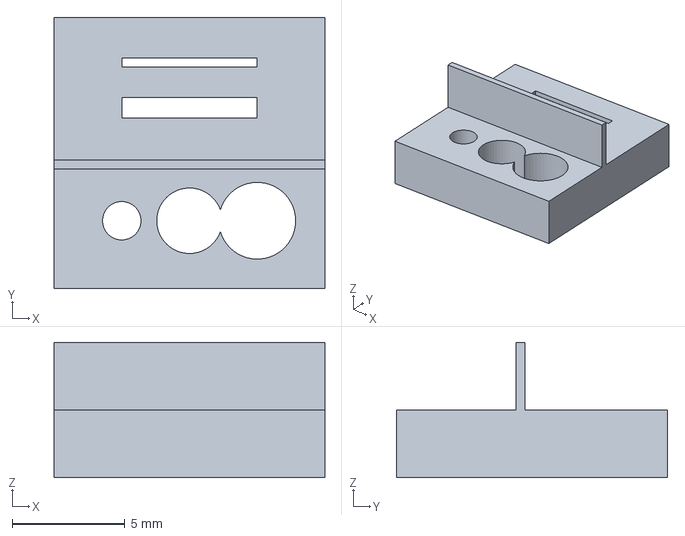
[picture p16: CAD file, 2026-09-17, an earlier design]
docs/fab/cad/v1/coupon.step
12.0 x 12.0 x 6.00 mm

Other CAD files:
docs/fab/cad/v4-snap/body_full_p15.step
docs/fab/cad/v1/body_full_p15.3mf
docs/fab/cad/v1/body_full_p15.stl
docs/fab/cad/v1/body_full_p25.3mf
docs/fab/cad/v1/body_full_p25.stl
docs/fab/cad/v1/body_thin_p15.3mf
docs/fab/cad/v1/body_thin_p15.stl
docs/fab/cad/v1/coupon.3mf
docs/fab/cad/v1/coupon.stl
docs/fab/cad/v1/lid.3mf
docs/fab/cad/v1/lid.stl
docs/fab/cad/v2/body_full_p15.3mf
docs/fab/cad/v2/body_full_p15.stl
docs/fab/cad/v2/lid.3mf
docs/fab/cad/v2/lid.stl
docs/fab/cad/v4-m16/body_full_p15.3mf
docs/fab/cad/v4-m16/body_full_p15.stl
docs/fab/cad/v4-m16/lid.3mf
docs/fab/cad/v4-m16/lid.stl
docs/fab/cad/v4-snap/body_full_p15.3mf
docs/fab/cad/v4-snap/body_full_p15.stl
docs/fab/cad/v4-snap/lid.3mf
docs/fab/cad/v4-snap/lid.stl
docs/fab/cad/v4/body_full_p15.3mf
docs/fab/cad/v4/body_full_p15.stl
docs/fab/cad/v4/lid.3mf
docs/fab/cad/v4/lid.stl

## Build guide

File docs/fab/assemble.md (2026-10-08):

# Assembly readiness

The v4 board is unfinished and unordered. No assembled device exists. The former v2 step-by-step assembly and Feather flash instructions are superseded and have been removed.

The current candidate combines the v4 flex board, a fitted protected cell, titanium contact hardware and the v4-snap shell. It is not a qualified kit. Do not substitute parts or assume final assembly needs only the modeled steps.

## Before a real assembly

- Resolve the electrical, fabrication and supply gates in [open questions](open-questions.md).
- Implement and verify the ISP1807 product Arduino variant and first-load voltage levels. The Feather variant is not the product pinout.
- Inspect a passive shell print. Verify repeated closure, key access, contact installation and lid-post loads.
- Review the actual cell pack, polarity, connector, insulation, charging limits and off-ear-only arrangement.
- Re-run the board release checks after any design change. A historical DRC count is not safety approval.

No on-body assembly, charge procedure or wear result is validated here. Rolf's requirement for limited final assembly remains a design constraint, not a measured completion-time claim.

Use [board v4](board-v4-design.md), [shell v4](shell-v4.md) and [firmware status](firmware-v2.md) as the current references. Keep future purchase and assembly records in ignored local directories. Do not publish payment or delivery information.

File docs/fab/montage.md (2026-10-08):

# Proposed acquisition criteria and receiver mapping

These are unvalidated engineering targets, not measured results or an approved on-body protocol. The board is unfinished and unordered. No gel, dry-contact or live acquisition record is included. The shelved breadboard circuit, shopping path and gauge-first procedure have been removed.

All amplitude and detection targets below are proposals. Earlier agent reports do not provide a verified biological basis for them. Qualified electrical review and bench validation must precede any on-body study. No duration of powered wear is authorized by this document.

## Reference coordinates

The generator uses `u` across the body and `s` along its curved path from the hook root, in millimetres. Its reference contact centres are:

| Contact | u | s |
| --- | ---: | ---: |
| CONTACT_1 | 5.9 | 22.0 |
| CONTACT_2 | 10.4 | 33.1 |
| CONTACT_REF | 8.5 | 43.0 |

These are design defaults, not Rolf's anatomy measurements or a validated montage. Physical contact positions, material, pressure and cross-talk need separate review. A geometry check cannot establish independent auricular and jaw-muscle sources.

## Evidence needed

A future reviewed study needs raw signal, acquisition time, calibration, contact configuration, cue annotations and distinct session identifiers. Keep recordings and participant metadata in ignored `recordings/`. Keep completed anatomy parameters in ignored `measurements/`. Do not publish identifiable photos or personal self-reports as design evidence.

Preserve raw records without replacing them with filtered traces. Any change to a target needs a dated rationale before evaluation, not a threshold selected after seeing the test result. Transport fixtures test byte handling only.

## Proposed detection targets

| ID | Proposed target |
| --- | --- |
| 3.1 | Resting noise at most 5 microvolts RMS in the 20 to 490 Hz band over 60 seconds. |
| 3.2 | Median of 10 deliberate auricular contractions at least 45 microvolts peak-to-peak and at least 3 times resting peak-to-peak amplitude. |
| 3.3 | Median of 10 jaw clenches at least 150 microvolts peak-to-peak, at least 10 times rest and at least 3 times the contraction median. |
| 3.4 | No acquisition dropout. DC shift at most 50 mV input-referred relative to rest. Input and common-mode headroom remain open. |
| 3.5 | On each of 3 separate sessions after removal and replacement, at least 9 of 10 contractions detected without changing the threshold. |
| 3.6 | At most 1 false contraction event during 5 minutes of eating. |
| 3.7 | No false contraction event during 5 minutes of talking. |
| 3.8 | No false contraction event during 5 minutes of walking. |
| 3.9 | No confirmation pair or action above `RiskLevel.NONE` during 3 yawns. |
| 3.10 | At most 1 `RiskLevel.NONE` trigger per set of 5 wide smiles or 5 hard blinks, and no action above NONE. |

These small counts cannot estimate long-term false-positive rates or safety. Confidence floors and the three-second confirmation window are software policy settings in `src/elicio/harness/policy.py`, not calibrated biological probabilities. The event tuple cannot prove that a confirmation came from an independent muscle group.

## 8. Protocol v2 mapping

This section retains the criterion IDs consumed by the existing receiver checks. Frame-v2 acquisition is intended to run at 2000 samples per second. Raw ADS1292 codes are preserved. The nominal voltage scale in [frame-v2.md](frame-v2.md) is metadata, not measured calibration.

The proposed offline amplitude analysis uses a fourth-order Butterworth band-pass from 20 to 490 Hz with zero-phase `sosfiltfilt`. Rest RMS uses the full 60-second record after exclusions. Contraction and clench peak-to-peak windows start at the cue and last 2 seconds. The receiver does not implement this amplitude analysis or automatic gesture scoring.

Acquisition dropout is a constant-code stretch spanning more than 200 sample intervals (100 ms at 2000 SPS). `receive-check` checks each channel against `acq_index` continuity. Invalid samples and the first 200 conversions after each RESTART are excluded. Missing acquisition conversions and transport loss remain separate records. A missing `frame_seq` is not by itself an acquisition dropout.

HELLO messages and STREAM messages with no samples do not produce waveform samples. VBUS refusal, restart settling and overruns must remain visible in session records. Input headroom and common-mode headroom need bench data. DC shifts must be assessed on raw codes, not a high-passed trace.

| ID | Proposed target | Mapping |
| --- | --- | --- |
| 3.1 | Rest noise at most 5 microvolts RMS | revised: input-referred digital band-pass analysis, not scored by `receive-check`. |
| 3.2 | Contraction at least 45 microvolts peak-to-peak and 3 times rest | revised: same proposed values with a 2-second window, not scored by `receive-check`. |
| 3.3 | Clench at least 150 microvolts peak-to-peak, 10 times rest and 3 times contraction | revised: same proposed values with a 2-second window, not scored by `receive-check`. |
| 3.4 | No dropout and at most 50 mV DC shift | revised: receiver reports constant-code dropout only. DC shift and headroom need separate analysis. |
| 3.5 | Repeated-session detection with unchanged threshold | same criterion: externally scored session field. |
| 3.6 | Eating false-event count | same criterion: externally scored session field. |
| 3.7 | Talking false-event count | same criterion: externally scored session field. |
| 3.8 | Walking false-event count | same criterion: externally scored session field. |
| 3.9 | Yawning confirmation and action count | same criterion: externally scored session field. |
| 3.10 | Smile and blink event/action count | same criterion: externally scored session field. |

`receive` initializes criterion fields 3.5 to 3.10 as `not_scored` in `sidecar.json`. `receive-check` accepts `not_scored` and `pass`. Any other value for one of these IDs causes exit 1. A constant-code dropout alone causes exit 3. Missing or malformed session files cause exit 2. Otherwise it exits 0. An `"ok": true` report with unscored criteria does not mean that gesture or wear targets passed.

The historical `S2 continues (Q75)` message means that a bench dropout is reported rather than classified as a scored gesture failure. It is not approval for powered wear. See [open hardware gates](open-questions.md) and [receiver output](receiver-v2.md).

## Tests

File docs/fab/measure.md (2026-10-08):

# Blank anatomy measurement guide

This guide explains the M1 to M8 reference parameters used by the shell scripts. It contains no completed measurements. It is not a fit result or an ordering instruction. The selected v4 snap shell has not been printed or validated.

Store any completed guide, photos or parameter overlay in ignored `measurements/`. Do not fill this tracked file with Rolf's measurements. The right-ear orientation in the reference template is a drawing convention, not a physiological result.

## Reference template and limits

The [template](template.pdf) and [packing table](packing-v2.md) describe the historical `A_501015_series_w20_y8_iII_s3` reference. They are not the current 18 mm snap-shell outline. If printed, use 100 percent scale and check its 50 mm bar before using dimensions. A template is not a passive printed fit test.

The historical bow-3 geometry uses a chord of approximately 47.90 mm and a placement allowance of 3 mm. Its M1 gate is approximately 50.90 mm. This is a nominal CAD rule, not an anatomical safety threshold. Recalculate the full folded-board and shell fit after changing parameters.

The values in `scripts/cad/params/default.toml` are examples. A blank measurement is unknown, not evidence that a default fits. Do not connect powered electronics to a body while gathering geometry information.

## M1: ear root length

M1 reference landmarks

Straight distance between the upper and lower points where the ear attaches to the skull. This is not the curved crease length. The generator compares M1 with its reference chord and placement allowance.

## M2: crease arc

M2 reference landmarks

Distance along the crease between the same attachment points. The historical shell overlays hold their reference crease bow fixed. M2 does not automatically resize those exports.

## M3: sulcus clearance

M3 reference landmarks

Clearance between the skull in the crease and the helix rim at mid-ear height. It is a span input, not proof of comfort or pressure tolerance.

## M4: helix root thickness

M4 reference landmarks

Thickness of the cartilage bridge at the upper attachment. The reference generator uses it for hook-root positioning. Do not compress tissue to obtain a smaller value.

## M5: glasses temple thickness

M5 reference landmarks

Thickness of a glasses arm where it passes the ear. A reference value of zero means no glasses allowance. In the original generator, a nonzero value enables a glasses flat, not a complete glasses fit model.

## M6: mastoid offset

M6 reference landmarks

Distance from the crease to the bony prominence behind the lower ear. The reference generator records it rather than moving a contact automatically. Contact-site suitability needs separate review.

## M7: crease top to mid-concha

M7 reference landmarks

Distance along the crease from its upper attachment to the level of the ear-canal opening. It is recorded rather than used as an automatic contact-placement rule.

## M8: helix rise

M8 reference landmarks

Vertical distance from the upper attachment to the highest point of the helix. The original generator uses it in hook-radius construction. The v4 overlay still needs a separate fit review.

## Local record

An anatomy overlay passed to `bte_fit_shell.py --params` should identify its orientation, measurement date, method and uncertainty. Keep that record local. Check accepted parameters with `--help` and follow [CAD instructions](../../scripts/cad/README.md).

The scripts reject some parameter changes because feature constants are fixed. A successful export establishes only the checks reported in its manifest. It does not establish skin compatibility, electrical contact, fit or safety.

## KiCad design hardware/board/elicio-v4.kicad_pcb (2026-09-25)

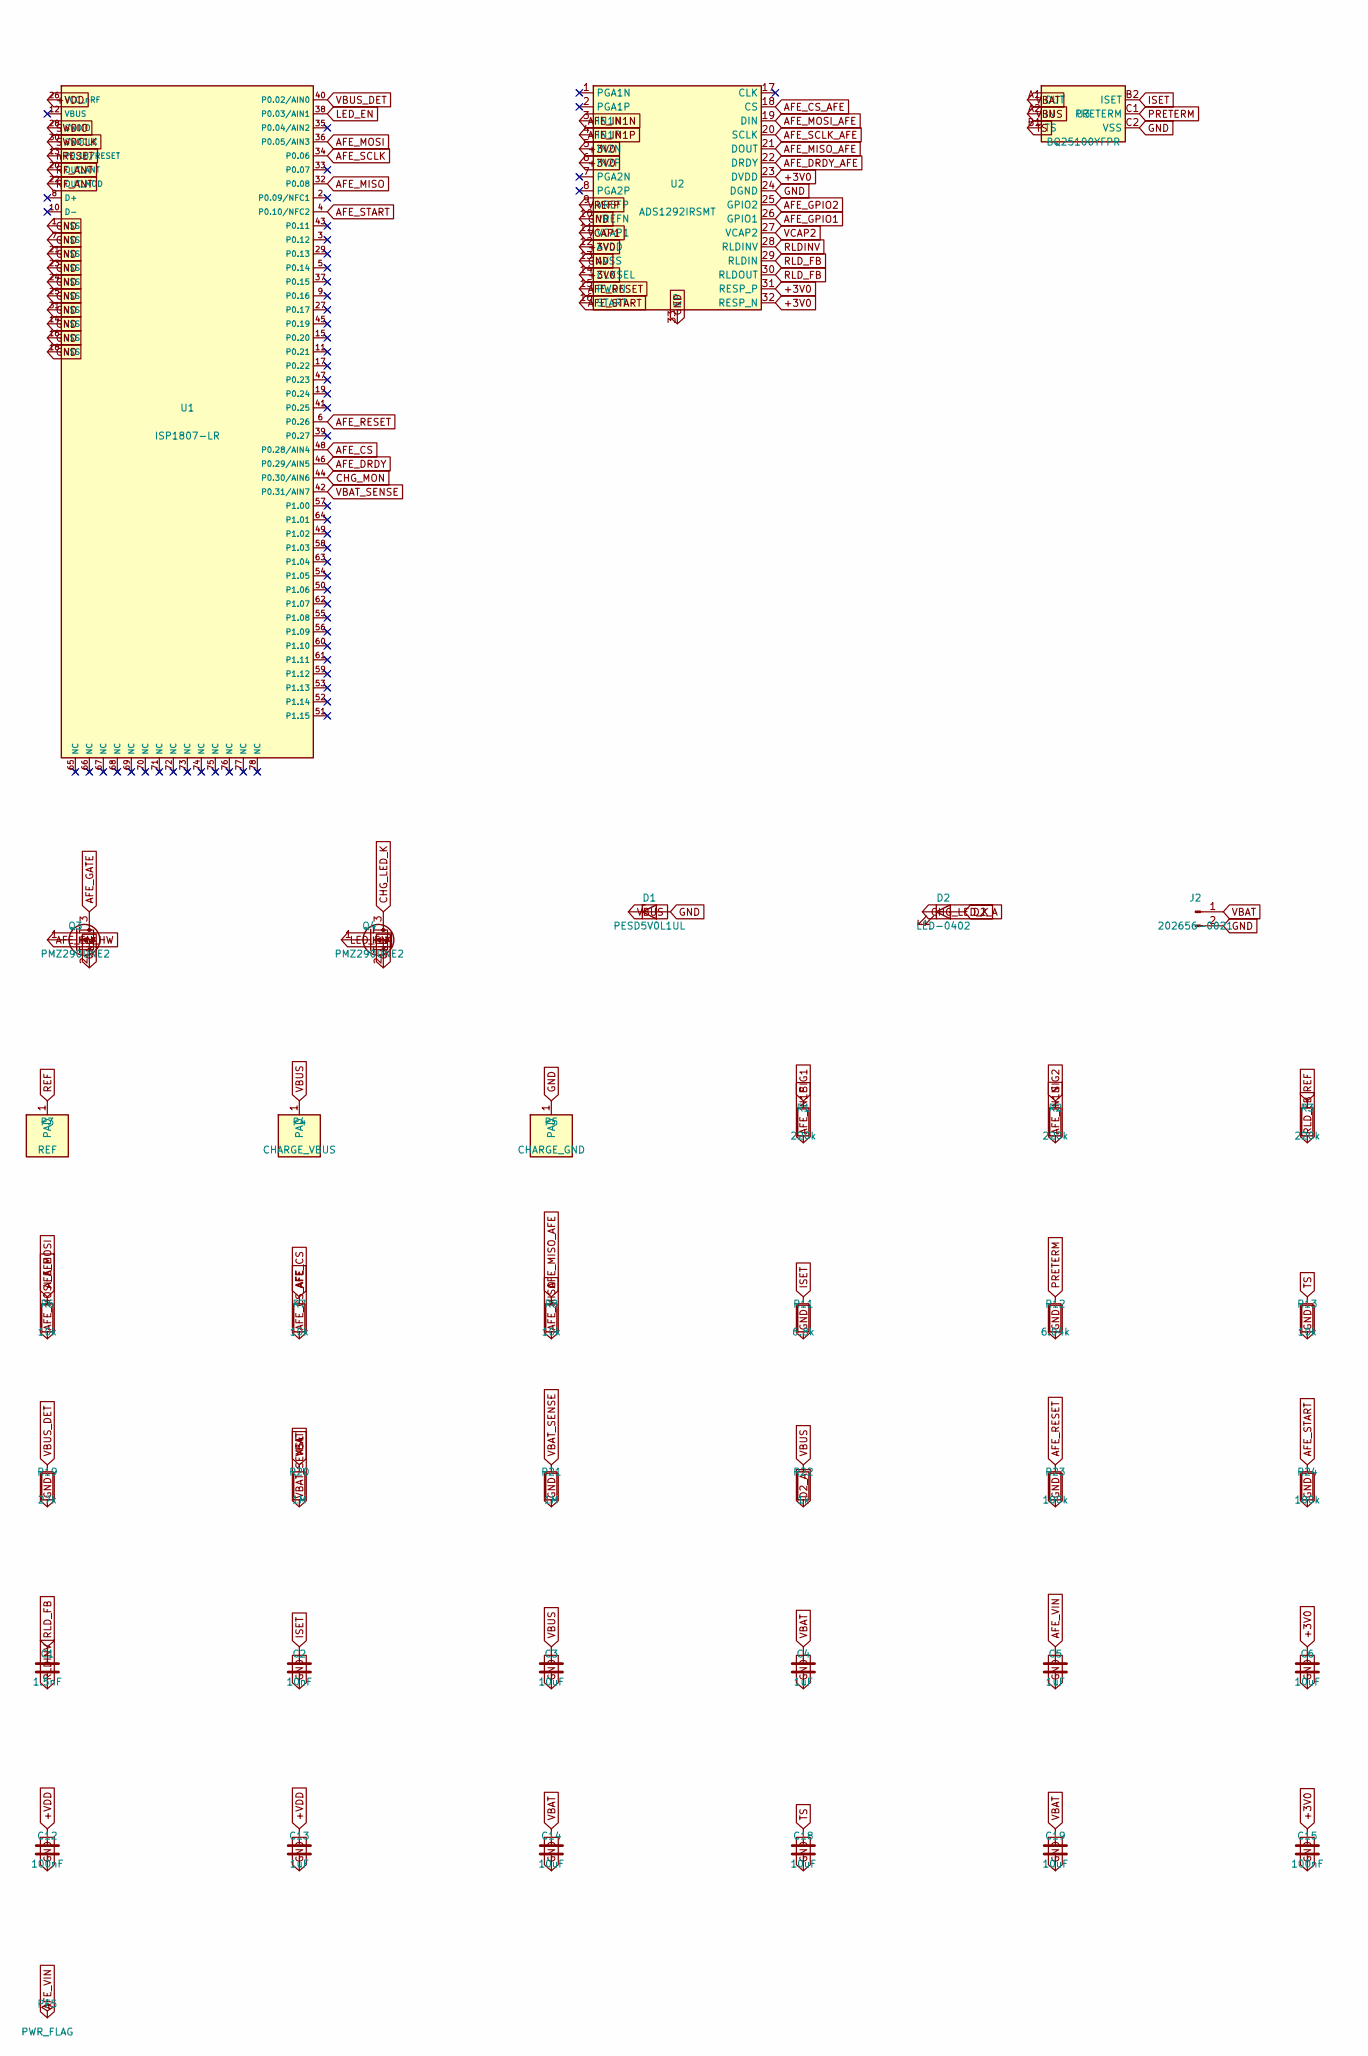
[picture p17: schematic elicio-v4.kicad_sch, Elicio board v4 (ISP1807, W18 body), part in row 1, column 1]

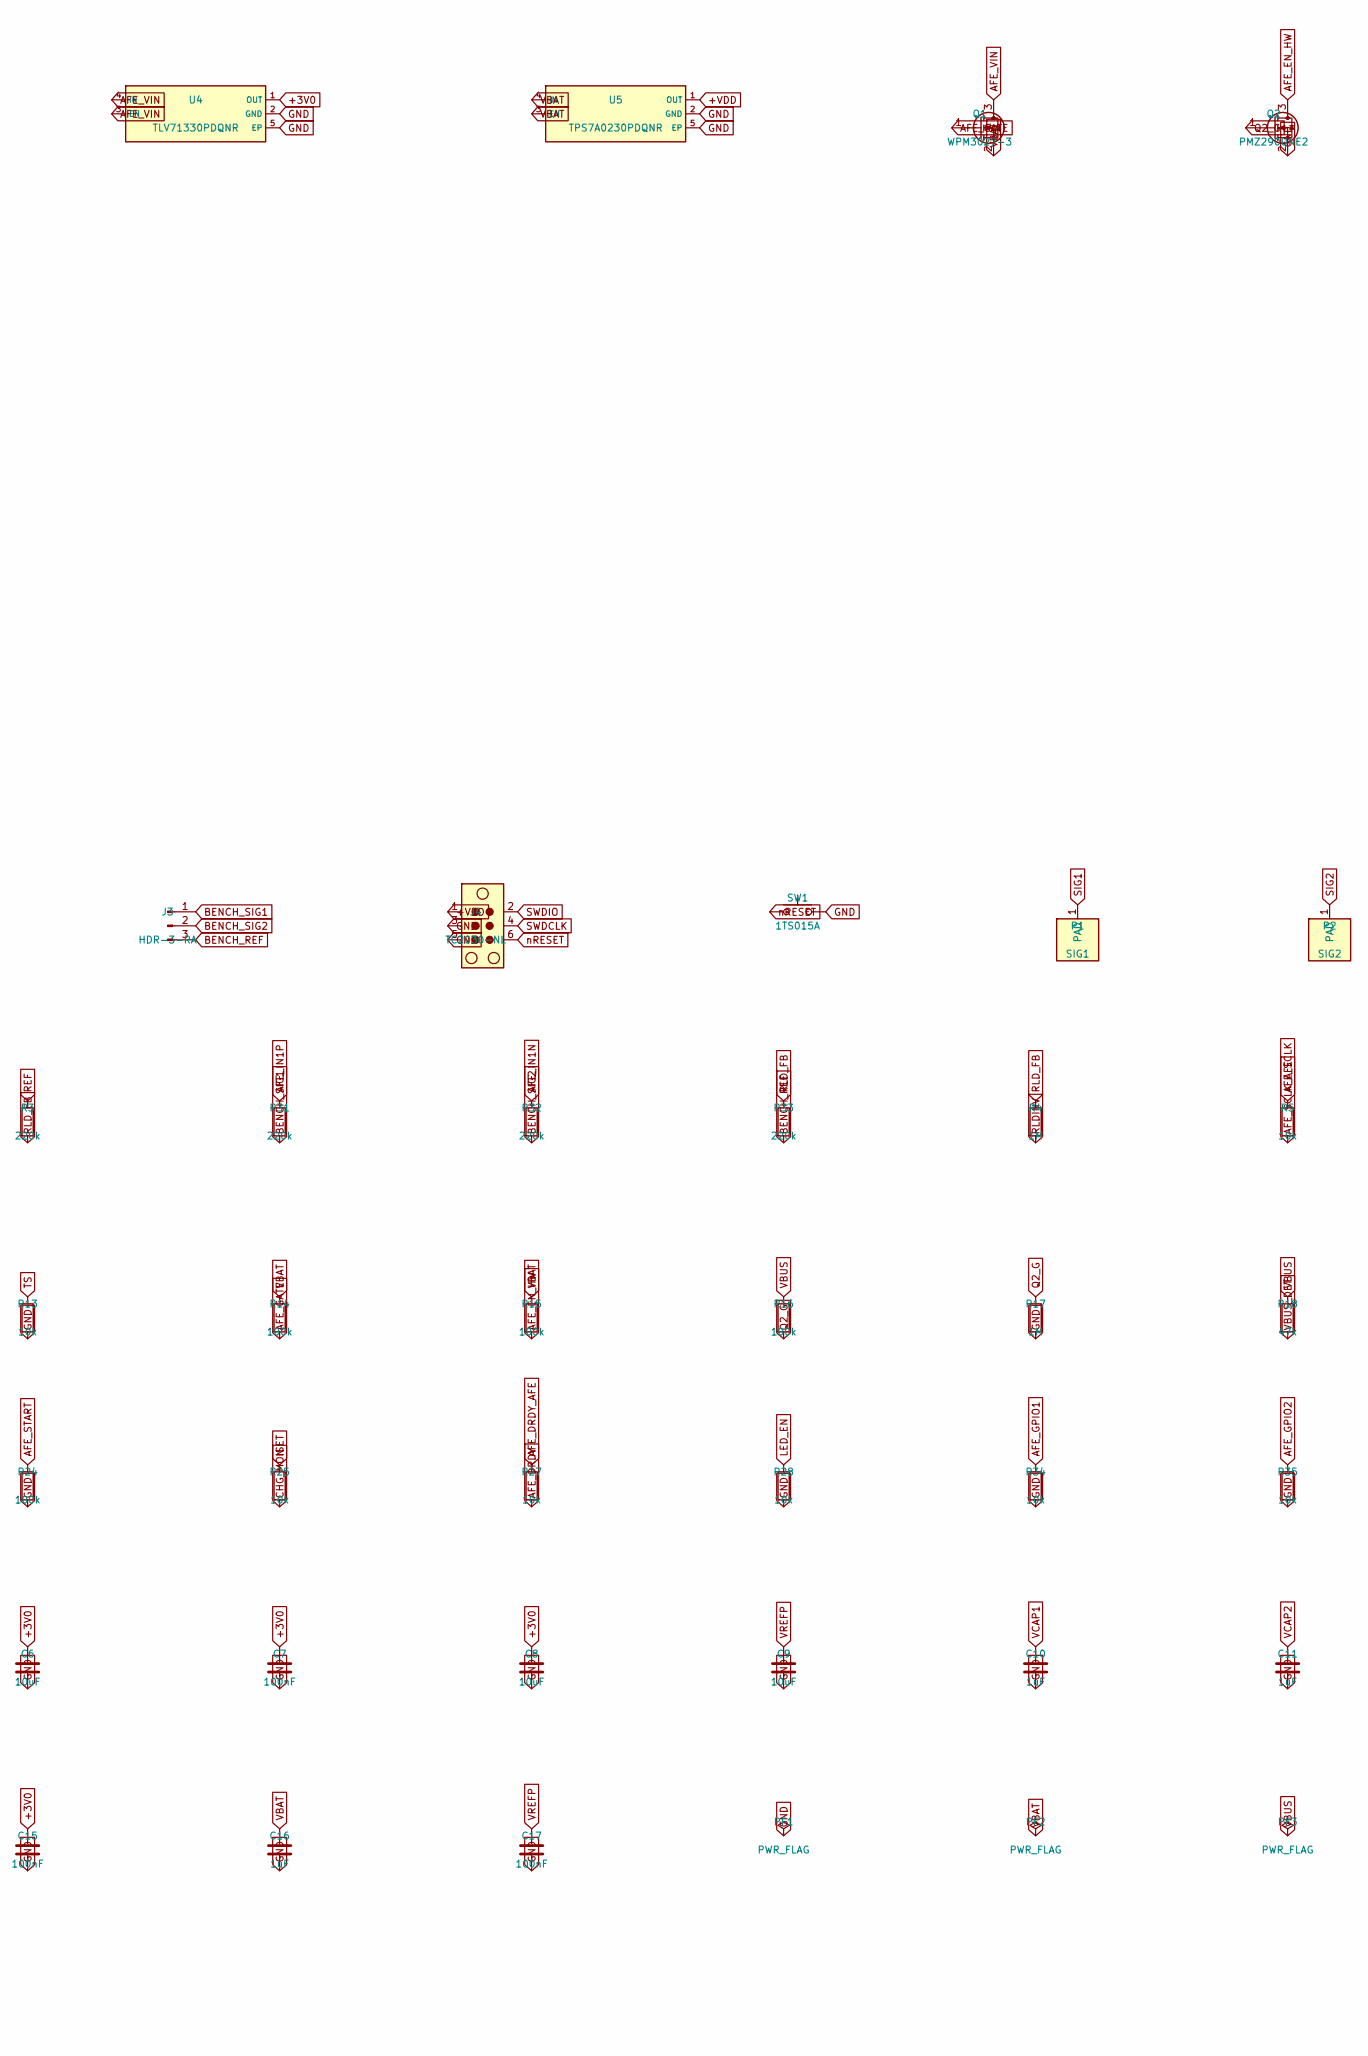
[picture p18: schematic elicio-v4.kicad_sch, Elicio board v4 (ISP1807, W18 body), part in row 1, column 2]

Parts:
C1: 1.5nF; C_0201_0603Metric; MPN 0201B152K500NT; LCSC C285104
C2: 10nF; C_0201_0603Metric; MPN TCC0201X7R103K500ZT; LCSC C5142551
C3, C14, C18, C19: 10uF; C_0402_1005Metric; MPN GRM155R61A106ME18D; LCSC C36626211
C4, C5, C10, C11, C13, C16: 1uF; C_0201_0603Metric; MPN TCC0201X5R105K6R3ZT; LCSC C5142566
C6, C8, C9: 10uF; C_0402_1005Metric; MPN CL05A106MQ5NUNC; LCSC C15525
C7, C12, C15, C17: 100nF; C_0201_0603Metric; MPN CL03A104KO3NNNC; LCSC C307380
D1: PESD5V0L1UL; D_SOD-882; MPN PESD5V0L1UL; LCSC C3001948
D2: LED-0402; LED_0402_1005Metric; MPN LTST-C281TGKT-5A; LCSC C364549
J2: 202656-0021; Molex_Pico-EZmate_Slim_202656-0021_1x02-1MP_P1.20mm_Vertical; MPN 202656-0021; LCSC CONSIGNED
J3: HDR-3-RA; PinHeader_1x03_P2.54mm_Horizontal; LCSC C49257
J4: TC2030-NL; Tag-Connect_TC2030-IDC-NL_2x03_P1.27mm_Vertical
P1: SIG1; RING_PAD_D5_H2.7
P2: SIG2; RING_PAD_D5_H2.7
P3: REF; RING_PAD_D5_H2.7
P4: CHARGE_VBUS; RING_1S_D4.6_NPTH2.7
P5: CHARGE_GND; RING_1S_D4.6_NPTH2.7
PF1, PF2, PF3, PF5: PWR_FLAG
Q1: WPM3027-3; SOT-883; MPN WPM3027-3/TR; LCSC C240195
Q2, Q3, Q4: PMZ290UNE2; SOT-883; MPN PMZ290UNE2YL; LCSC C478155
R1, R2, R3, R31, R32, R33: 220k; R_0402_1005Metric; LCSC C881401
R4, R17, R20, R21: 1M; R_0201_0603Metric; MPN 0201WMF1004TEE; LCSC C473482
R5, R6, R7, R8, R13, R25, R27, R28, R34, R35: 10k; R_0201_0603Metric; MPN 0201WMF1002TEE; LCSC C473048
R11: 6.8k; R_0201_0603Metric; MPN 0201WMF6801TEE; LCSC C423451
R12: 6.04k; R_0201_0603Metric; MPN 0201WMF6041TEE; LCSC C270341
R14, R15, R16, R23, R24: 100k; R_0201_0603Metric; MPN 0201WMF1003TEE; LCSC C270364
R18: 47k; R_0201_0603Metric; LCSC C270345
R19: 27k; R_0201_0603Metric; LCSC C270351
R22: 1k; R_0201_0603Metric; MPN 0201WMF1001TEE; LCSC C270365
SW1: 1TS015A; SW_HRO_1TS015A; MPN 1TS015A-1200-0600-CT; LCSC C398746
U1: ISP1807-LR; InsightSiP_ISP1807; MPN ISP1807-LR-RS; LCSC CONSIGNED
U2: ADS1292IRSMT; Texas_RSM0032; MPN ADS1292IRSMT; LCSC C89288
U3: BQ25100YFPR; Texas_YFP0006_V4; MPN BQ25100YFPR; LCSC CONSIGNED
U4: TLV71330PDQNR; Texas_X2SON-4_1x1mm_P0.65mm; MPN TLV71330PDQNR; LCSC C2863576
U5: TPS7A0230PDQNR; Texas_X2SON-4_1x1mm_P0.65mm; MPN TPS7A0230PDQNR; LCSC C2867950

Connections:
+3V0: C6.1, C7.1, C8.1, C15.1, U2.5 (IN2N), U2.6 (IN2P), U2.12 (AVDD), U2.14 (CLKSEL), U2.23 (DVDD), U2.31 (RESP_P), U2.32 (RESP_N), U4.1 (OUT)
+VDD: C12.1, C13.1, J4.1, U1.26 (VCC_nRF), U5.1 (OUT)
AFE_CS: R7.1, U1.48 (P0.28/AIN4)
AFE_CS_AFE: R7.2, U2.18 (CS)
AFE_DRDY: R27.2, U1.46 (P0.29/AIN5)
AFE_DRDY_AFE: R27.1, U2.22 (DRDY)
AFE_EN_HW: Q2.3 (D), Q3.1 (G), R15.2
AFE_GATE: Q1.1 (G), Q3.3 (D), R14.2
AFE_GPIO1: R34.1, U2.26 (GPIO1)
AFE_GPIO2: R35.1, U2.25 (GPIO2)
AFE_IN1N: R2.2, R32.1, U2.3 (IN1N)
AFE_IN1P: R1.2, R31.1, U2.4 (IN1P)
AFE_MISO: R8.2, U1.32 (P0.08)
AFE_MISO_AFE: R8.1, U2.21 (DOUT)
AFE_MOSI: R6.1, U1.36 (P0.05/AIN3)
AFE_MOSI_AFE: R6.2, U2.19 (DIN)
AFE_RESET: R23.1, U1.6 (P0.26), U2.15 (PWDN)
AFE_SCLK: R5.1, U1.34 (P0.06)
AFE_SCLK_AFE: R5.2, U2.20 (SCLK)
AFE_START: R24.1, U1.4 (P0.10/NFC2), U2.16 (START)
AFE_VIN: C5.1, PF5.1, Q1.3 (D), U4.3 (EN), U4.4 (IN)
BENCH_REF: J3.3, R33.2
BENCH_SIG1: J3.1, R31.2
BENCH_SIG2: J3.2, R32.2
CHG_LED_K: D2.1 (K), Q4.3 (D)
CHG_MON: R25.2, U1.44 (P0.30/AIN6)
D2_A: D2.2 (A), R22.2
GND: C2.2, C3.2, C4.2, C5.2, C6.2, C7.2, C8.2, C9.2, C10.2, C11.2, C12.2, C13.2, C14.2, C15.2, C16.2, C17.2, C18.2, C19.2, D1.2 (A), J2.2, J2.MP, J4.3, J4.5, P5.1, PF1.1, Q2.2 (S), Q3.2 (S), Q4.2 (S), R11.2, R12.2, R13.2, R17.2, R19.2, R21.2, R23.2, R24.2, R28.2, R34.2, R35.2, SW1.2, U1.1 (VSS), U1.7 (VSS), U1.14 (VSS), U1.16 (VSS), U1.18 (VSS), U1.21 (VSS), U1.23 (VSS), U1.24 (VSS), U1.25 (VSS), U1.31 (VSS), U2.10 (VREFN), U2.13 (AVSS), U2.24 (DGND), U2.33 (EP), U3.C2 (VSS), U4.2 (GND), U4.5 (EP), U5.2 (GND), U5.5 (EP)
ISET: C2.1, R11.1, R25.1, U3.B2 (ISET)
LED_EN: Q4.1 (G), R28.1, U1.38 (P0.03/AIN1)
PRETERM: R12.1, U3.C1 (PRETERM)
Q2_G: Q2.1 (G), R16.2, R17.1
REF: P3.1, R3.1
RF_ANT: U1.20 (OUT_ANT), U1.22 (OUT_MOD)
RLDINV: C1.2, R4.2, U2.28 (RLDINV)
RLD_FB: C1.1, R3.2, R4.1, R33.1, U2.29 (RLDIN), U2.30 (RLDOUT)
SIG1: P1.1, R1.1
SIG2: P2.1, R2.1
SWDCLK: J4.4, U1.30 (SWDCLK)
SWDIO: J4.2, U1.28 (SWDIO)
TS: C18.1, R13.1, U3.B1 (TS)
VBAT: C4.1, C14.1, C16.1, C19.1, J2.1, PF2.1, Q1.2 (S), R14.1, R15.1, R20.1, U3.A1 (OUT), U5.3 (EN), U5.4 (IN)
VBAT_SENSE: R20.2, R21.1, U1.42 (P0.31/AIN7)
VBUS: C3.1, D1.1 (K), P4.1, PF3.1, R16.1, R18.1, R22.1, U3.A2 (IN)
VBUS_DET: R18.2, R19.1, U1.40 (P0.02/AIN0)
VCAP1: C10.1, U2.11 (VCAP1)
VCAP2: C11.1, U2.27 (VCAP2)
VREFP: C9.1, C17.1, U2.9 (VREFP)
nRESET: J4.6, SW1.1, U1.13 (P0.18/RESET)

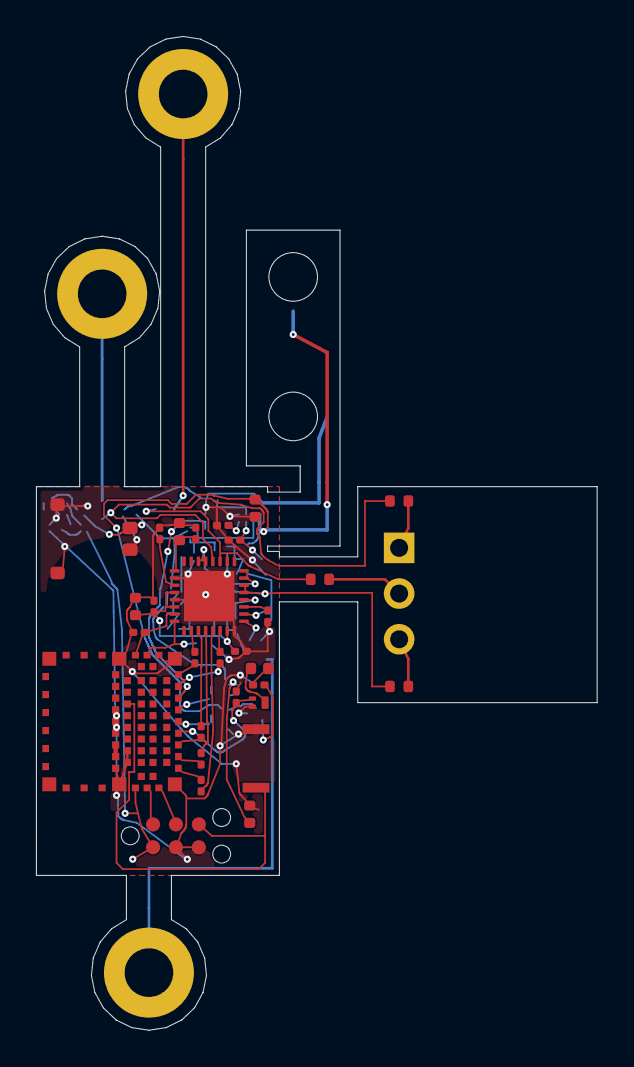
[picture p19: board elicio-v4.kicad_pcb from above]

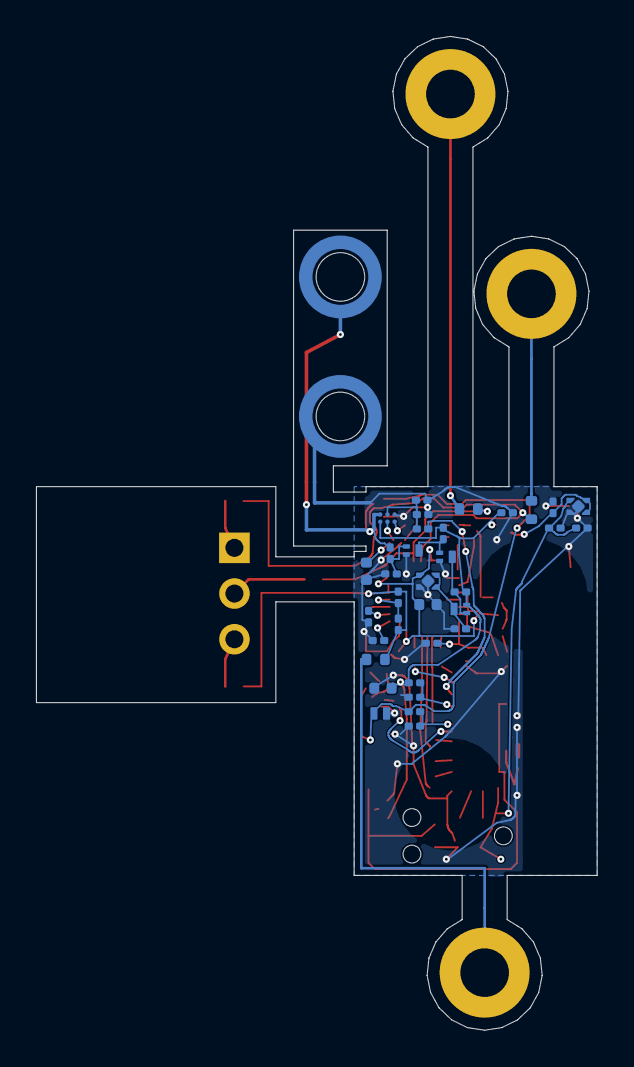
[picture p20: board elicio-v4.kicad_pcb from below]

Board: 2 copper layers, 31.1 x 55.2 mm, 69 parts (36 on the bottom side), 49 nets.

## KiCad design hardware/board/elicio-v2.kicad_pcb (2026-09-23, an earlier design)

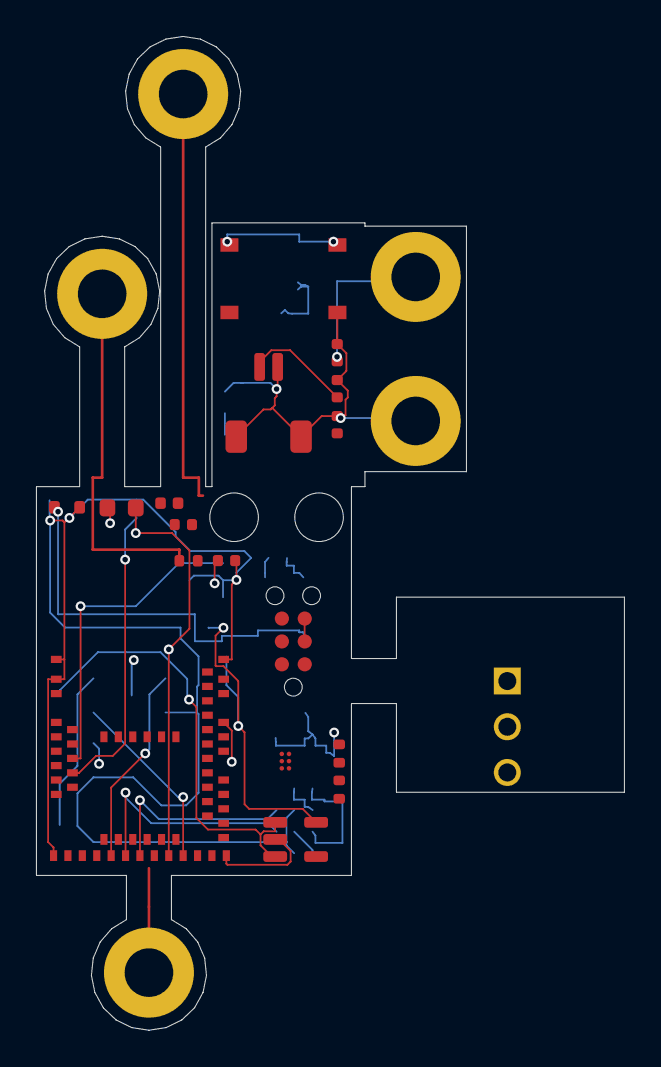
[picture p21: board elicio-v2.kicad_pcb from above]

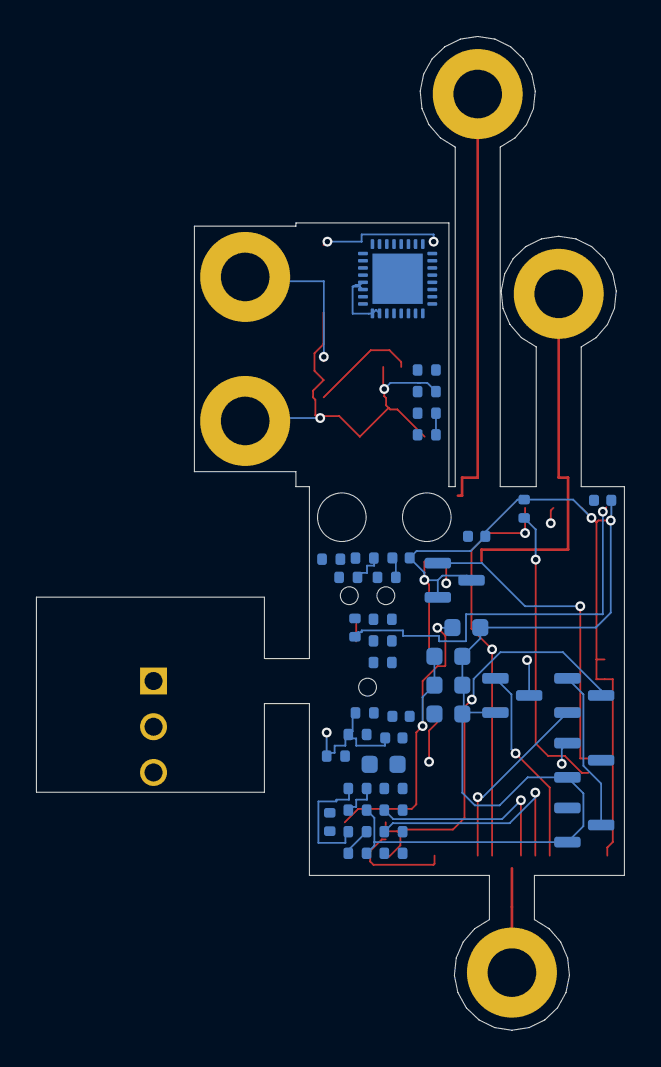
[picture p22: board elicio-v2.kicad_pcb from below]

Board: 2 copper layers, 32.7 x 55.2 mm, 66 parts (41 on the bottom side), 45 nets.

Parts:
C1: 1.5nF; C_0402_1005Metric
C2: 10nF; C_0402_1005Metric
C3, C4, C5, C10, C13: 1uF; C_0402_1005Metric
C6, C8, C9: 10uF; C_0603_1608Metric
C7, C15: 100nF; C_0603_1608Metric
C11, C12: 100nF; C_0402_1005Metric
C14: 4.7uF; C_0402_1005Metric
D1: PESD5V0L1UL; D_SOD-523
D2: LED-0402; LED_0402_1005Metric
H1, H2: HOLE_D2.7; MountingHole_M2.5
J2: SM02B-SRSS-TB; JST_SH_SM02B-SRSS-TB_1x02-1MP_P1.00mm_Horizontal
J3: HDR-3-RA; PinHeader_1x03_P2.54mm_Horizontal
J4: TC2030-NL; Tag-Connect_TC2030-IDC-NL_2x03_P1.27mm_Vertical
L1: 10uH; L_0603_1608Metric
P1: SIG1; RING_PAD_D5_H2.7
P2: SIG2; RING_PAD_D5_H2.7
P3: REF; RING_PAD_D5_H2.7
P4: CHARGE_VBUS; RING_PAD_D5_H2.7
P5: CHARGE_GND; RING_PAD_D5_H2.7
Q1: AO3401A; SOT-23
Q2, Q3, Q4, Q5: 2N7002; SOT-23
R1, R2, R3: 220k; R_0402_1005Metric
R4, R17, R20, R21: 1M; R_0402_1005Metric
R5, R6, R7, R8, R13, R25, R26, R27, R28: 10k; R_0402_1005Metric
R11: 6.80k; R_0402_1005Metric
R12: 6.04k; R_0402_1005Metric
R14, R15, R16, R23, R24: 100k; R_0402_1005Metric
R18: 47k; R_0402_1005Metric
R19: 27k; R_0402_1005Metric
R22: 1k; R_0402_1005Metric
R29, R30: 10M; R_0402_1005Metric
SW1: 4.5x4.5x1.6; SW_Push_1P1T_XKB_TS-1187A
U1: MDBT50Q-1MV2; Raytac_MDBT50Q
U2: ADS1292IRSMT; Texas_RSM0032
U3: BQ25100YFPR; Texas_YFP0006
U4: TLV71330PDBVR; SOT-23-5

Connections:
+3V0: C6.1, C7.1, C8.1, C15.1, U2.5, U2.6, U2.12, U2.14, U2.23, U2.31, U2.32, U4.5
+VDD: C12.1, C13.1, J4.1, L1.2, R26.2, U1.28
AFE_CS: R7.1, U1.37
AFE_CS_AFE: R7.2, U2.18
AFE_DRDY: R27.2, U1.41
AFE_DRDY_AFE: R27.1, U2.22
AFE_EN_HW: Q2.3, Q3.1, R15.2
AFE_GATE: Q1.1, Q3.3, R14.2
AFE_IN1N: R2.2, R30.1, U2.3
AFE_IN1P: R1.2, R29.1, U2.4
AFE_MISO: R8.2, U1.39
AFE_MISO_AFE: R8.1, U2.21
AFE_MOSI: R6.1, U1.22
AFE_MOSI_AFE: R6.2, U2.19
AFE_RESET: R23.1, U1.46, U2.15
AFE_SCLK: R5.1, U1.24
AFE_SCLK_AFE: R5.2, U2.20
AFE_START: R24.1, U1.44, U2.16
AFE_VIN: C5.1, Q1.3, U4.1, U4.3
BAT_MEAS_EN: Q5.1, U1.9
CHG_LED_K: D2.1, Q4.3
CHG_MON: R25.2, U1.12
D2_A: D2.2, R22.2
DCCH: L1.1, U1.31
GND: C2.2, C3.2, C4.2, C5.2, C6.2, C7.2, C8.2, C9.2, C10.2, C11.2, C12.2, C13.2, C14.2, C15.2, D1.2, J2.2, J2.MP, J4.3, J4.5, P5.1, Q2.2, Q3.2, Q4.2, Q5.2, Q5.3, R11.2, R12.2, R13.2, R17.2, R19.2, R21.2, R23.2, R24.2, R28.2, SW1.2, U1.1, U1.2, U1.15, U1.33, U1.55, U2.10, U2.13, U2.24, U2.33, U3.C2, U4.2
ISET: C2.1, R11.1, R25.1, U3.B2
LED_EN: Q4.1, R28.1, U1.20
PRETERM: R12.1, U3.C1
Q2_G: Q2.1, R16.2, R17.1
REF: J3.3, P3.1, R3.1
RLDINV: C1.2, R4.2, U2.28
RLD_FB: C1.1, R3.2, R4.1, R29.2, R30.2, U2.29, U2.30
SIG1: J3.1, P1.1, R1.1
SIG2: J3.2, P2.1, R2.1
SWDCLK: J4.4, U1.53
SWDIO: J4.2, U1.51
TS: R13.1, U3.B1
VBAT: C4.1, C14.1, J2.1, Q1.2, R14.1, R15.1, R20.1, U1.30, U3.A1
VBAT_SENSE: R20.2, R21.1, U1.11
VBUS: C3.1, D1.1, P4.1, R16.1, R18.1, R22.1, U1.32, U3.A2
VBUS_DET: R18.2, R19.1, U1.48
VCAP1: C10.1, U2.11
VCAP2: C11.1, U2.27
VREFP: C9.1, U2.9
nRESET: J4.6, R26.1, SW1.1, U1.40

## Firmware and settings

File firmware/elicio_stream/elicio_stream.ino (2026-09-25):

#include <SPI.h>
#include <bluefruit.h>

#include "board_pins.h"
#include "ads1292.h"
#include "frame_v2.h"
#include "undervoltage.h"

/* A product variant must define digital pin indices as nRF P0 numbers and
 * reserve these SPIM3 pins. The Feather variant is not the v4 pinout. */
#ifndef ELICIO_V4_PIN_VARIANT
#error "Build with an ISP1807 v4 Arduino variant, not the Feather variant"
#endif

SPIClass afe_spi(NRF_SPIM3, ELICIO_PIN_ADS_MISO, ELICIO_PIN_ADS_SCLK, ELICIO_PIN_ADS_MOSI);
BLEUart bleuart;

#define RING_LEN 256

static uint8_t ring_samples[RING_LEN][ADS1292_SAMPLE_BYTES];
static uint16_t ring_acq[RING_LEN];
static volatile uint16_t ring_w;
static volatile uint16_t ring_r;
static volatile uint16_t acq_index;
static volatile uint8_t overrun_sticky;

static uint16_t session_id = 1;
static uint16_t epoch_id = 1;
static uint16_t frame_seq;
static uint16_t battery_seq;
static uint16_t nus_payload = 20;
static uint8_t streaming;
static uint8_t sent_stop;
static uint8_t pending_restart;
static UvMachine uv;
static uint32_t last_battery_ms;
static uint16_t next_acq;
static uint8_t have_next_acq;
static uint8_t afe_safe;

static void ads_select(int asserted) {
    digitalWrite(ELICIO_PIN_ADS_CS, asserted ? LOW : HIGH);
}

static void ads_xfer(const uint8_t *tx, uint8_t *rx, size_t n) {
    for (size_t i = 0; i < n; i++) {
        uint8_t b = afe_spi.transfer(tx ? tx[i] : 0);
        if (rx != NULL) {
            rx[i] = b;
        }
    }
}

static void ads_delay_us(unsigned us) {
    /* The 1 s POR wait must yield; delayMicroseconds is only for short pulses. */
    if (us >= 1000u) {
        delay(us / 1000u);
        us %= 1000u;
    }
    if (us != 0u) {
        delayMicroseconds(us);
    }
}

static void ads_pwdn(int high) { digitalWrite(ELICIO_PIN_ADS_PWDN, high ? HIGH : LOW); }

static void ads_start_pin(int high) { digitalWrite(ELICIO_PIN_ADS_START, high ? HIGH : LOW); }

static const Ads1292Bus ADS_BUS = {
    ads_select, ads_xfer, ads_delay_us, ads_pwdn, ads_start_pin,
};

static uint8_t vbus_present(void) {
    return digitalRead(ELICIO_PIN_VBUS_DET) ? 1 : 0;
}

static uint16_t battery_mv(void) {
    /* R20/R21: 1 MΩ / 1 MΩ; set SAADC reference/gain for 3.6 V full scale. */
    float vbat = analogRead(ELICIO_PIN_VBAT_SENSE) * 2.0f * 3.6f / 4096.0f;
    if (vbat < 0) {
        vbat = 0;
    }
    return (uint16_t)(vbat * 1000.0f);
}

static void drdy_isr(void) {
    uint16_t next = (uint16_t)((ring_w + 1u) % RING_LEN);
    uint16_t idx = acq_index;
    acq_index = (uint16_t)(acq_index + 1u);
    if (next == ring_r) {
        overrun_sticky = 1;
        return;
    }
    uint8_t sample[ADS1292_SAMPLE_BYTES];
    if (ads1292_read_sample(&ADS_BUS, sample) != 0) {
        overrun_sticky = 1;
        return;
    }
    memcpy(ring_samples[ring_w], sample, ADS1292_SAMPLE_BYTES);
    ring_acq[ring_w] = idx;
    ring_w = next;
}

static void send_packet(const uint8_t *p, uint16_t n) {
    if (!Bluefruit.connected()) {
        return;
    }
    bleuart.write(p, n);
}

static void send_logical(uint8_t msg, uint16_t seq, const uint8_t *logical, size_t logical_len) {
    uint8_t packed[512];
    uint16_t lens[16];
    uint8_t count = 0;
    if (frame_v2_fragment(msg, session_id, seq, logical, logical_len, nus_payload, packed,
                          sizeof(packed), lens, 16, &count) != 0) {
        return;
    }
    size_t off = 0;
    for (uint8_t i = 0; i < count; i++) {
        send_packet(packed + off, lens[i]);
        off += lens[i];
    }
}

static void send_hello(uint8_t flags, uint8_t reason) {
    FrameV2HelloMeta meta;
    memset(&meta, 0, sizeof(meta));
    meta.session_id = session_id;
    meta.epoch_id = epoch_id;
    meta.acq_index = acq_index;
    meta.nus_payload = nus_payload;
    meta.flags = flags;
    meta.stop_reason = reason;
    meta.gain = FRAME_V2_GAIN;
    meta.rate_id = FRAME_V2_RATE_2000;
    meta.vref_id = FRAME_V2_VREF_INT_242;
    meta.sample_bytes = FRAME_V2_SAMPLE_BYTES;
    uint8_t logical[FRAME_V2_HELLO_LEN + FRAME_V2_CRC_LEN];
    size_t n = 0;
    if (frame_v2_pack_hello(logical, sizeof(logical), &meta, &n) != 0) {
        return;
    }
    send_logical(FRAME_V2_MSG_HELLO, 0, logical, n);
}

static void send_battery(void) {
    FrameV2BatteryMeta meta;
    memset(&meta, 0, sizeof(meta));
    meta.session_id = session_id;
    meta.msg_seq = battery_seq++;
    meta.millivolts = battery_mv();
    meta.flags = uv.flags;
    meta.stop_reason = uv.stop_reason;
    uint8_t logical[FRAME_V2_BATTERY_LEN + FRAME_V2_CRC_LEN];
    size_t n = 0;
    if (frame_v2_pack_battery(logical, sizeof(logical), &meta, &n) != 0) {
        return;
    }
    send_logical(FRAME_V2_MSG_BATTERY, meta.msg_seq, logical, n);
}

static void send_stream(const FrameV2StreamMeta *meta, const uint8_t *samples) {
    uint8_t logical[FRAME_V2_MAX_LOGICAL];
    size_t n = 0;
    if (frame_v2_pack_stream(logical, sizeof(logical), meta, samples, &n) != 0) {
        return;
    }
    send_logical(FRAME_V2_MSG_STREAM, meta->frame_seq, logical, n);
    frame_seq = (uint16_t)(frame_seq + 1u);
}

/*
 * With VBUS present the v4 hardware interlock Q2/Q3 turns Q1 off.
 * An output left high into the unpowered ADS1292
 * would feed its rail through the input clamps, so the control and SPI
 * pins go high-impedance until VBUS is gone (review r5).
 */
static void afe_pins_safe(void) {
    if (afe_safe) {
        return;
    }
    afe_spi.endTransaction();
    afe_spi.end();
    pinMode(ELICIO_PIN_ADS_SCLK, INPUT);
    pinMode(ELICIO_PIN_ADS_MOSI, INPUT);
    pinMode(ELICIO_PIN_ADS_CS, INPUT);
    pinMode(ELICIO_PIN_ADS_PWDN, INPUT);
    pinMode(ELICIO_PIN_ADS_START, INPUT);
    afe_safe = 1;
}

static void afe_pins_active(void) {
    /* Preload the output latches *before* enabling drive: a VBUS-to-cell
       transition must not briefly release PWDN or assert START. */
    digitalWrite(ELICIO_PIN_ADS_CS, LOW);
    digitalWrite(ELICIO_PIN_ADS_PWDN, LOW);
    digitalWrite(ELICIO_PIN_ADS_START, LOW);
    pinMode(ELICIO_PIN_ADS_CS, OUTPUT);
    pinMode(ELICIO_PIN_ADS_PWDN, OUTPUT);
    pinMode(ELICIO_PIN_ADS_START, OUTPUT);
    afe_spi.begin();
    digitalWrite(ELICIO_PIN_ADS_CS, HIGH);
    afe_spi.beginTransaction(SPISettings(1000000, MSBFIRST, SPI_MODE1));
    afe_safe = 0;
}

static void start_acquisition(void) {
    if (afe_safe) {
        afe_pins_active();
    }
    have_next_acq = 0;
    ring_w = 0;
    ring_r = 0;
    overrun_sticky = 0;
    ads1292_apply_worn_regs(&ADS_BUS);
    ads1292_start_rdatac(&ADS_BUS);
    attachInterrupt(digitalPinToInterrupt(ELICIO_PIN_ADS_DRDY), drdy_isr, FALLING);
    streaming = 1;
    sent_stop = 0;
    /* LED_EN is a VBUS-powered charge LED, not a stream indicator. */
}

static void stop_acquisition(void) {
    detachInterrupt(digitalPinToInterrupt(ELICIO_PIN_ADS_DRDY));
    ads1292_stop(&ADS_BUS);
    streaming = 0;
}

static void connect_cb(uint16_t handle) {
    BLEConnection *conn = Bluefruit.Connection(handle);
    if (conn != NULL) {
        conn->requestMtuExchange(247);
        delay(20);
        uint16_t mtu = conn->getMtu();
        if (mtu > 3) {
            nus_payload = (uint16_t)(mtu - 3);
        }
    }
    send_hello(uv.flags, uv.stop_reason == FRAME_V2_STOP_NONE ? FRAME_V2_STOP_RESET : uv.stop_reason);
}

void setup() {
    pinMode(ELICIO_PIN_ADS_DRDY, INPUT);
    pinMode(ELICIO_PIN_VBUS_DET, INPUT);
    pinMode(ELICIO_PIN_LED_EN, OUTPUT);
    digitalWrite(ELICIO_PIN_LED_EN, LOW);
    /* Do not drive U2 before checking the hardware charge interlock. */
    if (vbus_present()) {
        afe_safe = 1;
        pinMode(ELICIO_PIN_ADS_SCLK, INPUT);
        pinMode(ELICIO_PIN_ADS_MOSI, INPUT);
        pinMode(ELICIO_PIN_ADS_CS, INPUT);
        pinMode(ELICIO_PIN_ADS_PWDN, INPUT);
        pinMode(ELICIO_PIN_ADS_START, INPUT);
    } else {
        afe_pins_active();
    }

    uv_init(&uv);
    analogReadResolution(12);

    Bluefruit.configPrphBandwidth(BANDWIDTH_MAX);
    Bluefruit.begin();
    Bluefruit.setName("elicio-v2");
    Bluefruit.Periph.setConnectCallback(connect_cb);
    bleuart.begin();
    Bluefruit.Advertising.addFlags(BLE_GAP_ADV_FLAGS_LE_ONLY_GENERAL_DISC_MODE);
    Bluefruit.Advertising.addTxPower();
    Bluefruit.Advertising.addService(bleuart);
    Bluefruit.ScanResponse.addName();
    Bluefruit.Advertising.restartOnDisconnect(true);
    Bluefruit.Advertising.start(0);

    last_battery_ms = millis();
    if (!vbus_present()) {
        start_acquisition();
    }
}

void loop() {
    uint8_t vbus = vbus_present();
    uint8_t was_stopped = (uv.state == UV_STOPPED);
    uv_update(&uv, battery_mv(), vbus);

    if (uv.flags & FRAME_V2_FLAG_VBUS) {
        if (streaming) {
            /* The AFE rail is already off: no SPI to it, pins high-Z. */
            detachInterrupt(digitalPinToInterrupt(ELICIO_PIN_ADS_DRDY));
            streaming = 0;
            digitalWrite(ELICIO_PIN_LED_EN, LOW);
        }
        afe_pins_safe();
        if (Bluefruit.connected() && !sent_stop) {
            FrameV2StreamMeta meta;
            memset(&meta, 0, sizeof(meta));
            meta.session_id = session_id;
            meta.frame_seq = frame_seq;
            meta.acq_index = acq_index;
            meta.sample_count = 0;
            meta.flags = uv.flags;
            meta.stop_reason = FRAME_V2_STOP_VBUS;
            meta.gain = FRAME_V2_GAIN;
            meta.sample_bytes = FRAME_V2_SAMPLE_BYTES;
            send_stream(&meta, NULL);
            sent_stop = 1;
        }
    } else if (uv.state == UV_STOPPED) {
        if (streaming) {
            stop_acquisition();
        }
        if (Bluefruit.connected() && !sent_stop) {
            FrameV2StreamMeta meta;
            memset(&meta, 0, sizeof(meta));
            meta.session_id = session_id;
            meta.frame_seq = frame_seq;
            meta.acq_index = acq_index;
            meta.sample_count = 0;
            meta.flags = uv.flags;
            meta.stop_reason = FRAME_V2_STOP_UNDERVOLTAGE;
            meta.gain = FRAME_V2_GAIN;
            meta.sample_bytes = FRAME_V2_SAMPLE_BYTES;
            send_stream(&meta, NULL);
            sent_stop = 1;
        }
    } else {
        if (was_stopped) {
            pending_restart = 1;
        }
        if (!streaming) {
            start_acquisition();
        }
    }

    if (streaming && Bluefruit.connected()) {
        uint16_t n = frame_v2_samples_for_nus(nus_payload);
        if (n == 0) {
            n = 1;
        }
        uint16_t avail = (uint16_t)((ring_w + RING_LEN - ring_r) % RING_LEN);
        if (avail >= n) {
            uint8_t payload[FRAME_V2_MAX_SAMPLES * ADS1292_SAMPLE_BYTES];
            uint16_t first = ring_acq[ring_r];
            noInterrupts();
            uint8_t over = overrun_sticky;
            overrun_sticky = 0;
            /* A frame's samples are consecutive DRDYs from acq_index
               (frame-v2.md): stop at the first gap the ring overrun left. */
            uint16_t k = 0;
            while (k < n && ring_r != ring_w && ring_acq[ring_r] == (uint16_t)(first + k)) {
                memcpy(payload + k * ADS1292_SAMPLE_BYTES, ring_samples[ring_r], ADS1292_SAMPLE_BYTES);
                ring_r = (uint16_t)((ring_r + 1u) % RING_LEN);
                k++;
            }
            interrupts();
            n = k;
            if (have_next_acq && first != next_acq) {
                over = 1;
            }
            next_acq = (uint16_t)(first + n);
            have_next_acq = 1;
            FrameV2StreamMeta meta;
            memset(&meta, 0, sizeof(meta));
            meta.session_id = session_id;
            meta.frame_seq = frame_seq;
            meta.acq_index = first;
            meta.sample_count = n;
            meta.payload_bytes = (uint16_t)(n * ADS1292_SAMPLE_BYTES);
            meta.flags = (uint8_t)((over ? FRAME_V2_FLAG_OVERRUN : 0) |
                                   (pending_restart ? FRAME_V2_FLAG_RESTART : 0));
            meta.stop_reason = FRAME_V2_STOP_NONE;
            meta.gain = FRAME_V2_GAIN;
            meta.rate_id = FRAME_V2_RATE_2000;
            meta.vref_id = FRAME_V2_VREF_INT_242;
            meta.sample_bytes = FRAME_V2_SAMPLE_BYTES;
            send_stream(&meta, payload);
            pending_restart = 0;
        }
    }

    uint32_t now = millis();
    if (Bluefruit.connected() && (now - last_battery_ms) >= 10000u) {
        last_battery_ms = now;
        send_battery();
    }
}

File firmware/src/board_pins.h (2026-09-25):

#ifndef ELICIO_BOARD_PINS_H
#define ELICIO_BOARD_PINS_H

/*
 * v4 ISP1807-LR pad -> nRF52840 P0.xx (not Feather digital pin numbers).
 * Source: ISP1807 datasheet R19 §3 pin table, pp. 10-11,
 * https://www.insightsip.com/fichiers_insightsip/pdf/ble/ISP1807/isp_ble_DS1807.pdf
 * read 2026-09-25; net assignments: committed elicio-v4.kicad_sch/pcb.
 * A product Arduino variant must map these physical pins to its digital pins;
 * the Feather SPI object and digital-pin indices are NOT the product variant.
 */
#define ELICIO_PIN_ADS_SCLK 6 /* P0.06, U1.34 AFE_SCLK */
#define ELICIO_PIN_ADS_MOSI 5 /* P0.05, U1.36 AFE_MOSI */
#define ELICIO_PIN_ADS_MISO 8 /* P0.08, U1.32 AFE_MISO */
#define ELICIO_PIN_ADS_CS 28 /* P0.28, U1.48 AFE_CS; LF only */
#define ELICIO_PIN_ADS_DRDY 29 /* P0.29, U1.46 AFE_DRDY; LF only */
#define ELICIO_PIN_ADS_START 10 /* P0.10, U1.4 AFE_START; NFC2 as GPIO */
#define ELICIO_PIN_ADS_PWDN 26 /* P0.26, U1.6 AFE_RESET (ADS PWDN/RESET) */
#define ELICIO_PIN_VBUS_DET 2 /* P0.02, U1.40 VBUS_DET; LF only */
#define ELICIO_PIN_CHG_MON 30 /* P0.30, U1.44 CHG_MON; AIN6, LF only */
#define ELICIO_PIN_VBAT_SENSE 31 /* P0.31, U1.42 VBAT_SENSE; AIN7, LF only */
#define ELICIO_PIN_LED_EN 3 /* P0.03, U1.38 LED_EN; LF only */
#define ELICIO_PIN_NRESET 18 /* P0.18, U1.13 nRESET; configure UICR PSELRESET */

/* U1.28 SWDIO and U1.30 SWDCLK are dedicated debug signals, not GPIO.
 * U1.26 +VDD comes from U5; U1.20/22 RF_ANT, VSS pads 1,7,14,16,18,
 * 21,23,24,25,31. U1.8/10 USB and U1.12 VBUS are not connected.
 * BAT_MEAS_EN / Q5 were removed; AFE_EN_HW is a hardware charge interlock,
 * not MCU GPIO. Charge status is the ADC CHG_MON net (no separate STAT pin).
 */
#endif

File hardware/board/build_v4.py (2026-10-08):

#!/usr/bin/env python3
"""Place elicio-v4 (W18 body, ISP1807) from the table below, sync nets, save.

docs/fab/board-v4-design.md §4-§6. The flex is drawn flat: PCB (x, y) =
packing (u, s) in mm. Folded shell sites are in the note's §10 tables.

Run with KiCad's python:
  build_v4.py [--out PCB]         build elicio-v4.kicad_pcb (unrouted, pre-routes locked);
                                  --out writes elsewhere and leaves the routed board alone
  build_v4.py --export-dsn OUT    Specctra DSN for Freerouting
  build_v4.py --import-ses SES [PCB]  import a Freerouting session, clamp widths
"""
from __future__ import annotations

import math
import os
import re
import subprocess
import sys
from pathlib import Path

HERE = Path(__file__).resolve().parent
sys.path.insert(0, str(HERE))

import build_v2b as b2  # noqa: E402  (starts wx.App, imports pcbnew)
from build_v2b import (  # noqa: E402
    add_filled_circle,
    add_locked_path,
    add_named_area,
    add_segments,
    add_text,
    clamp_track_widths,
    ensure_net,
    hide_silk_in_file,
    load_fp,
    pad_center,
    parse_netlist,
    stamp_paste_pad_nets,
    strip_silk,
    tab_detour,
    v2,
)

import pcbnew  # noqa: E402

KICAD_FP = b2.KICAD_FP
b2.LIBS["Connector_Molex"] = KICAD_FP / "Connector_Molex.pretty"
b2.LIBS["Package_SON"] = KICAD_FP / "Package_SON.pretty"

BOARD = HERE / "elicio-v4"
NET_PATH = Path("/tmp/elicio-v4/elicio-v4.net")

# JLC 2-layer flex (design note §3): track/space 0.10, standard via 0.40/0.15
# (JLC flex page: hole >= 0.15, pad >= 0.35, 0.40 recommended). Contact class
# keeps v2's 0.15 track / 0.20 clearance.
FLEX_TRACK = 0.10
FLEX_CLEAR = 0.10
VIA_D = 0.40
VIA_DRILL = 0.15
CONTACT_TRACK = 0.15
CONTACT_CLEAR = 0.20
CONTACT_NETS = ("SIG1", "SIG2", "REF")
# Bench nets live on the J3 tab only, behind their own 220 kOhm (R31-R33);
# they take the Contact class rules there.
BENCH_NETS = ("BENCH_SIG1", "BENCH_SIG2", "BENCH_REF")
CHARGE_TRACK = 0.20
TAB_RULE_HALF = 3.50  # Q84/Q88 7 x 7 zones

# Island (design note §5.1). Cavity u 1.50-16.50 at W 18: everything east of
# U1 sits 1.0 further out than the W17 draft (§1.4 says why W17 was dropped).
BODY_W = 18.0
DW = BODY_W - 17.0
U0, U1_EDGE = 2.25, 14.75 + DW
S0, S1 = 16.00, 37.60
# P4/P5 joint: 90° fold at R 1.1 from u 15.09; relief notch s 16.0-19.6.
BEND_U0, BEND_U1 = 14.090 + DW, 15.904 + DW
JOINT_S0, JOINT_S1 = 16.30, 19.30
NOTCH_S1 = 19.60
PLATE_U0, PLATE_U1 = 12.914 + DW, 18.114 + DW
PLATE_S0, PLATE_S1 = 1.75, 14.85
P4_FLAT = (15.514 + DW, 4.35)
P5_FLAT = (15.514 + DW, 12.10)
# SIG/REF strips: v2's Q83 fold (180° at R 1.5 at the neck), same flat rings.
STRIP_W = 2.50
CAP_R = 3.20
SIG1_ATTACH, SIG1_SITE = (5.90, S0), (5.90, 5.29)
SIG2_ATTACH, SIG2_SITE = (10.40, S0), (10.40, -5.81)
REF_ATTACH, REF_SITE = (8.50, S1), (8.50, 43.00)
# J3 break-off tab (bench header). Cut before closing. The tab carries the
# bench nets behind their own 220 kOhm (R31-R33, design note §5.4), so the
# copper crossing the cut is AFE-side and no Contact copper leaves the
# island (Q97(d)). R32 sits on the neck; R31 and R33 sit south and north of
# J3's courtyard. The tab's west edge keeps 1.0 from the P4/P5 flap.
J3_NECK_S0, J3_NECK_S1 = 19.90, 22.40
J3_CUT_U = 15.20 + DW
J3_TAB_U0, J3_TAB_U1 = 19.10 + DW, 32.40 + DW
J3_TAB_S0, J3_TAB_S1 = 16.00, 28.00
J3_PIN1 = (21.40 + DW, 19.40)
J3_R31 = (21.40 + DW, 16.80)   # AFE_IN1P <- BENCH_SIG1, north of the header
J3_R33 = (21.40 + DW, 27.10)   # RLD_FB <- BENCH_REF, south of the header
J3_R32 = (17.00 + DW, 21.15)   # AFE_IN1N <- BENCH_SIG2, on the neck
# Neck runs, all F, 0.75 apart: AFE_IN1P north, AFE_IN1N middle, RLD_FB south
# (U2's input pads sit north of its RLD pads, so the runs don't cross).
J3_S_IN1P, J3_S_IN1N, J3_S_REF = 20.40, 21.15, 21.90
J3_LANE_IN1P_U, J3_LANE_REF_U = 19.50 + DW, 19.90 + DW  # F columns in the tab's west margin
J3_ISLAND_U = 14.75 + DW  # the locked neck runs end at the neck root (island edge); the router takes them on
# Contact corridor (design note §5.4), Contact class 0.15 / 0.20: strips to
# R1-R3 only. SIG2 crosses to B at the strip root (P2 is plated, so its
# strip copper is F); REF runs along the +s edge and down the +u edge on B.
SIG1_CORR_S = 16.40
SIG2_VIA = (10.40, 16.50)
REF_CORR_U = 14.35 + DW
# Charge nets cross the joint on B: GND north, VBUS south (VBUS goes F -> B
# on the flap, clear of the bend and 1.0 mm clear of GND inside P5's zone).
VBUS_FLAP_VIA = (17.40 + DW, 17.00)
P5_ZONE_EXIT_S = P5_FLAT[1] + TAB_RULE_HALF + 0.15
CHG_GND_S, CHG_VBUS_S = 16.90, 18.40
# Test header J4 and the reset line (design note §4.3).
VDD_VIA = (7.60, 36.70)
J4_GND_VIA = (10.63, 36.70)
NRST_S = 37.25
NRST_E_U = 14.95
# ISP1807 (design note §4.2): u = 10.45 - Y, s = MOD_S0 + X; KiCad rot 270.
MOD_S0 = 25.05
U1_CENTRE = (6.45, MOD_S0 + 4.0)
RF_BAND = (U0, 21.80, 6.45, S1)
# Landings (standoff tops) and lid posts (design note §5.3).
P1_LAND = (5.90, 22.00)
P2_LAND = (10.40, 33.10)
LAND_R = 3.20
POST_P1 = (5.90, 23.00)
POST_P2 = (9.40, 32.10)
POST_KEEP_R = 1.30
# B-side FR4 0.2 under U1, the P2 landing and J4 (one stiffener).
STIFF_U1_B = [
    (2.45, MOD_S0), (10.70, MOD_S0), (10.70, 29.90), (13.80 + DW, 29.90),
    (13.80 + DW, 37.30), (6.45, 37.30), (6.45, MOD_S0 + 8.0), (2.45, MOD_S0 + 8.0),
]
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

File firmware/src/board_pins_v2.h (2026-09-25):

#ifndef ELICIO_BOARD_PINS_V2_H
#define ELICIO_BOARD_PINS_V2_H

/* Archived v2 MDBT50Q GPIO map, docs/fab/board-v2.md §9. */
#define ELICIO_PIN_ADS_SCLK 8 /* P0.08 */
#define ELICIO_PIN_ADS_MOSI 6 /* P0.06 */
#define ELICIO_PIN_ADS_MISO 15 /* P0.15 */
#define ELICIO_PIN_ADS_CS 13 /* P0.13 */
#define ELICIO_PIN_ADS_DRDY 17 /* P0.17 */
#define ELICIO_PIN_ADS_START 20 /* P0.20 */
#define ELICIO_PIN_ADS_PWDN 22 /* P0.22 */
#define ELICIO_PIN_VBUS_DET 24 /* P0.24 */
#define ELICIO_PIN_CHG_MON 31 /* P0.31 */
#define ELICIO_PIN_VBAT_SENSE 2 /* P0.02 */
#define ELICIO_PIN_BAT_MEAS_EN 3 /* P0.03 */
#define ELICIO_PIN_LED_EN 4 /* P0.04 */
#define ELICIO_PIN_LED_STREAM ELICIO_PIN_LED_EN
#define ELICIO_PIN_NRESET 18 /* P0.18 */
#define ELICIO_PIN_RECOVERY ELICIO_PIN_NRESET

#endif

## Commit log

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2026-08-13 Add earpiece direction record and live capture path
    Record the 2026-08-13 decisions: subtlety is the binding requirement,
    hardware is self-built, and the target is a single earpiece reading the
    auricular muscles (owner-verified voluntary control), with masseter
    confirmation and a sealed-tip pressure channel as candidates.
    Bridge real one-channel streams into the existing signal path: a capture
    command saving deterministic recording JSON as the permanent source
    record, a terminal envelope scope for biofeedback training, and a
    replay-recording command running captures through detection, policy,
    audit, and the marker action. The detector symbol is now configurable
    without policy changes.
    Co-A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
    [cli.py, test_capture.py]
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2026-09-17 review(WP2): fix the parameter overlay rules
    default.toml passed with --params was loaded as an overlay: every M key
    counted as measured, the REF emboss vanished, and the README's reference
    command no longer reproduced the committed lid. An empty rolf.toml
    computed CREASE_BOW from the default M1/M2 (11.0, clamped to 8) instead
    of keeping 3.0; plan §3.3 computes it only when both are measured.
    HOOK_RADIUS ignored a measured M8 unless the bow was also computed.
    default.toml is now never an overlay; the bow is computed only when the
    overlay sets M1 and M2 and not CREASE_BOW; HOOK_RADIUS always follows M8
    (+0.75, the only clearance matching the plan's 13.5, (−9.5, 3, 0) and the
    strict < M8 +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
    [test_cad.py]
2026-09-17 review(WP2): run the checks plan §3.3 and §3.6 name, from geometry
    The wall check tested parameters that drive nothing (WALL_SIDE never
    reached the cavity), E5_lip compared the literal 1.0 with 1.0, the fit
    table was a copy of the plan, the contact-axis check passed if any cap
    stood proud, a missing trimesh passed the watertight check, a failed
    emboss was a note, and the 0.09 mm pad-to-keep-out gap WP1 handed over
    was never computed.
    Walls, E1-E5 and every §3.6 nominal now come from the feature constants
    and must match the plan; CONTACT_STACK checks the 4.13 top, the tip past
    the nut and wall +0.3; the KEEPOUT_SIGNAL gaps to pads, rib and walls are
    computed in the body frame (0.15 mm at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
    [test_cad.py]
2026-09-17 review(WP2): build the fillets the plan asks for and fix three solids
    _try_fillet trusted OCCT max_fillet, which throws on these shapes, so the
    0.8 lid edge was silently skipped and the tip round capped at 1.6 (thin:
    none). It now tries the requested radius first and steps down by 0.25,
    and every result is a manifest note.
    - Tip round 4.0 (§3.5 step 2) now builds on full and thin: sharp body and
    tail fused, tip corners rounded, then FILLET_MEDIAL along the medial
    outline (fusing two filleted pieces left a sliver the 3MF mesher
    rejects).
    - The hook's −5° stub reached 4.6 mm³ into the cavity and battery pocket;
    it is cut back to the cavity wall (§2 row 6). The joint fillet then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
    [body_full_p15.3mf, body_full_p15.step, body_full_p15.stl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]
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2026-09-17 review(WP2): keep the hook in one piece at large CREASE_BOW
    At CREASE_BOW 8 the top face tilts 39°, the hook root runs about 20 mm³
    through the cavity, and cutting the stub left a sliver of tube inside
    the floor as a second solid, so the build failed. The cut result is
    fused whole and the one-solid check runs on body plus hook. Bows 1 and 8
    now build in a test; the joint fillet reaches 0.75 at bow 8 and the
    manifest notes record it.
    Claude-Session: https://claude.ai/code/session_01XwA9GjzbZUB6YBaXjwbyER
    [test_cad.py]
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2026-09-17 fix(cad): vendor Liberation Sans so the lid emboss is machine-independent
    Q10: Arial came from whichever font OCCT found. Point the emboss at
    fonts/LiberationSans-Regular.ttf (OFL-1.1). Only the three lid hashes change.
    [lid.3mf, lid.step, lid.stl]
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2026-09-17 feat(fab): prove Stage B packing and issue interface v2
    VQFN-32 plus a BAV199S array fit the board at Nominal courtyards.
    No published 501015 folded pack meets the pocket envelope.
    [test_cad.py, test_placement.py]
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2026-09-17 review(WP3): regen test compares the whole manifest; README tested versions
    The regen test compared hashes, checks and commit only, so a manifest
    missing notes the writer now records (emboss_font) passed. It now
    compares every key except views. The render test also compares the
    views map with the committed one.
    README: how the renderer works, the debug page PNG, the numpy,
    matplotlib, pypdf and trimesh versions the hashes were made with, the
    two-step commit a solids change needs, and that placement.svg is not in
    views (also in the manifest.py schema text).
    Claude-Session: https://claude.ai/code/session_01TYFHz4CJaHxhTcDUtaYigH
    [test_cad.py]
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2026-09-17 review(WP6): lug tabs in the free mask, two clamp arrays, packing not confirmed
    Round 1 confirmed packing on a mask without the signal lug tabs, a 4.50
    VQFN courtyard (RSM body max is 4.10, so 4.60) and one BAV199S-Q, which is
    two independent pairs for three lines; its array also sat under the REF
    pad and the reference wire entered keep-out 2 by 0.63. placement.py now
    counts the tabs, places parts only at legal sites, lists every broken rule
    in layout_conflicts(), prints them on the drawing, and measures the RF
    distance at the reserved 15.8 module (4.70, not 5.00). The wire goes round
    keep-out 2. interface.md: packing not confirmed with the ten conflicts,
    pads and V2-4 reopened, SOT-23 3.3 x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
    [test_placement.py]
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2026-09-17 feat(fab): relayout packing options on the TE 31428 lug
    Q13 short tabs are not a SKU. SIG1 and SIG2 use the C-31428 barrel, flat, aimed +u and −u so option A closes on the plan shell.
    [test_placement.py]
2026-09-17 feat(fab): pack options on the TE 31428 tab from the Ø7.1 edge
    Q13 short tabs are not buildable with a crimp lug. Direction search aims the 6.27 mm barrel; only option C closes. Stop tracking .reports/.
    [test_placement.py]
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2026-09-17 review(WP6b): check lead exits, corner pads and 0402 sites; relay out every option
    The WP6b layouts aimed each TE 31428 barrel end at a side wall (A/E SIG2 at
    170° ends 0.13 mm from u 1.5, SIG1 at 355° 0.78 mm from u 15.5), where the
    crimped lead cannot leave at the plan §3.3 3 mm bend radius. The reference
    wire ran through the high-u corner pad. layout_conflicts() did not count
    the 15 unplaced 0402s, and the drawing drew rotated 0402s unrotated, off
    the board edge.
    - Lead exit (LEAD_BEND_R), lead run to its pad, and wire-to-wall, rib,
    keep-out, corner-pad and barrel clearances are checked in the search and
    in layout_conflicts(). Wires may cross only where no part or other net's
    pa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
    [test_placement.py]
2026-09-17 review(WP6b): rewrite the packing sheet on the checked layouts; one errata row
    The sheet said A closes and recommended A, with 15 of 25 0402s unplaced and
    both barrels aimed at walls. On the checked layouts only C closes. The sheet
    now says so in its first line, gives one row per option, recommends C with
    the two things C needs (moved pads, one reference-wire crossing), and why
    A, B and E fail. The interface keeps one WP6b errata row (the lane wrote
    two) and the §12 V2-4 pointer.
    Claude-Session: https://claude.ai/code/session_015FeLVCWV8Sqj7XoABGLHSn
    [test_placement.py]
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2026-09-17 review(WP8-prep): refuse Stage B keys on order 1 and contacts placement did not search
    The lane made PACKING, CONTACT_*, CABLE_EXIT_S, TAB_HEIGHT and
    CLOSURE_PASSED overridable for every build, then derived_params dropped
    them when MOCK_CONTACTS was true: --set CONTACT_1_U=7 built the plan
    gauge with no error (round 1 defect 5 again). They now fail on order 1.
    Stage B read pads, tab angles and the reference route from placement.py
    but let CONTACT_1 move freely; those layouts were searched for the plan
    sites only (placement.CONTACT_1, CONTACT_2, and point_tab_gap uses them).
    PLACEMENT_contacts fails with the drift until placement is re-run.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
    [test_cad.py]
2026-09-17 review(WP8-prep): measure the Stage B checks on the solids; report a non-passing build
    The named Stage B checks were constants or tautologies (round 1 defect 4
    again): the keep-out cylinders and tab envelopes were cut out of the body
    and then probed for air, CELL_envelope compared constants and passed a
    thin body whose lid overlaps the cell by 178 mm³, CABLE_EXIT_cavity
    compared s ranges and passed an exit that cuts 0.99 mm³ out of the
    inferior posterior corner pad, REF_WIRE_envelope returned a fixed 1.0
    cavity margin and named the corner pads charge pads, and they ran on
    body_full_p15 only.
    Now each check measures the built body and seated lid: removed volumes
    at each cut, overlap volume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
    [test_cad.py]
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2026-09-18 board(v2): add kicad-cli release job and unittest
    Fail closed on ERC errors or missing gerber, BOM, CPL, STEP or summary outputs.
    [test_board_release.py]
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2026-09-18 board(v2): flex layout for interface II from WP11 winner
    WP11 closed interface I at 0 runs, so the board is the 2-layer flex with ring-pad tabs on A_501015_series_w20.
    [elicio-v2.kicad_pcb, elicio-v2.kicad_sch]
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2026-09-18 review(WP11): one packing truth; standoff stack; antenna pose; measured doc
    - Foam 0.5 in packing and Stage B (was 0.3 in packing, 0.5 in CELL_envelope).
    - Interface II: ring 0.31 + brass standoff 3.0 = board underside 4.81; the
    flex rests on the standoff tops (was nut stack 4.0, 0.5 below the standoff
    top the board had to cover). FR4 stiffener 0.4/0.2 from JLC's list (no 0.3).
    - Standoffs and tabs are floor occupants; a standoff through the board
    underside is a conflict. Free area subtracts placed top-face courtyards.
    - Antenna keep-out follows the module pose (length along u: 3.8 along u at
    the low-u end), as WP12's second zone; placers avoid it.
    - Board BOM packages: no BAV199; US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
    [test_cad.py, test_placement.py]
2026-09-18 review(WP13): RESP2 0x07, CH2 off, WP12 thresholds, contiguous frames, VBUS pins
    - RESP2 0x02 -> 0x07: RESP_FREQ and bit 0 must be written 1 on the ADS1292
    (SBAS502C 8.6.1.11). CH2SET 0x60 -> 0x81: unused channel powered down
    with its input shorted (Table 22 note 1).
    - V_STOP/V_START 2700/2800 placeholders -> 3000/3200 mV, board-v2.md §6.
    - STREAM frames stop at the first gap in the ring's acq indices; the frame
    after a gap carries OVERRUN (frame-v2: samples are consecutive DRDYs).
    - VBUS present: no SPI to the switched-off AFE; SCK, MOSI, CS, PWDN, START
    go high-impedance until acquisition restarts.
    - firmware-v2.md: register table, REGOUT0 = 3.0 V needed on the product
    board (VI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
    [ads1292.c, elicio_stream.ino, test_frame_v2.py]
2026-09-18 review(WP12): ISET, LED, divider, ERC 0/0, RF keep-out, routed flag, record
    - ISET: R25 + R28 (20 k to GND) sat in parallel with RISET 6.80 k, so
    IOUT was about 26.6 mA, not 19.85. R28 now pulls LED_EN down; R25 alone
    feeds the high-impedance AIN7.
    - LED: Q4's gate moves from ISET (about 1 V) to LED_EN (P0.04, pin 20);
    anode from VBUS, not VBAT, so it no longer loads the charger output.
    - Battery divider: R21 to GND, Q5 DNP. The low-side switch left P0.02 at
    VBAT through 1 MΩ when off, above VDD + 0.3.
    - ERC 0 errors, 0 warnings: mismatched symbols moved into lib/elicio as
    their embedded copies (netlist unchanged); J3 footprint library name.
    - PCB: removed the length-along-s RF ru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
    [elicio-v2.kicad_pcb, elicio-v2.kicad_sch]
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2026-09-18 shell(v2): cut REF_end_wall_slot from packing-v2 §5
    WP11b at 71fa9ea found no in-cavity REF route, so Q59 is the named
    end-wall slot plus 0.20 mm flex clearance, with remaining wall ≥ 1.0.
    [body_full_p15.3mf, body_full_p15.step, body_full_p15.stl]
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2026-09-18 review(WP12b): routed is false on a refused release; placement test reads packing-v2 §5
    release.py wrote "routed": true whenever --routed was passed, also when it
    refused the release (1290 DRC errors, 31 unconnected). summary.json now
    carries routed (true only when a --routed release passed), routed_requested
    and the refused blockers. The placement-agreement test hard-coded the
    packing centres; it now parses packing-v2.md §5 and checks the REF ring too.
    Claude-Session: https://claude.ai/code/session_01XMFSYZyhYXQZZaQMuprNYS
    [test_board_release.py]
2026-09-18 review(WP13b): one settling window per RESTART; receive-check exit codes follow montage §8
    _dropout_stretches kept only the last RESTART and then skipped every
    sample before it, so a restart late in a session hid all earlier dropouts
    (old code: 0 stretches for a 205-sample flat run followed by a RESTART).
    Each RESTART now excludes its own 200 conversions. "More than 200 sample
    intervals" counts intervals (k samples = k-1 intervals), not samples.
    receive-check: 1 = a scored same-criterion line (3.5-3.10) failed,
    3 = a line 3.4 dropout (montage marks 3.4 "revised"), 2 = not a session.
    The table is in receiver-v2.md. The tests read the committed fixtures and
    check them against the generators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
    [receiver_v2.py]
2026-09-18 review(WP11b): placement v2 drawing tests skip without matplotlib; sheets extra; skip messages name the extra
    The base venv ran 18 PlacementV2Tests errors (render_svg raises without
    matplotlib). Those five tests now skip under NEEDS_MATPLOTLIB. pyproject
    gains a sheets extra (matplotlib, pypdf) for the phone sheets and the
    drawings without the CAD kernel.
    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
    [test_cad.py, test_placement.py]
2026-09-18 review(WP14): captive hex wells, honest shell checks, no v1 cable exit on the shell
    - Hex well AF 5.30 alone (5.00 A/F max + 0.3 print; locks below 5.77
    across the standoff's corners). The lane cut AF 6.3 plus a Ø7.4
    cylinder that swallowed the hex, and the packing 5 × 5 boxes, so the
    standoff could turn and the collar flats were 0.2 thick. Collar AF 8.4,
    ring seat Ø6.4 (Ø6.0 flex outline + 0.10 + 0.3). REF gets the slot's
    clearance through its collar.
    - V2_STANDOFF on the shell measures a 5 AF prism and the well's flats and
    corners. V2_RING_seat measures the seat diameter.
    - V2_USB_end measures the hook on the face (built in the body frame) and
    the receptacle mouth against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
    [body_full_p15.3mf, body_full_p15.step, body_full_p15.stl]
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2026-09-18 review(r6): verdict MERGE-AFTER-DECISION, gates, defects, §7 look, decisions 69–76
    Also numbers the receiver's 3.4 pointer as decision 75, corrects the
    shell-v2 wording (the board is not routed) and a well comment
    (circumradius 3.64 for the lane's AF 6.3).
    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
    [receiver_v2.py]
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2026-09-18 review(WP12b): release job and its test read and write UTF-8 explicitly
    Run after test_cad in one process (OCCT sets the C locale), the placement
    test's bare read_text() decoded the PCB as ASCII and errored. Every read
    and write in release.py and test_board_release.py now names utf-8.
    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
    [test_board_release.py]
2026-09-18 review(r6): coordinator note 2: re-pack with real courtyards is decision 70; zero-track DRC confirmed
    At 845bac7 with zero tracks kicad-cli DRC reports 128 errors and 132
    unconnected: footprints collide because the packing envelopes are
    smaller than the courtyards. Recorded as decision 70 in code-r6.md,
    with a pointer in board-v2 (outside §15) and a defects row for the
    placement test. The earlier decisions 70–76 move to 71–77 in every doc
    that cites them; shell v2 views re-rendered for the label numbers
    (solids unchanged). lane/w3 at 952407d was already merged. release.py's
    routed flag was fixed in 9d702f0.
    Claude-Session: https://c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
    [receiver_v2.py]
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2026-09-18 packing(v2c): pin table meets copper-to-edge; holes not under U1
    WP12d cannot pin a table that fails the rules it is checked against. D1, C3, C10, C11 and C12 sit inward of 0.30 mm.
    [test_placement.py]
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2026-09-18 packing(v2e): flat pattern in PCB coordinates and J4 NPTH keep-out
    SIG1/SIG2 ring pads leave the island neck on the flat board so they no longer sit inside U1. J4's NPTH holes keep B.Cu clear on the no-receptacle cell.
    [test_placement.py]
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2026-09-18 packing(v2e): move P4/P5 onto the flex tail inside the cavity
    Wall sites at u 0.75 / 21.25 put Ø5 pads in the 1.5 mm walls and broke
    pad-to-outline 0.30. The tail sites sit in cavity u with the REF and
    screw-well clearances the shell already uses.
    [test_placement.py]
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2026-09-18 board(v2f): move R24 off J4 NPTH (Q87); flex netclasses in the DSN path
    R24 +0.47 mm u clears hole clearance 0.20 on the real TC2030 hole. Zero-track DRC is 0. Default/Contact classes are JLC 1 oz 0.10/0.10 and 0.15/0.20; via 0.70/0.30. scripts/board/route_v2.py checks those class blocks after DSN export.
    [elicio-v2.kicad_pcb]
2026-09-18 board(v2f): lock SIG/REF strip centres and CHARGE tab stubs
    DSN class blocks carry Default 100/100 um, Contact 150/200 um, via 700:300 um. Wires are Specctra type fix. Island legs to R1–R3 wait for Freerouting; a scripted manhattan still hits Q84 at L1/D2 and shorts the hang.
    [elicio-v2.kicad_pcb]
2026-09-18 board(v2f): R24 off the hole, not routed
    Q84 1.0 mm on the tab roots versus L1, D2 and U1 leaves no legal path from the locked ring stubs onto the island. Freerouting fanout 54.8 %; SES discarded; owned board stays un-shorted.
    [test_board_release.py]
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2026-09-18 board(v2g): Q88 7×7 lands, pin table v2.1 R24, lock Contact to R1–R3
    Shrink tabs/tail_pads to the Ø5 lands plus 1.0 mm. R24 (18.49, 22.57) rot 90 is copper-clean. Locked ring→strip→R1–R3 and charge stubs DRC 0 errors.
    [elicio-v2.kicad_pcb]
2026-09-18 review(WP14): holes, not printed domes, at the contacts and charging pads; closure measured in the lid; §5d read from this repo
    The shell STL fused Ø4.7 × 1.35 nylon ISO 7380 domes over every contact
    hole (round 6, 933e00b). P1–P3 were blind from the skin and the P4/P5
    charging pads sat under a 0.3 web plus a dome, so the titanium screws could
    not go in (plan §8 step 2) and the charger could not reach copper. Plan
    v1 §4: only the gauge prints domes. The body now carries the Ø2.7 holes
    at P1–P3 and open Ø5 holes at P4/P5; V2_RING_seat and V2_CHARGE_pads
    probe the medial face and fail on a cap.
    V2_CLOSURE now measures the M2.5×4 thread in the lid: from the well
    bottom (y 1.55) the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
    [body_full_p15.3mf, body_full_p15.step, body_full_p15.stl]
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2026-09-18 board(v2g): Q88 lands, not routed
    Contact is locked to R1–R3 and Freerouting imported 421 tracks, but 63 nets stay open. Stop un-shorted; routed is false.
    [elicio-v2.kicad_pcb]
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2026-09-18 review(WP14): CAD tests skip by name when any part of the cad extra is missing
    The build classes were guarded on build123d alone. With build123d but no
    trimesh or matplotlib (a venv without .[cad] complete), 24 tests errored:
    STL checks import trimesh and the packing overlays import placement.py,
    which imports matplotlib. Build classes now need build123d, trimesh and
    matplotlib; the pre-CAD Stage B, Stage B v2 and shell overlay classes need
    matplotlib. Measured with import blockers: no trimesh/matplotlib 72 run,
    49 skipped, 0 errors; no build123d 72 run, 22 skipped, 0 errors.
    Claude-Session: https://claude.ai/code/session_01HU59mL5d1hEUG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
    [test_cad.py]
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2026-09-18 review(WP11): undo the R24 packing move; the board moves to v2.1 in WP12g (Q87 closed)
    Reverts 1665216. While this review ran, main recorded WP12g (8348e62 on
    lane/w2): R24 at pin table v2.1's (18.49, 22.57) rot 90 is copper-clean
    on the board, and the coordinator closed Q87 that way. Moving §5d to the
    9049629 site (18.75, 22.37) rot 0 would have opened the gap again.
    packing-v2.md, the w22 c47.90 drawing and layout_v2c.py are back to
    e9fba35's; --packing-doc regenerates them byte-identical.
    The §5d agreement test keeps R24 at the Q87 allowance (0.50, rotation
    not checked) on this tree; every other row is held to 0.1 mm, side and
    rotation. Round 8 tightens R24 when WP12g merges.
    Co-Autho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
    [test_board_release.py, test_placement.py]
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2026-09-18 board(v2h): 63 rats remain, not routed
    Hand-route by script cannot close VBUS, J4 SWD, J3, or U2 without DRC errors: the H1/H2 gap, J4 via slot, and east 0402 row leave less than trace plus twice clearance. WP12g copper stays un-shorted.
    [test_board_release.py]
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2026-09-18 board(v3): RSM land, R9/R10 DNP, Q94 stiffeners, Q97 tests; wait for pin table v3
    U2 pads now match ADS1292 4219108/B (0.40 pitch, 0.55 x 0.20, EP 2.8). U3 stays YFP: the inner balls escape radially so there is no BOM swap. R9/R10 are DNP and off the PCB. Stiffeners sit only on a land-free face (count 9). The §5e parser is ready; it does not replace the vendored table until v3 lands.
    [elicio-v2.kicad_pcb, elicio-v2.kicad_sch]
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2026-09-18 wip(WP12i): v3 land locked; hand_route interrupted
    Pin table v3 is pinned and Contact strips are locked. A* on island
    rats failed DRC. VBUS/nRESET tracks from an interrupted run sit on
    the board; DRC was not re-run.
    [elicio-v2.kicad_pcb]
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2026-09-23 board(v4): W18 placement and locked pre-routes; not routed
    elicio-v4.kicad_pcb is placed at W18 (W17 left too little B-side area for
    the divider/interlock parts with via escape). 61 footprints, 0 keep-out
    problems, every pad has a net. Locked pre-routes: SIG1/SIG2/REF strips to
    R1-R3, the J3 branches on F (REF on B), charge nets across the joint on B
    with the charger (U3) on B, nRESET round J4 to J4.6 and SW1, +VDD to J4.1,
    the RF bridge and U1's inner VSS.
    Schematic: R26 removed (P0.18 RESET has its own pull-up; firmware sets
    UICR PSELRESET), pin map A on U1's east column, J3 pin order reversed so
    the branches do not cross. ERC 0. Via rule 0.40/0.15 (JLC flex standard).
    release.py takes --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
    [elicio-v4.kicad_pcb, elicio-v4.kicad_sch]
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2026-09-23 board(v4): every net but GND routed, GND pours filled; NOT routed
    elicio-v4.kicad_pcb: all nets except GND are routed (961 segments, 45 vias
    with the locked pre-routes) by v4_route_pf.py; both GND pours are filled.
    kicad-cli DRC: 0 shorts, 0 clearance errors, 13 starved_thermal errors
    (GND pads) and 36 unconnected items, all GND (37 GND pieces). release.py
    --routed was not run and would refuse. Do not order.
    - build_v4.py: C14 turned so its VBAT pad faces east; with it facing west
    VBAT walled off AFE_VIN on B (the last two-net conflict).
    - board-v4-design.md: §9 routing status (router results, placement reliefs,
    every open GND join with pads and mm, next steps, rebuild commands);
    §1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
    [elicio-v4.kicad_pcb]
2026-09-24 wip(board v4): bench 220k on the J3 tab, VSS vias, folded tables; PCB not rebuilt, not routed
    Design and generator changes only. hardware/board/elicio-v4.kicad_pcb is still
    df6ae3a's board (GND in pieces, J3 Contact branches), so tests/test_board_v4.py
    fails against it until the board is rebuilt and routed.
    - v4_parts.py: J3 carries bench nets BENCH_SIG1/SIG2/REF behind their own 220k
    R31-R33 on the break-off tab (R7, Q97(d)); U1 VSS pads 14/16/18 on GND;
    consigned parts (U1, U5, J2) say CONSIGNED in the LCSC field.
    - build_v4.py: tab u 20.1-33.4 x s 16-28, R31-R33 placed, AFE-side neck runs
    on F (s 20.40/21.15/21.90), two locked GND vias between U1 pads 14/16/18
    at u 6.70 (0.05 out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
    [elicio-v4.kicad_sch]
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
